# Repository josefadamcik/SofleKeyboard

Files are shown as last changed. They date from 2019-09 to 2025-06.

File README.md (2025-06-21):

# Sofle Keyboard

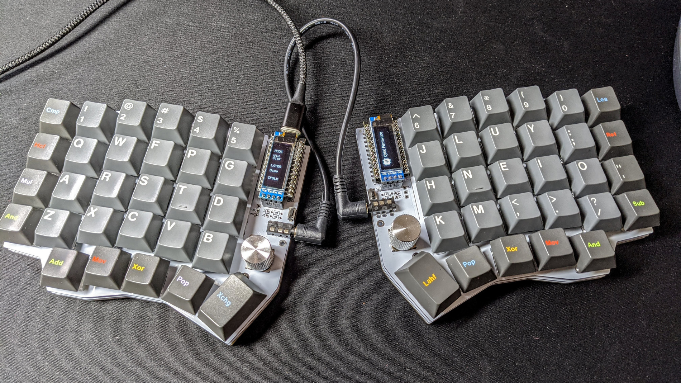
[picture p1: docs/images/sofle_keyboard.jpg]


Sofle is 6×4+5 keys column-staggered split keyboard with encoder support. Based on [Lily58](https://github.com/kata0510/Lily58), [Corne](https://github.com/foostan/crkbd) and [Helix](https://github.com/MakotoKurauchi/helix) keyboards.

**[For more information and documentation visit https://josefadamcik.github.io/SofleKeyboard/](https://josefadamcik.github.io/SofleKeyboard/)**

SofleKeyboard was created by [Josef Adamcik](https://josef-adamcik.cz/). The motivation and process is covered in following blog-post: [Let me introduce you SofleKeyboard - a split keyboard based on Lily58 and Crkbd](https://josef-adamcik.cz/electronics/let-me-introduce-you-sofle-keyboard-split-keyboard-based-on-lily58.html)



Sofle RGB was contributed by [Dane Evans](https://github.com/DaneEvans).

Sofle soldered was contributed by [kb-elmo](https://github.com/kb-elmo)

Sofle Pico was contributed by [Ryan Neff](https://github.com/JellyTitan)

## Firmware 

Sofle uses [QMK firmware](https://qmk.fm/)

## Default layout 

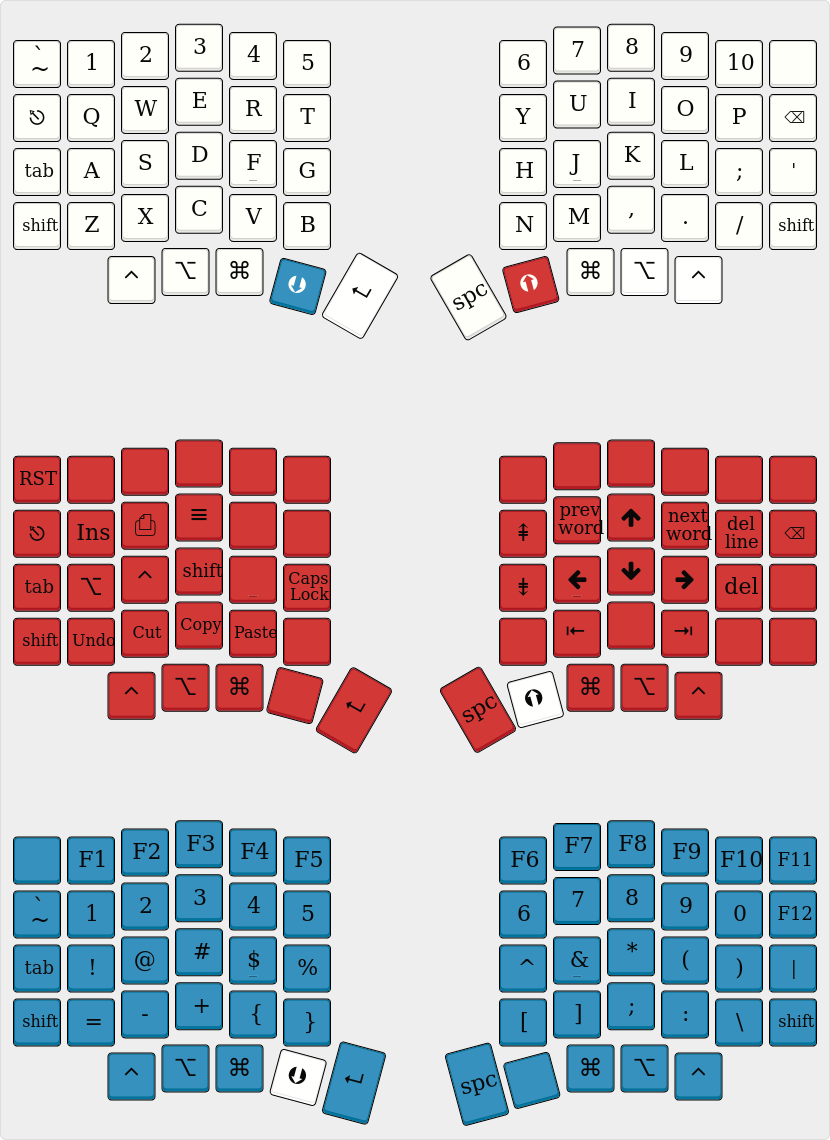
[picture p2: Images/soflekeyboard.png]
Default layout for SofleKeyboard


## Images of keyboard

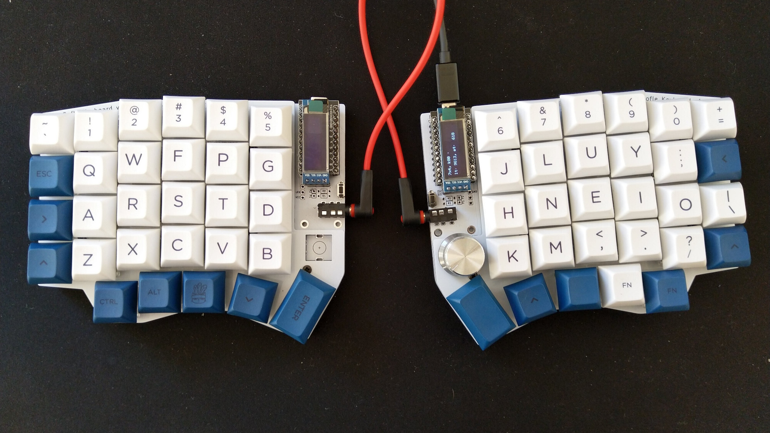
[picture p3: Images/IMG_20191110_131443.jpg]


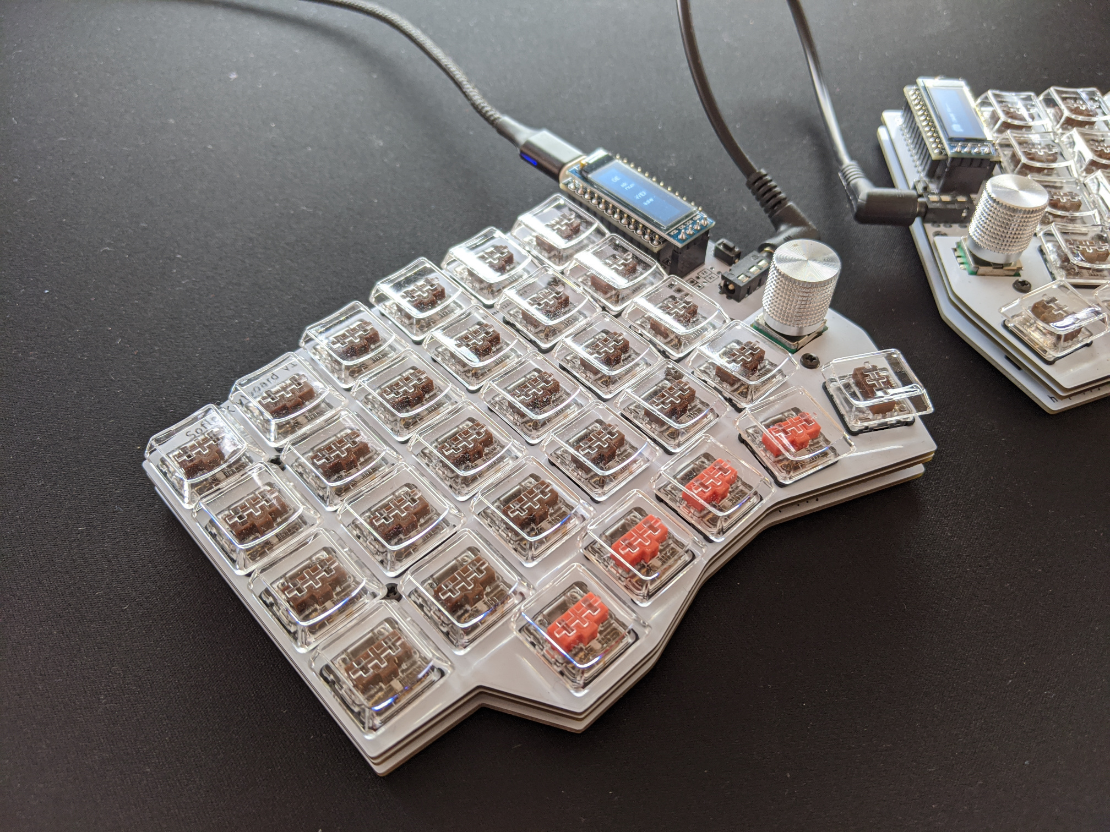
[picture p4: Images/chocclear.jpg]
SofleKeyboard Choc


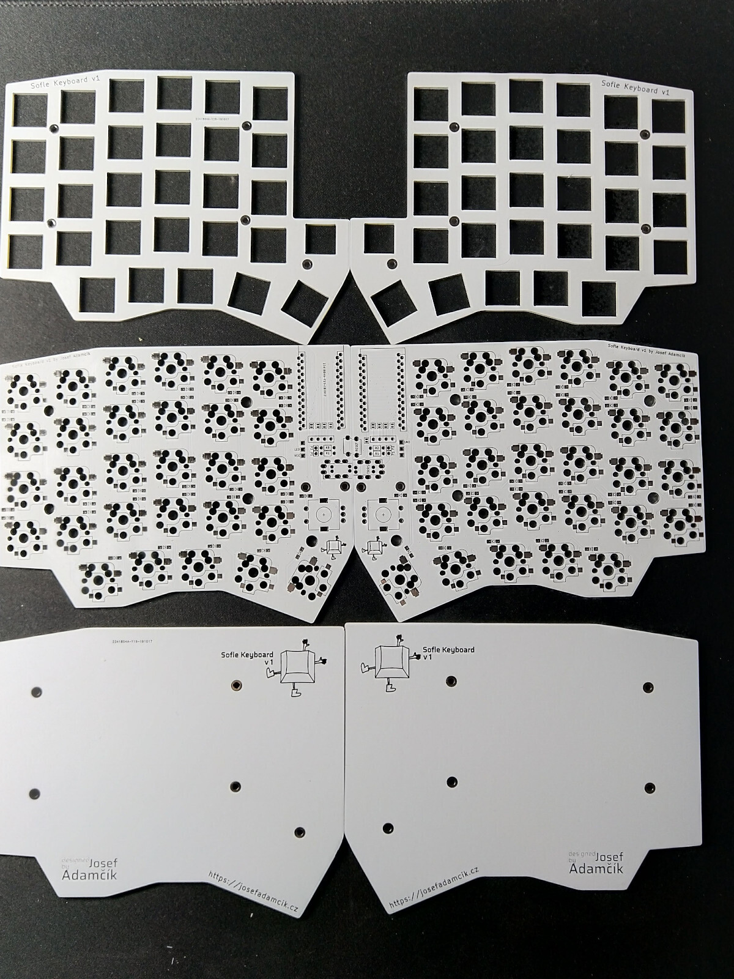
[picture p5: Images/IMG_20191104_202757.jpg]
SofleKeyboard PCB


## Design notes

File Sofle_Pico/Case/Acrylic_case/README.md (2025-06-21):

The documentation for this case can be found at https://www.soflepico.com/cases/fdm-case.html

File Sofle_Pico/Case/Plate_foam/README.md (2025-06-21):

The documentation for this case can be found at https://www.soflepico.com/cases/plate-foam.html

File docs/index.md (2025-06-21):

---
layout: default
---

SofleKeyboard

Sofle is 6×4+5 keys column-staggered split keyboard with encoder support. Based on [Lily58](https://github.com/kata0510/Lily58), [Corne](https://github.com/foostan/crkbd) and [Helix](https://github.com/MakotoKurauchi/helix) keyboards. SofleKeyboard version 1 and 2 were created by [Josef Adamcik](https://josef-adamcik.cz/). Sofle RGB was contributed by [Dane Evans](https://github.com/DaneEvans).

[Build guide is available here]({{ baseurl }}/SofleKeyboard/build_guide.html).

If you are interested in building the board and don't want to bother with KiCad, the gerber files are available in [releases](https://github.com/josefadamcik/SofleKeyboard/releases) or as [zip files in github repository](https://github.com/josefadamcik/SofleKeyboard/tree/master/Gerbers)

## Versions 

### Version 1

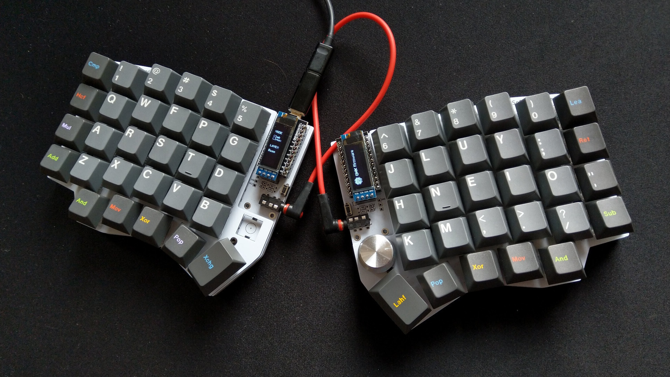
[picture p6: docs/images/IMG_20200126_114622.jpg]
SofleKeyboard v1


The first version is mostly a modification of Lilly58 Pro. Motivation and detailed information is covered in the following blog-post: [Let me introduce you SofleKeyboard - a split keyboard based on Lily58 and Crkbd](https://josef-adamcik.cz/electronics/let-me-introduce-you-sofle-keyboard-split-keyboard-based-on-lily58.html). 

There were several group buys and PCBs or kits were available through several sellers. 

[Build guide is available here]({{ baseurl }}/SofleKeyboard/build_guide.html).

### Version 2

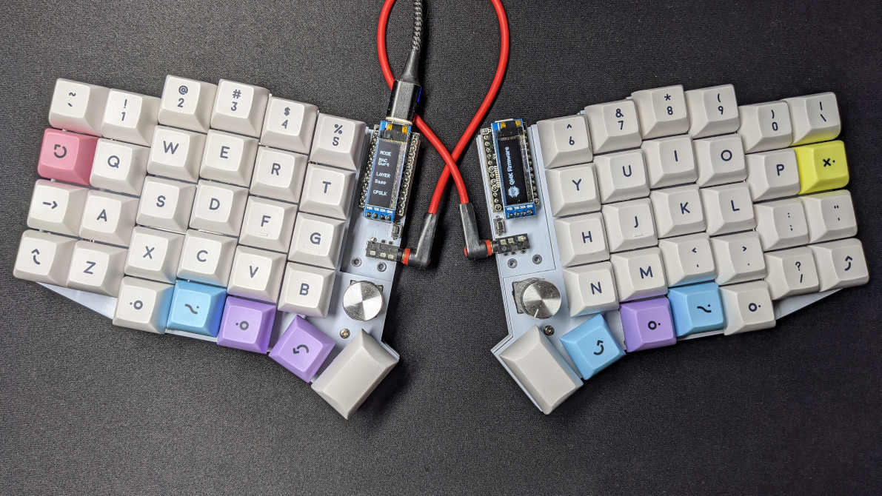
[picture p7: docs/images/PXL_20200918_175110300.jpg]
SofleKeyboard v1 and v2


Changes a stagger of columns and position of the bottom row a bit. The whole board was rerouted, shape changed slightly. Below version 1 in yellow, version 2 in blue.

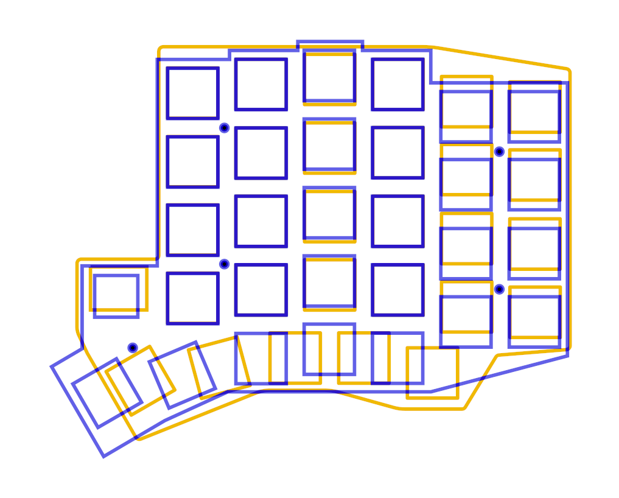
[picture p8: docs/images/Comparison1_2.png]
SofleKeyboard v1/v2 layout comparison


A few experiments were made:

- A differently mounted micro-controllers with staggered holes.
- Placement of components around pro micros were also changed.
- Support for low profile Kailh Choc switches was dropped.

Those changes were experiments and I have been planning to reverse them and/or tweak them more. Details in the following blog-post: [Sofle Keyboard evolution: slow and not really steady](https://josef-adamcik.cz/electronics/soflekeyboard-evolving.html). 

Since the development was not moving forward for several months and there were many people interested in the new layouts (including group buys and vendors willing to sell kits), it was decided to release it in the current state as the version 2. Only one obvious problem was fixed (a too small size of a cut-out for encoder in the top plate).

[Build guide is available here]({{ baseurl }}/SofleKeyboard/build_guide.html).

### RGB

**&#9888; If you bought Sofle RGB from Keyhive, see the disclamer below, please.**

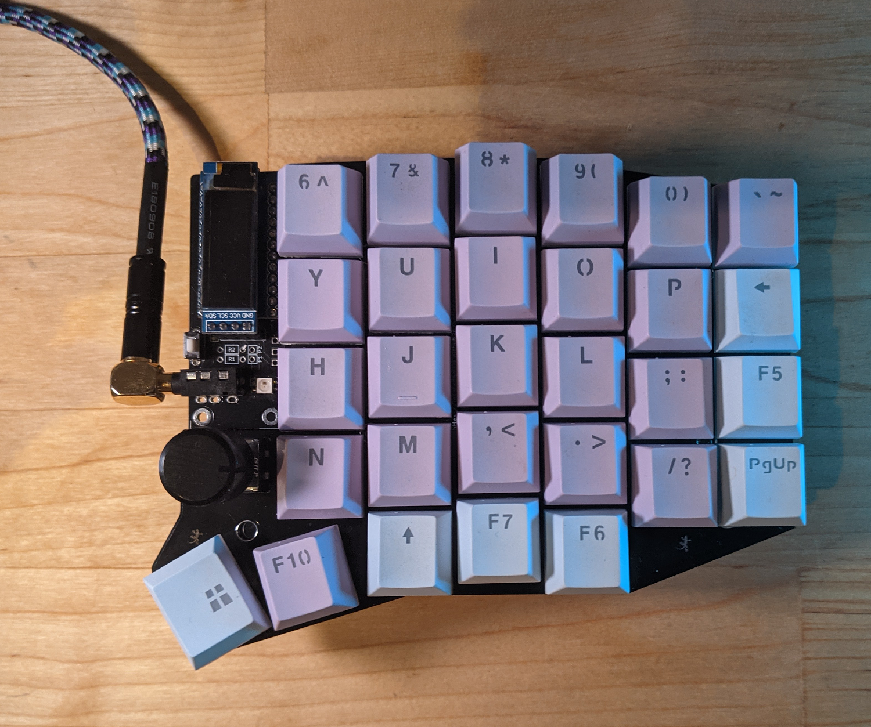
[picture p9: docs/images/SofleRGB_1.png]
SofleKeyboard RGB


Sofle RGB was contributed by [Dane Evans](https://github.com/DaneEvans).

The Sofle RGB is a copy of the Sofle v2 with the addition of up to 36 RGB LEDs per side. If you are just looking to try out that layout, and are using the cherry sockets only, then this will work for you. 

The original pro-micro pinout was rolled back and routing was redone.

The OLED placement and OLED cover plate holes have not changed, and a plate has been designed. 

[Build guide is available here]({{ baseurl }}/SofleKeyboard/build_guide_rgb.html).

###	&#9888; Keyhive RGB

One keyboard vendor - Keyhive - is selling their own fork of Sofle RGB. This version is **modified** in way that makes it **incompatible** with the firmware for the official designs. You have to use the firmware provided by the vendor and build guide provided by them as well. Please, don't report problems with the desing and or firmware to this repository. Their modification is not part of the repository and therefore we cannot fix the problems or help you. Contact the vendor instead. In the end, you are their client.

[Build guide is available here]({{ baseurl }}/SofleKeyboard/build_guide_rgb.html).

### Choc

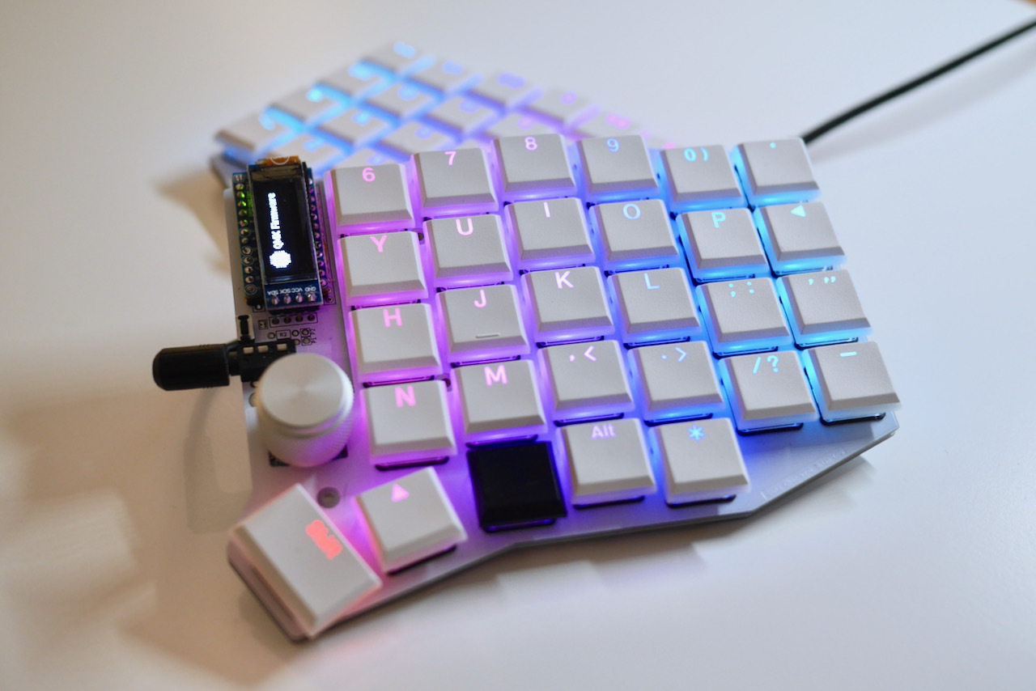
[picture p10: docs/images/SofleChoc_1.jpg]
Sofle Choc


The Sofle Choc is a variation of the Sofle with:

   - low-profile, Kailh Choc switches
   - hotswap sockets
   - per-key RGB
   - thin, 15mm from desktop to top of keycaps
   - Sofle RGB switch layout with pinky stagger in between v1 and v2

The Sofle Choc was contributed by [Brian Low](https://github.com/brianlow) and based on the excellent Sofle RGB by [Dane Evans](https://github.com/DaneEvans).

[Build guide is available here]({{ baseurl }}/SofleKeyboard/build_guide_choc.html).

### Pico

Sofle Pico

The Sofle Pico is based largely on the Sofle V2 switch layout, and rebuilt specifically for the RP2040 Pico MCU. 

   - MX switch hotswap sockets (does _not_ support choc switches).
   - per-key RGB
   - 64x128 OLED's
   - through-hole or SMD diodes for easier soldering
   - RP2040 'drag and drop' flashing
   - VIA support
   - tenting puck mounting holes
   - patch bay for easy tinkering

Sofle Pico was contributed by [Ryan Neff](https://github.com/JellyTitan).

[Build guide is available here](https://www.soflepico.com).

## Modifications

- [Sofle V2 with RJ12 instead of TRRS](https://gitlab.com/LayeredRx/Sofle_V2_Rj12/) by Layered RX

## License

- Hardware source files are licensed under MIT license.
- The documentation (both on [josefadamcik.github.io/SofleKeyboard/](https://josefadamcik.github.io/SofleKeyboard/) and [https://josef-adamcik.cz/](https://josef-adamcik.cz/)) is licensed under [Creative Commons Attribution 4.0 International (CC BY 4.0)](https://creativecommons.org/licenses/by/4.0/) license. This includes all photos and images in this repository and on the website.
- Firmware is part of QMK firmware and has the same licence (GPL v2)

## Firmware 

Sofle uses [QMK firmware](https://qmk.fm/)

See the [build environment setup](https://docs.qmk.fm/#/getting_started_build_tools) and the [make instructions](https://docs.qmk.fm/#/getting_started_make_guide) for more information. Brand new to QMK? Start with our [Complete Newbs Guide](https://docs.qmk.fm/#/newbs).

Make example for this keyboard (after setting up your build environment):

    make sofle:default

Flash the default keymap: 

    make sofle:default:avrdude

Press reset button on he keyboard when asked.

Disconnect the first half, connect the second one and repeat the process.

You can also use [QMK configurator](https://config.qmk.fm/#/sofle/rev1/LAYOUT) but beware, it does not support rotary encoders yet.

## Default layout 

Default layout for SofleKeyboard

## Gallery

Version 1 at the top, version 2 at the bottom:

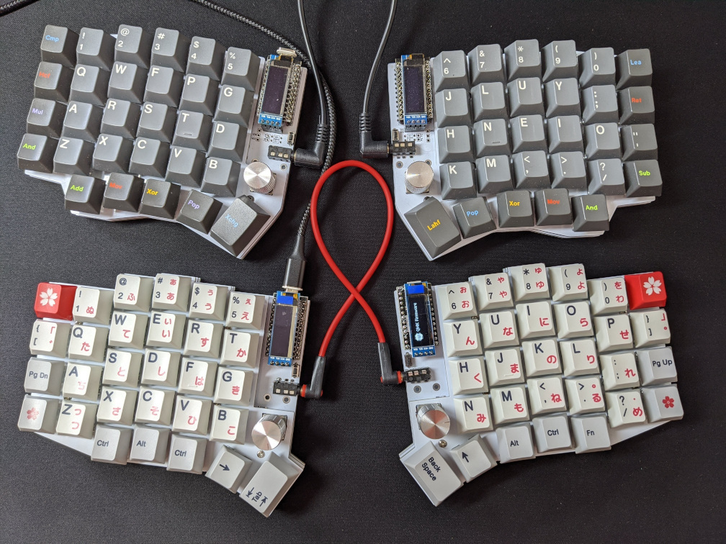
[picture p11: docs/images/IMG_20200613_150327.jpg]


### Version 1

SofleKeyboard

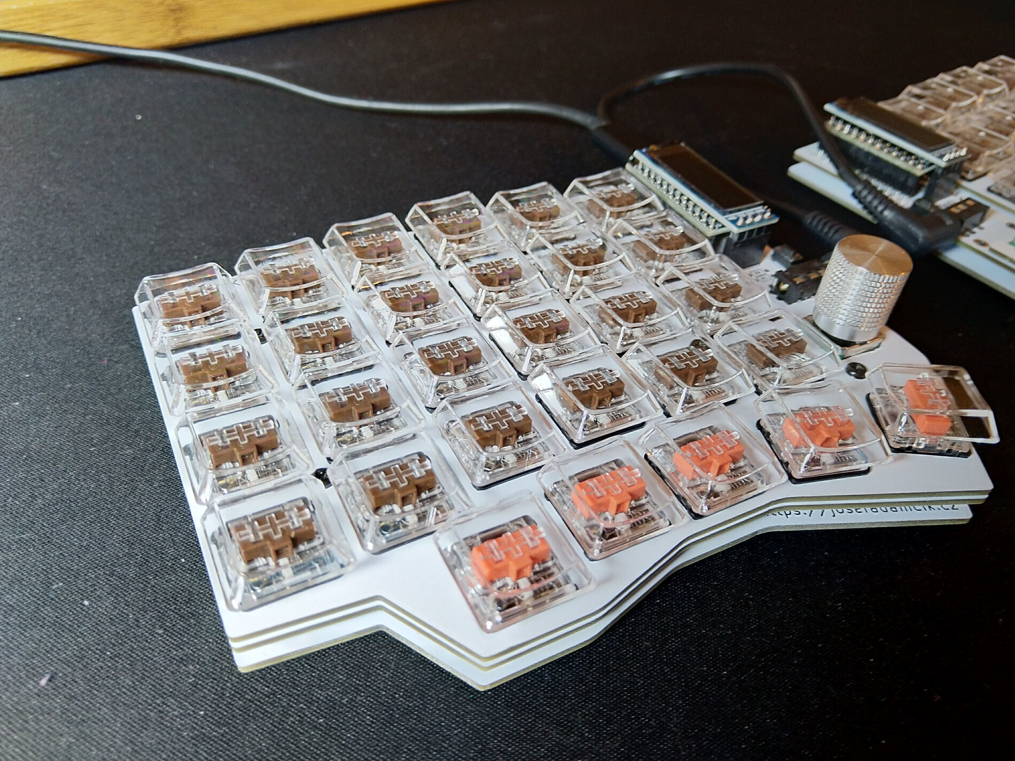
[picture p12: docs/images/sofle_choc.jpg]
SofleKeyboard Choc


SofleKeyboard PCB

### RGB

SofleRGBKeyboard

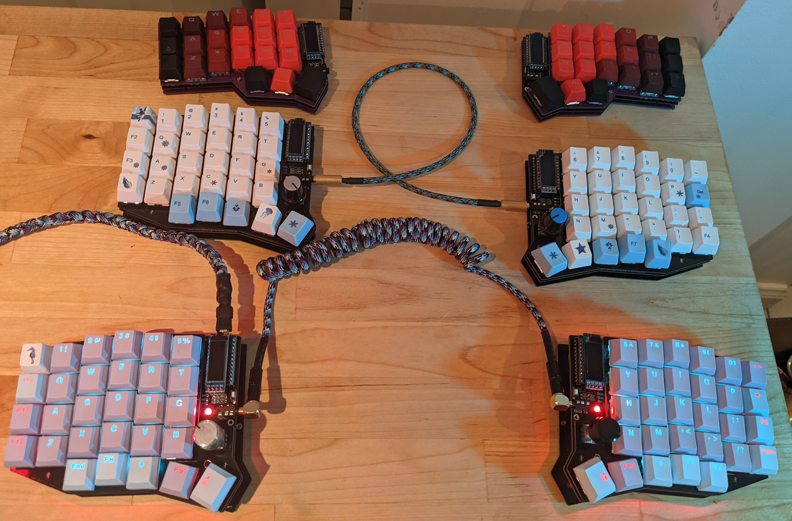
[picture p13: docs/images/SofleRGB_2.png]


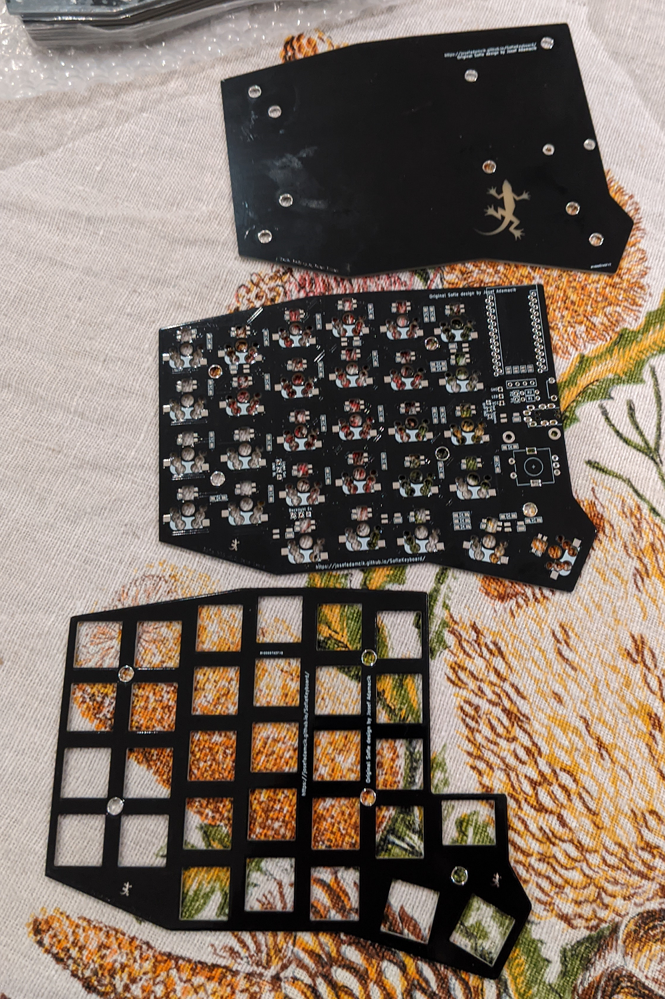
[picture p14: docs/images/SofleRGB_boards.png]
SofleRGBKeyboard PCB


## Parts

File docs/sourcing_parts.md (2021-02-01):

---
layout: default
title: Sofle Keyboard - sourcing parts
---

Sofle Keyboard is supposed to be simple DIY keyboard so it's possible to source all the parts yourself starting with PCBs, case plates and ending with every component on the board. In the case of PCBs and plates it might be more cost effective to buy them through a vendor but it's possible to go through manufacturing process as well. For the remaining components, most of them can be bought on Ebay on Aliexpress but buying a kit might be handy.

## Vendors

There are some vendors who are or were selling Sofle PCBs and/or kits. Things change over time so just google around and you may have luck finding someone.

## PCB manufacturing

If you decide that you wish to go through the PCB manufacturing process, you can. I should be easy enough even for people who don't know much about PCB manufacturing process. But keep in mind, nobody can guarantee that there are not going to be some problems and if you have no idea what are you doing it might be more difficult to deal with any issues along the way. 

### Getting Gerber files

The shortest way is to grab the [Gerber files for SofleKeyboard from releases Github][soflegerber].

You can also get source [KiCad projects on Github][soflegithub]. Open them in KiCad, plot Gerber files and drill files, compress them into a zip file. The instructions how the extract Gerber files from KiCad are everywhere and you can find them e.g. at the website of your chosen manufacturer. 

### Manufacturing

You should have 3 zip files which you need to upload/send to your manufacturer and have them made. There should be nothing special about the parameters you pick for manufacturing: 2-sided PCB, thickness 1.6 mm. Surface finish (keep in mind that the cheapest HASL contains lead. Lead is toxic. Consider using lead-free version and lead-free solder) and solder-mask color according to your taste. Other parameters could stay in their default values. You are going to need at least 2 pieces of PCB made from each zip file. Most likely the minimal quantity is going to be either 5 or 10 boards.

## Microcontroller boards

- [Original Pro Micro by SparkFun][promicroorig]. 
- [Clone from AliExpress][promicro]

Another alternative would be to use Elite-C which is a board using the same microcontroller as Pro Micro but with USB-C designed and made for DIY keyboards by [keeb.io][keebioelite]

### Sockets and pin headers for Pro Micro 

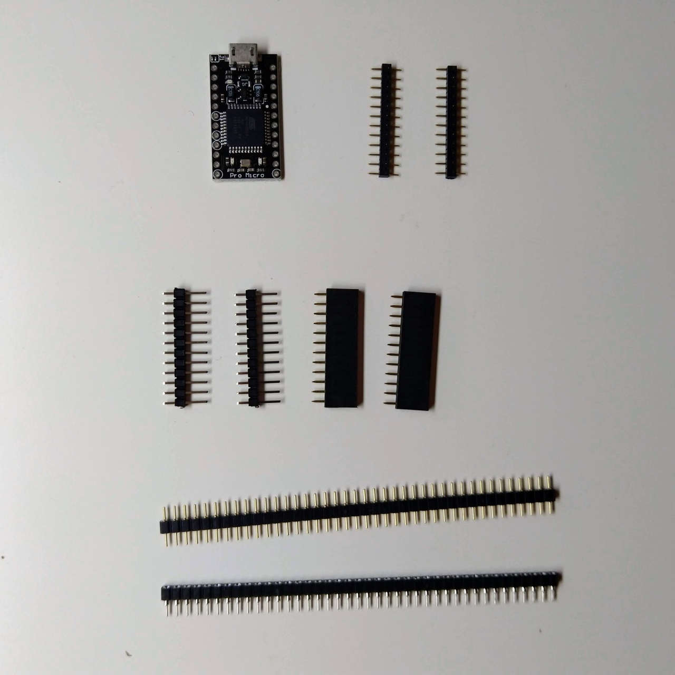
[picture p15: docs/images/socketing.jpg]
sockets


There are several ways how to mount Pro Micros to the board. Either the male PIN headers you most likely got with the board from the supplier could be used to solder it directly to the board or with high profile female pin headers (on the image in the middle.)

Build guides for Helix, Corne and Lily58 suggest [those spring pin headers][springpinheader](on the image at the top) which are very compact and give you non-permanent connection (you can remove or replace Pro Micros). But the link goes to a Japanese e-shop which is not shipping to Europe. ~~I haven't found any other place where those are available. All I can find is Japanese datasheet and this e-shop.~~ They were [briefly available at keycapsss.com][keycapsssockets] but at the time of writing they were already sold-out.

I ended up using low-profile round pin headers (on the image at the bottom) which take a bit more height but also allow me to remove Pro Micros and use them elsewhere. But for Corne, I just soldered them permanently. Here are [female ones][roundpinfemale] (soldered to board) and [male ones][roundpinmale] (soldered to Pro-Micro)

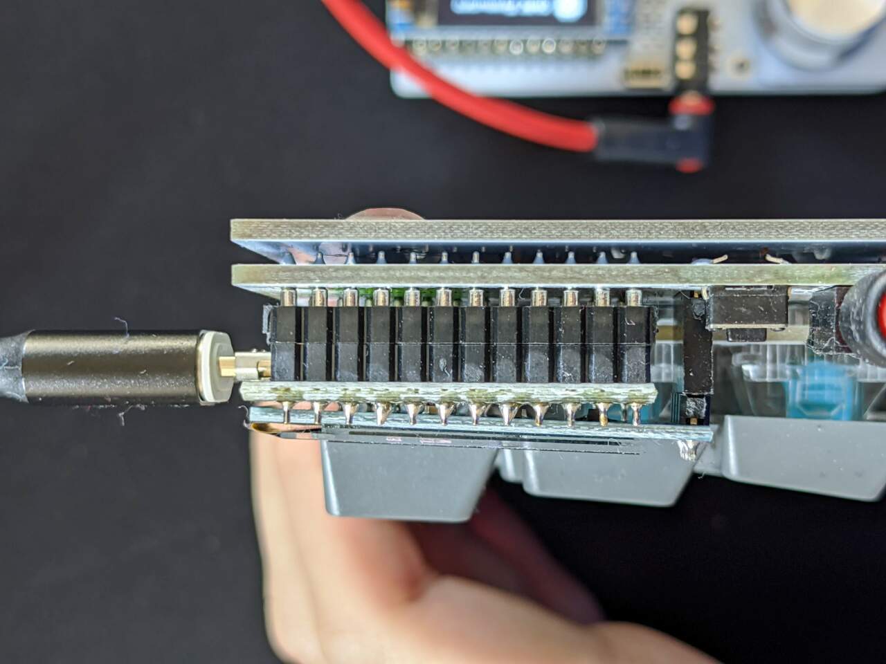
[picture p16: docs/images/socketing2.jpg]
sockets 2


Another possible approach [is described at splitkb.com][promicrosocketing].

## Other parts

Bill of materials is part of the [build guide][buildguide].

Apart from encoders and encoder knobs the parts are exactly the same as for Lilly58. So you can try to find someone who is selling a bit for Lilly58 without PCBs. You can also look for parts at eshops which sell stuff for similar DIY keyboards (Corne, Lilly58a and similar). For example an EU based vendor [keycapsss][keycapsss] has a pretty nice stock

Most of the links below are to AliExpress and usually are the same I have ordered and used. They are meant for illustration. They are not affiliate links. It seems AliExpress is going to require you to be registered and logged in to see the detail of the product. I discovered that when putting this together and I am sorry for that but it's out of my control. 

- [Kailh MX Socket (AliExpress)][kailhsocketmx] 
- [Kailh Choc Socket (AliExpress)][kailhsocketchoc]
- [1N4148W Diodes in SOD123 package (AliExpress)][diodes]
- [TRRS connectors (AliExpress)][trrs]
- [Tactile button THT 2 pins][thtbuttons]
- [M2 brass spacers kit (AliExpress)][spacers] 
- [Adhesive rubber feet (AliExpress)][rubberfeet]
- [OLED display breakout (AliExpress)][oled]
- [EC11 rotary encoder (AliExpress)][encoder]
- [Encoder knob (AliExpress)][encoderknob]

[soflegerber]: https://github.com/josefadamcik/SofleKeyboard/releases "SofleKeyboard - gerber files"
[zilentsv2]: https://zealpc.net/products/zilents "Zilent V2 silent taktile switches by ZealPC"
{:target="_blank"}
[promicroorig]: https://www.sparkfun.com/products/12640 "Pro Micro by SparkFun"
{:target="_blank"}
[choc]: http://www.kailh.com/en/Products/Ks/CS/ "low profile switches from Kailh"
{:target="_blank"}
[trrs]: <https://www.aliexpress.com/item/32869968774.html> "TRRS conectors on Aliexpress"
{:target="_blank"}
[buttons]: <https://www.aliexpress.com/item/32981768203.html> "Buttons on Aliexpress"
{:target="_blank"}
[spacers]: <https://www.aliexpress.com/item/32974970926.html> "Brass spacers on AliExpress"
{:target="_blank"}
[rubberfeet]: <https://www.aliexpress.com/item/32839661456.html> "Rubber feet on Aliexpress"
{:target="_blank"}
[oled]: <https://www.aliexpress.com/item/32712441521.html> "OLED on AliExpress"
{:target="_blank"}
[promicro]: <https://www.aliexpress.com/item/32849563958.html> "ProMicro clone on AliExpress"
{:target="_blank"}
[springpinheader]: <https://yushakobo.jp/shop/a01mc-00/> "Spring pin headers - Japaneese"
{:target="_blank"}
[qmkprotonc]: https://qmk.fm/proton-c/ "QMK Proton-C"
{:target="_blank"}
[promicrosocketing]: <https://docs.splitkb.com/hc/en-us/articles/360011263059> "How do I socket a microcontroller? by splitkb.com"
{:target="_blank"}
[kailhsocketmx]: <https://www.aliexpress.com/item/32951252318.html> "Kailh MX sockets"
{:target="_blank"}
[kailhsocketchoc]: <https://www.aliexpress.com/item/33023283633.html> "Kailh Choc Sockets"
{:target="_blank"}
[diodes]: <https://www.aliexpress.com/item/32334222067.html> "1N4148W SOD123"
{:target="_blank"}
[encoder]: <https://www.aliexpress.com/item/4000891003225.html> "Encoder"
{:target="_blank"}
[encoderknob]: <https://www.aliexpress.com/item/2028814958.html> "Encoder Knob"
{:target="_blank"}
[thtbuttons]: <https://www.aliexpress.com/item/32981768203.html> "Tactile button"
{:target="_blank"}
[qmkintro]: <https://beta.docs.qmk.fm/newbs/newbs_getting_started> "QMK getting started"
{:target="_blank"}
[qmkhandedness]: <https://beta.docs.qmk.fm/features/feature_split_keyboard#setting-handedness> "QMK firmware - setting handedness"
{:target="_blank"}
[nooledlag]: https://github.com/qmk/qmk_firmware/issues/7522 "No OLED lag bug"
[soflegithub]: https://github.com/josefadamcik/SofleKeyboard "SofleKeyboard - KiCad project on Github.com"
[buildguide]: <{{ site.baseurl }}/build_guide.html> "Build guide"
[keycapsss]: <https://keycapsss.com/keyboard-parts/parts/?p=1> "Keycapsss - parts" 
{:target="_blank"}
[keycapsssockets]: <https://keycapsss.com/keyboard-parts/parts/91/spring-loaded-pin-headers-12-pin-2pcs-conthrough?c=11> "Keycapss - spring loaded pin headers."
{:target="_blank"}
[roundpinmale]: <https://www.aliexpress.com/item/32803164240.html> "Round pin header male"
{:target="_blank"}
[roundpinfemale]: <https://www.aliexpress.com/item/32817226478.html> "Round pin header female"
{:target="_blank"}
[keebioelite]: <https://keeb.io/products/elite-c-usb-c-pro-micro-replacement-arduino-compatible-atmega32u4> "Elite-C"

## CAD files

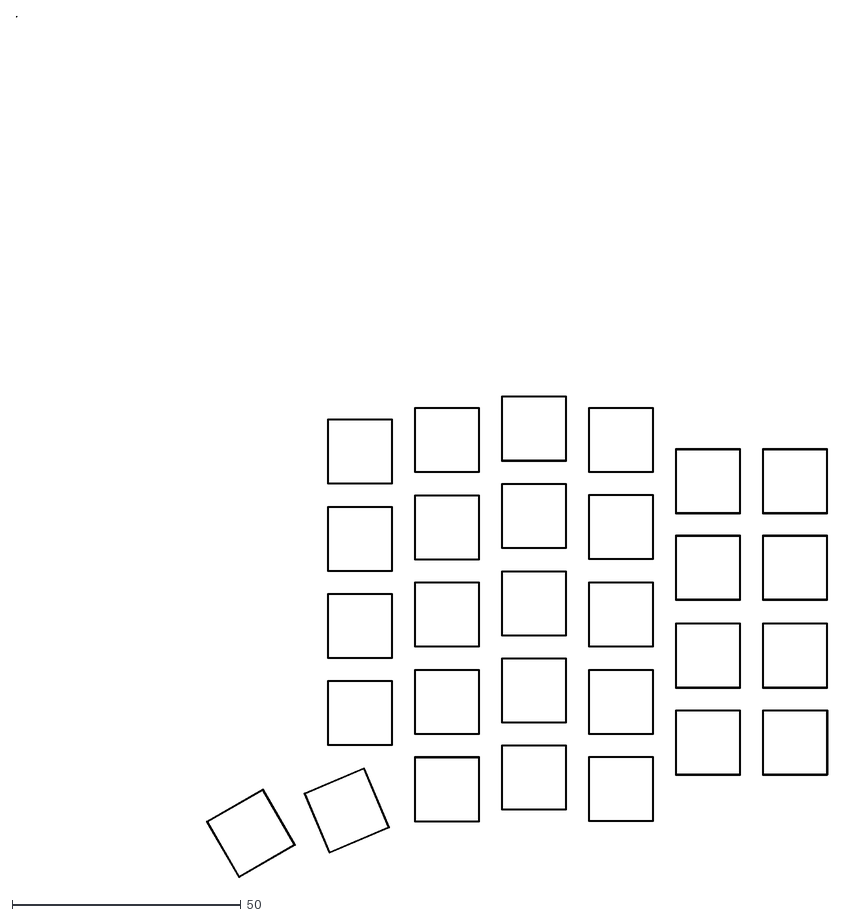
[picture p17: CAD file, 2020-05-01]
Design/v2/SofleKeyboard-Eco2_User.dxf
177.2 x 188.0

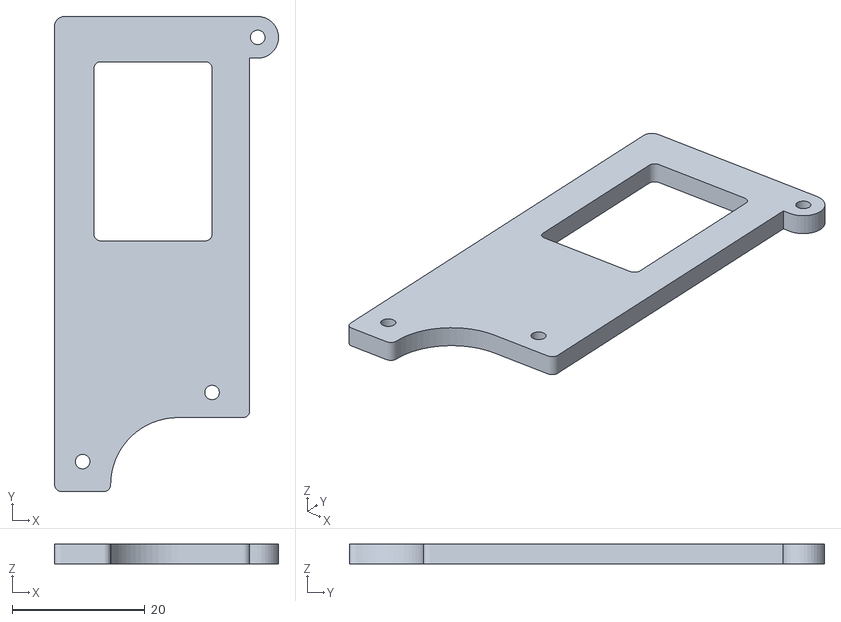
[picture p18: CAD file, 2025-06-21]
Sofle_Pico/Case/3d_printable_case/production_ready/Sofle_pico_OLED_circle_window_v3.4.stl
33.7 x 71.5 x 3.00

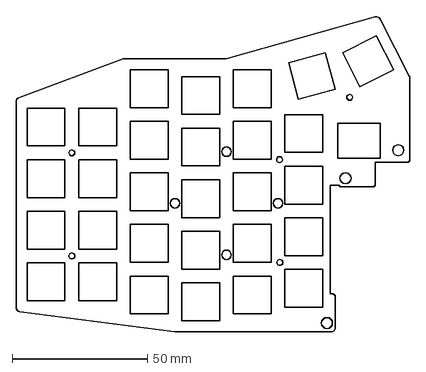
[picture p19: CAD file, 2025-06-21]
Sofle_Pico/Case/Acrylic_case/source/sofle_pico_key_plate_v3.5.5.dxf
145.4 x 116.4 mm

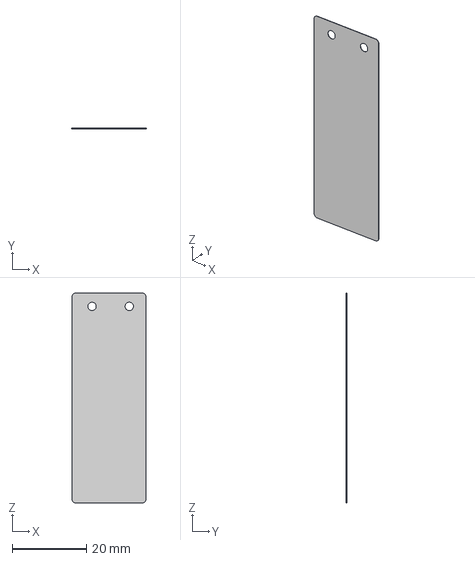
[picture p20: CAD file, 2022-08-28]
Sofle_v2_soldered/Case/sofle_v2_oled_cover_0.1.step
19.9 x 0.1 x 56.5 mm

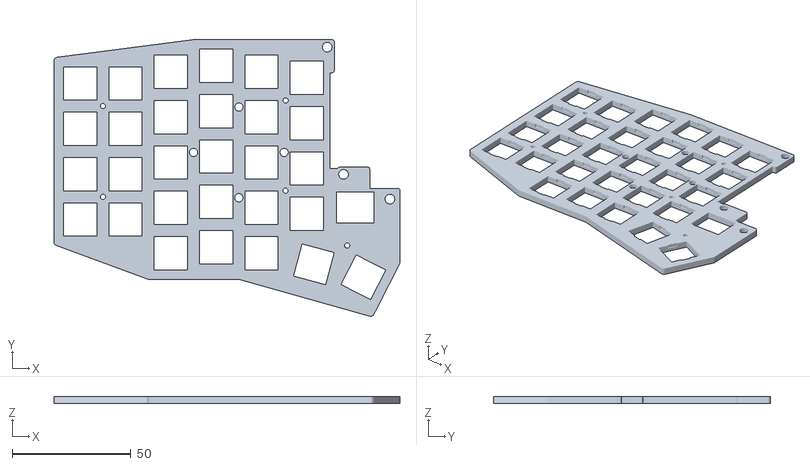
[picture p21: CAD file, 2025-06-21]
Sofle_Pico/Case/3d_printable_case/production_ready/sofle_pico_keyplate_notched_RH.stl
145.4 x 116.3 x 3.00

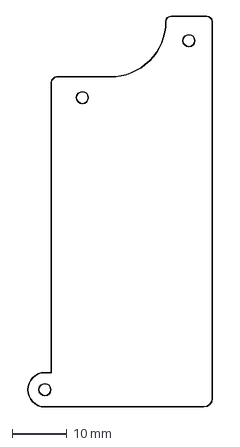
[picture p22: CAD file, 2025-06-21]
Sofle_Pico/Case/Acrylic_case/source/sofle_pico_OLED_v3.4.dxf
33.7 x 71.5 mm

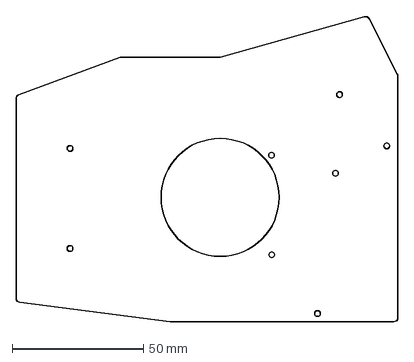
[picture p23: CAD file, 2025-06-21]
Sofle_Pico/Case/Acrylic_case/source/sofle_pico_backplate_v3.4.dxf
145.4 x 116.4 mm

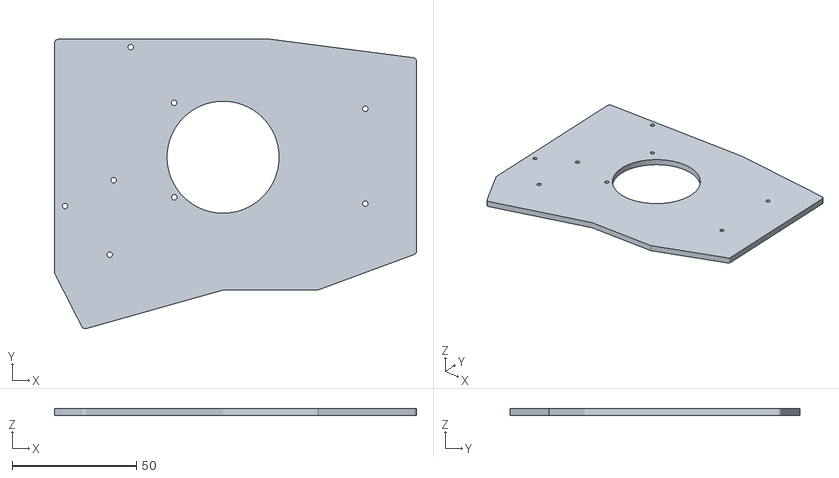
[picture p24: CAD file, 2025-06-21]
Sofle_Pico/Case/3d_printable_case/production_ready/sofle_pico_backplate_v3.4.stl
145.4 x 116.3 x 3.00

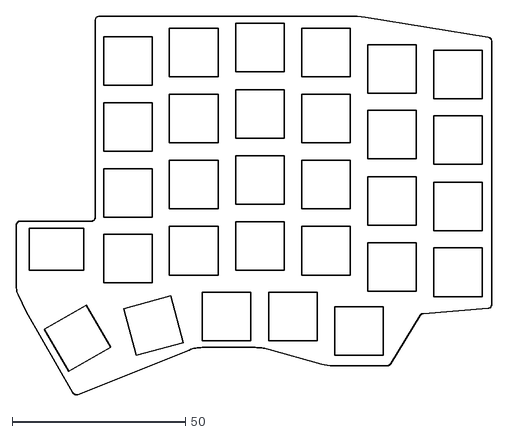
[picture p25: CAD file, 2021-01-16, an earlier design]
Design/v1/SofleKeyboardTopPlate_ShapeOnly.dxf
137.2 x 109.2

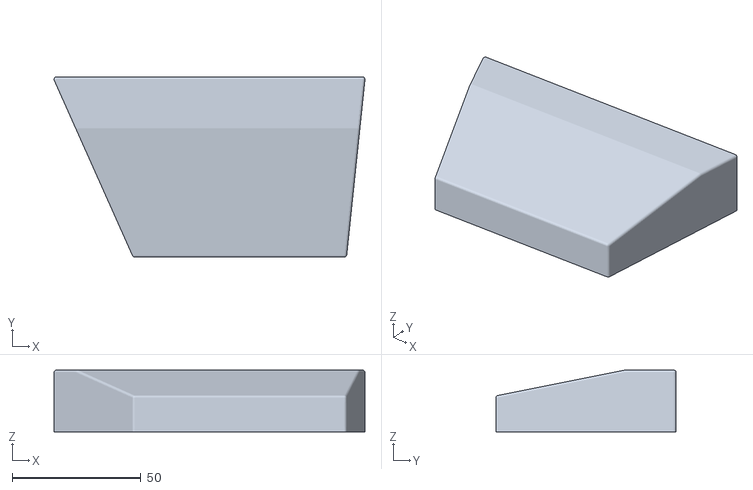
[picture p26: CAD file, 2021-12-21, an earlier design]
Sofle_v1/Case/3D_Print/soflekeyboard-palm-L.stl
120.7 x 70.0 x 24.0

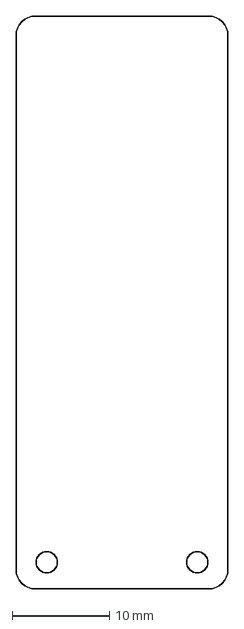
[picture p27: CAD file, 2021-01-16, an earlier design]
Sofle_v1/Case/OLED_Cover.dxf
21.8 x 59.0 mm

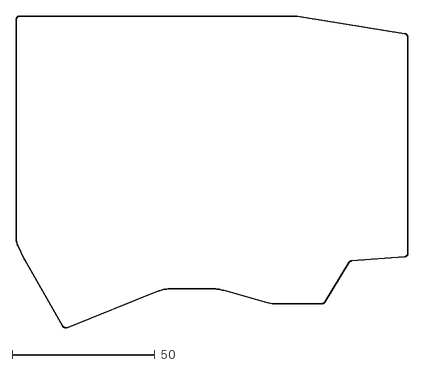
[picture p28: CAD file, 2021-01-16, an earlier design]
Design/v1/SofleKeyboardBottomPlate_ShapeOnly.dxf
137.2 x 109.2

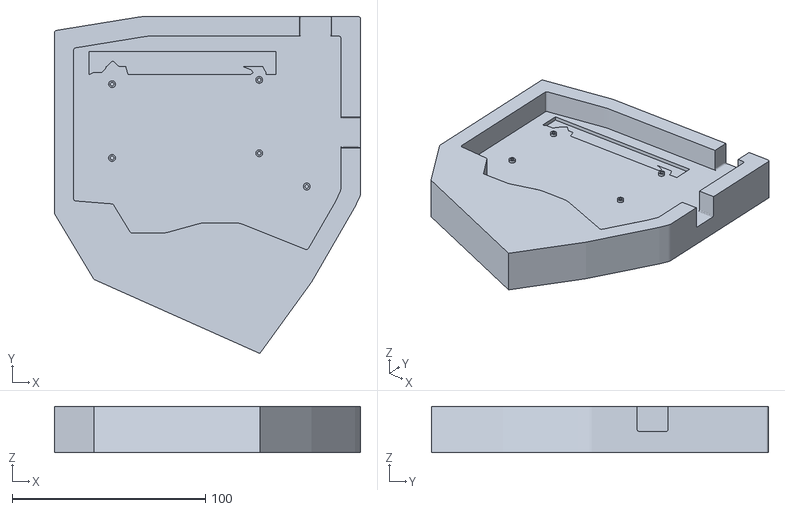
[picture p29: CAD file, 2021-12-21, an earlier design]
Sofle_v1/Case/3D_Print/soflekeyboard-case-L.stl
158.6 x 174.5 x 24.0

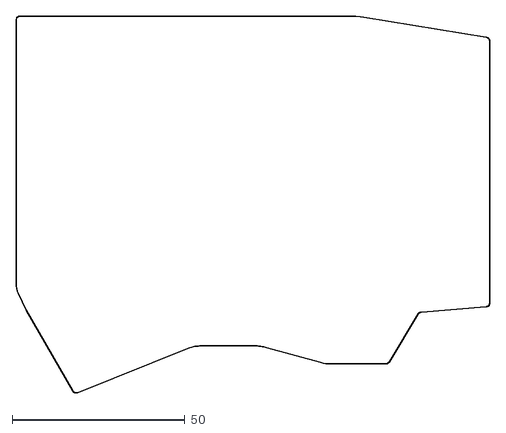
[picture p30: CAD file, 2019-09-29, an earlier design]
Design/v1/shape.dxf
137.2 x 109.2

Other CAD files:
Sofle_Pico/Case/3d_printable_case/production_ready/Sofle_pico_OLED_oval_window_v3.4.stl
Sofle_Pico/Case/3d_printable_case/production_ready/sofle_pico_keyplate_notched_LH_v3.5.5.stl
Sofle_v1/Case/3D_Print/soflekeyboard-case-R.stl
Sofle_v1/Case/3D_Print/soflekeyboard-palm-r.stl
Sofle_Pico/Case/3d_printable_case/source/Sofle_Pico_v3.5.5_fdm_notched_plates.f3d
Sofle_Pico/Case/3d_printable_case/source/Sofle_pico_v3.4_Acrylic_case v20.f3d
Sofle_v2_soldered/Case/sofle_v2_oled_cover_0.1.dxf
Sofle_v2_soldered/Case/sofle_v2_oled_cover_0.1.f3d

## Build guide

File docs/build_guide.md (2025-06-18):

---
layout: default
title: Sofle Keyboard - build guide (v1/v2)
---

This guide suits both version **V1** and **V2** of the standard (**non-RGB**) Sofle Keyboard. Most of the photos are for v1 and the differences are explained in the text as needed.

The **RGB** version has [dedicated build guide][rgbbuildguide].

The **Choc** version has [dedicated build guide][chocbuildguide].

If you don't have all the necessary parts, please read about [how to source the parts][sourcing].

## Bill of materials

The following is needed to build the keyboard. You can find [links for the most of the components in the sourcing parts section][sourcing].

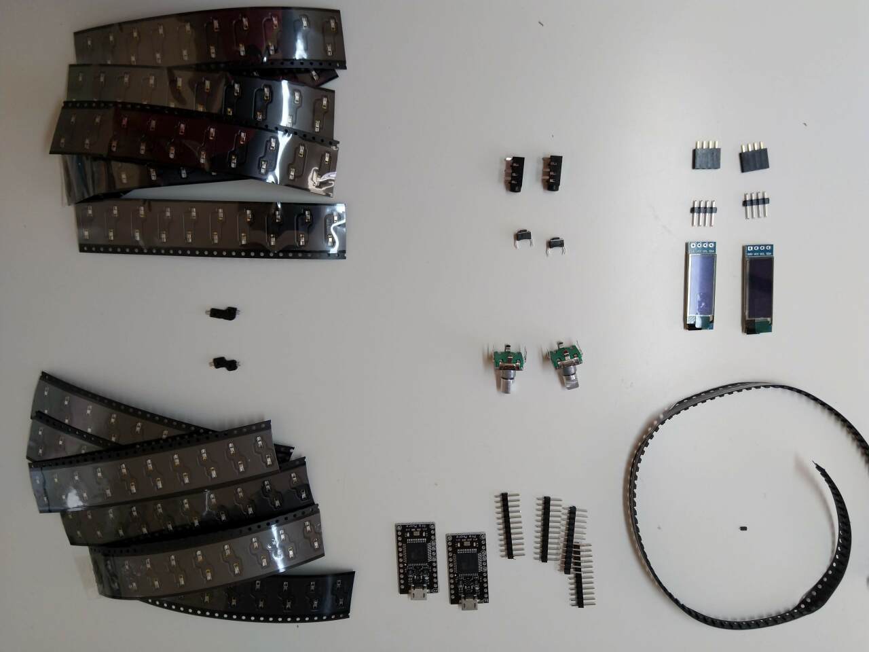
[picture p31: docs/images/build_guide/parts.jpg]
SofleKeyboard parts


- **2 PCBs** (see [sourcing][sourcing])
- **2 top plates**, **2 bottom plates** for a sandvich-case build. (see [sourcing][sourcing])
- **58 keyboard switch sockets by Kailh**. The PCB supports either sockets for traditional MX switches or sockets for Kailh Choc switches. **Note that version 2 supports only MX.** They are available on Aliexpress, KBDFans and others. 
- **58 keyboard switches** of your preference, either MX or [Kailh Choc][choc]. Just make sure you have matching sockets for them. **Note that version 2 supports only MX**.
- **58 keycaps**. You can use either all in `1u` size but it looks nicer with two `1.5u` for the thumb keys.
- **58 diodes  1N4148W**. They are surface mount diodes in SOD123 package.
- **2 TRRS connectors PJ-320A**. The same type which is used for Corne, Lily58 etc. Technically even TRS should work[^1] if you stick to (default) serial communication. 
- **2 tactile buttons** through-hole, 2 pins. Technically optional: you can use metal tweezers whenever you need to reset the microcontroller. There's also a reset key on default layout so as long as you have firmware flashed and working you shouldn't need reset button on the board. 
- **1 TRRS cable**. TRS should work[^1] if you stick with Serial. 
- **10 (+4) M2 spacers**. 10 are going to hold the bottom and the top together. Their height depends on which switches you use. A build guide Lily58 Pro suggests `4mm` for Choc and `7mm` for MX. I was not able to get `7mm`, but `6mm` worked well for me with MX switches. I used brass ones but you can also buy nicer from anodised aluminium. Another 4 would be needed to hold transparent OLED cover but even though there are mounting holes in the PCB.
- **20 (+8) M2 screws**. 20 are going to hold the boards together (via spacers). I used some I had in my stock so I am not going to tell you exact length. But they need to be long enough to fix a `1.6mm` thick PCB to the spacer and short enough so two of them can fit in one spacer (might be trickier with 4mm spacers for Choc switches)
- **8 - 10 adhesive rubber feet**. They are really important, trust me.
- **2 ssd1306 128x32 OLED display module**. Very common everywhere. 
- **2 OLED covers** Optional. OLED cover should be cut from transparent acrylic. Source file for [version 1 is avalalble in the repostiory](https://github.com/josefadamcik/SofleKeyboard/tree/master/Sofle_v1/Case). There is no OLED cover for version 2 available yet.
- **2 Rotary encoders EC11**, optional. So far I have used only one but 2 are supported. If you are not sure take EC11E. Some other variants (EC11K) may have some additional plastic pins for and require mounting holes for them (which are not included on the PCB).
- **A matching knob** for each encoder. 
- **2 Pro Micro**board or clone. With 2x12 pins and ATmega32U4 microcontroller. Just make sure you **don't** buy something like Arduino Micro (a different pinout) or Arduino Mini (different microcontroller). You could also use Elite-C which basically Pro Micro with USB-C.
- **4x12 pin header (and optionally socket)** for Pro Micros. There are several ways how to mount Pro Micros to the board. Either the male PIN headers you most likely got with the board from the supplier could be used to solder it directly to the board. Build guides for Helix, Corne and Lily58 suggest [those spring pin headers][springpinheader] which are very compact and give you non-permanent connection (you can remove or replace Pro Micros). Another possible approach [is described at splitkb.com][promicrosocketing].
- **2x4 pin header (and optionally socket)** for OLEDs. I have used the most common 1x4 female pin sockets which are quite tall but they also fit the height of ProMicro with the sockets I have used. Unfortunately, the pin headers on my OLED modules (again those very common square male headers you would get with the modules) are loose in the sockets. It works but it's fiddly. I'll have to find a better solution.
- **Micro USB Cable** to connect the keyboard to a computer.

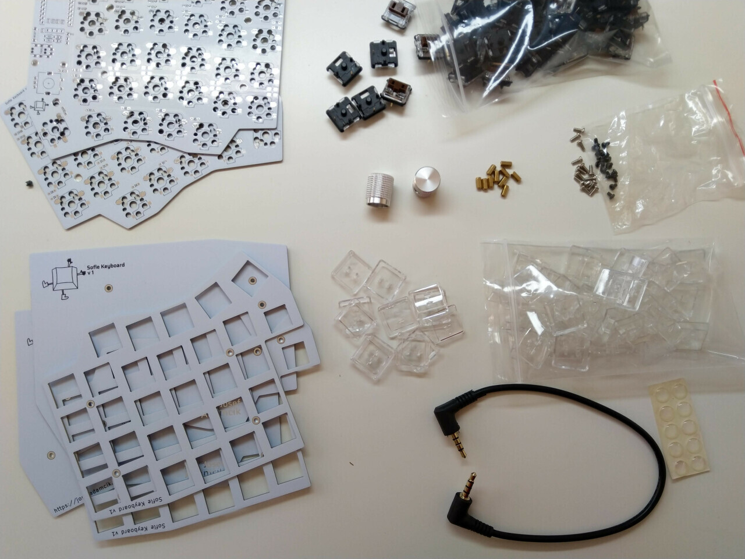
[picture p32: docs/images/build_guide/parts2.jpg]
SofleKeyboard parts 2


That's it. There are no RGB LEDs on the board. But if you really need underglow it is be possible to connect an RGB LED strip since there are 3 pads (VCC, GND and data) on the board. You would need to add support to the firmware on your own.

## Tools and materials

- soldering iron
- solder 
- good tweezers
- masking tape
- isopropyl-alcohol for cleaning 
- screwdriver

## Warnings and disclaimers

- Think twice, solder once. Desoldering is frustrating and it's easy to mess up things.
- Don't connect or disconnect the TRRS cable when the keyboard is powered. It may short out. Always disconnect the USB cable first.
- Be gentle with the USB on your microcontroller. They are easy to break.
- Keep in mind that this is a prototype of a DIY keyboard. It's not a polished product.

## Steps

### Prepare

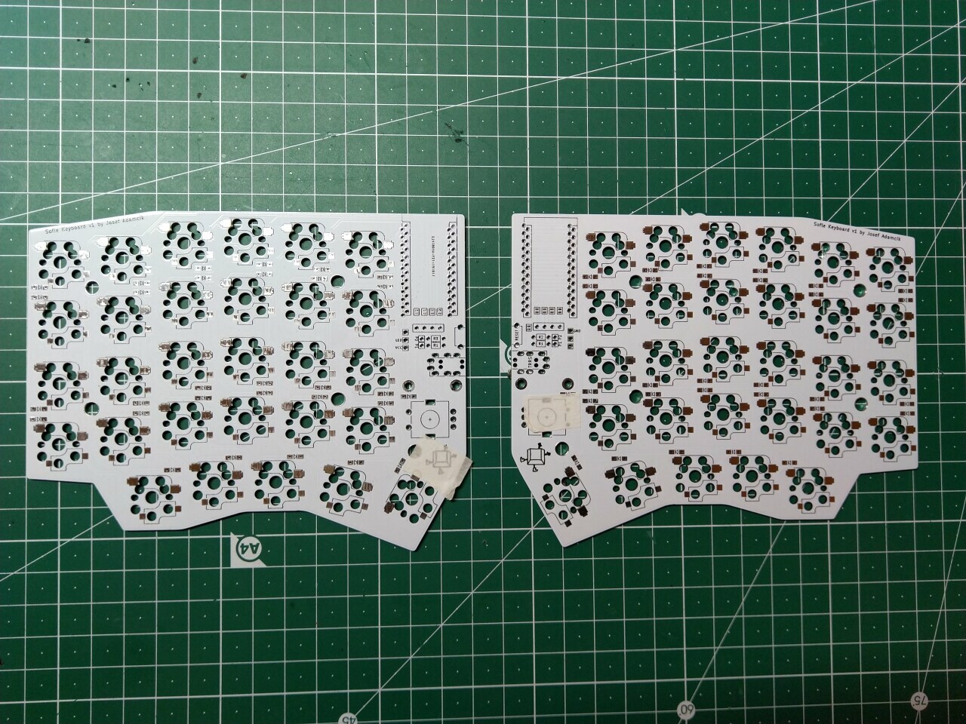
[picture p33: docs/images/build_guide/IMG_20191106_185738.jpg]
Step 1


Both sides of the keyboard ready. The front sides marked by pieces of tape in order to remember which side is which.

### Components on the backside 

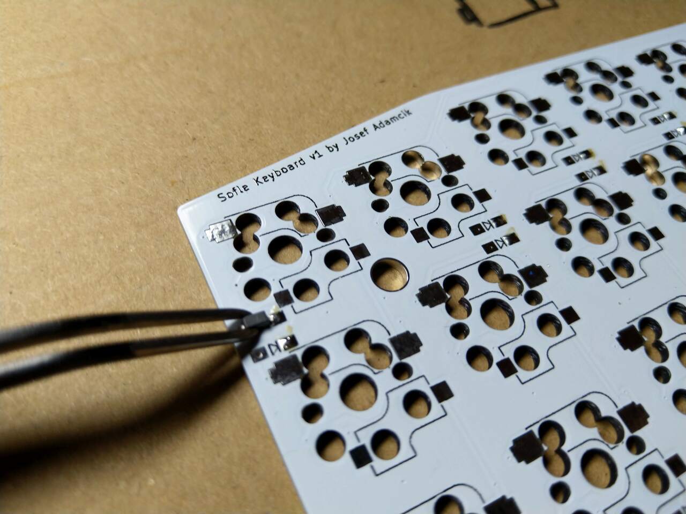
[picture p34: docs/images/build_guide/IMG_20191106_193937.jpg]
Step 2


Starting with the diodes. They belong to the backside of the PCB. Make sure you have orientation right - they are all oriented to the same side. The end with the thin line is Cathode (-) and it should go in the direction of the "arrow" symbol on the PCB.

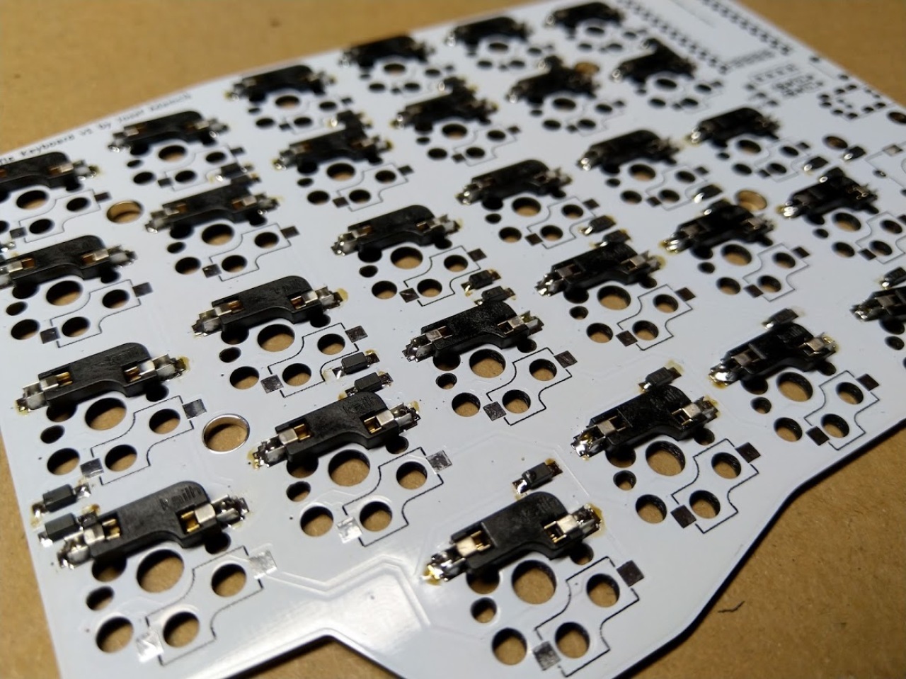
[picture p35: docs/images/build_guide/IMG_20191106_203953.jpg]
Step 3


Sockets for switches belong again on the back side, the same side as diodes. Make sure they are flush with PCB. Watch the markings on the silkscreen which show the correct orientation.

### Components on the front side

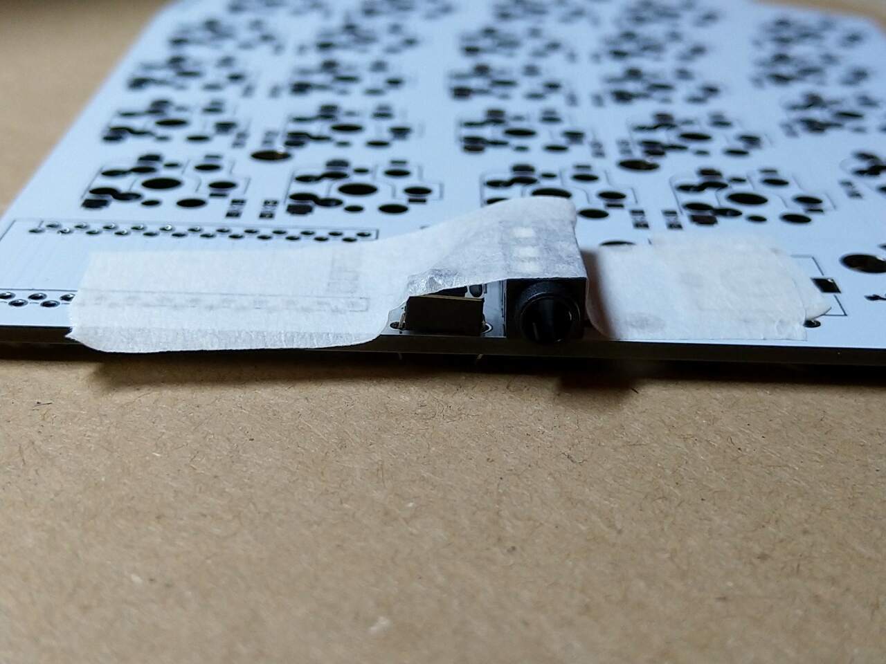
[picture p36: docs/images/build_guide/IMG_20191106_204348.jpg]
Step 4


Button and TRRS sockets belong to the top. Use a piece of tape to fix them and apply solder from the bottom side.

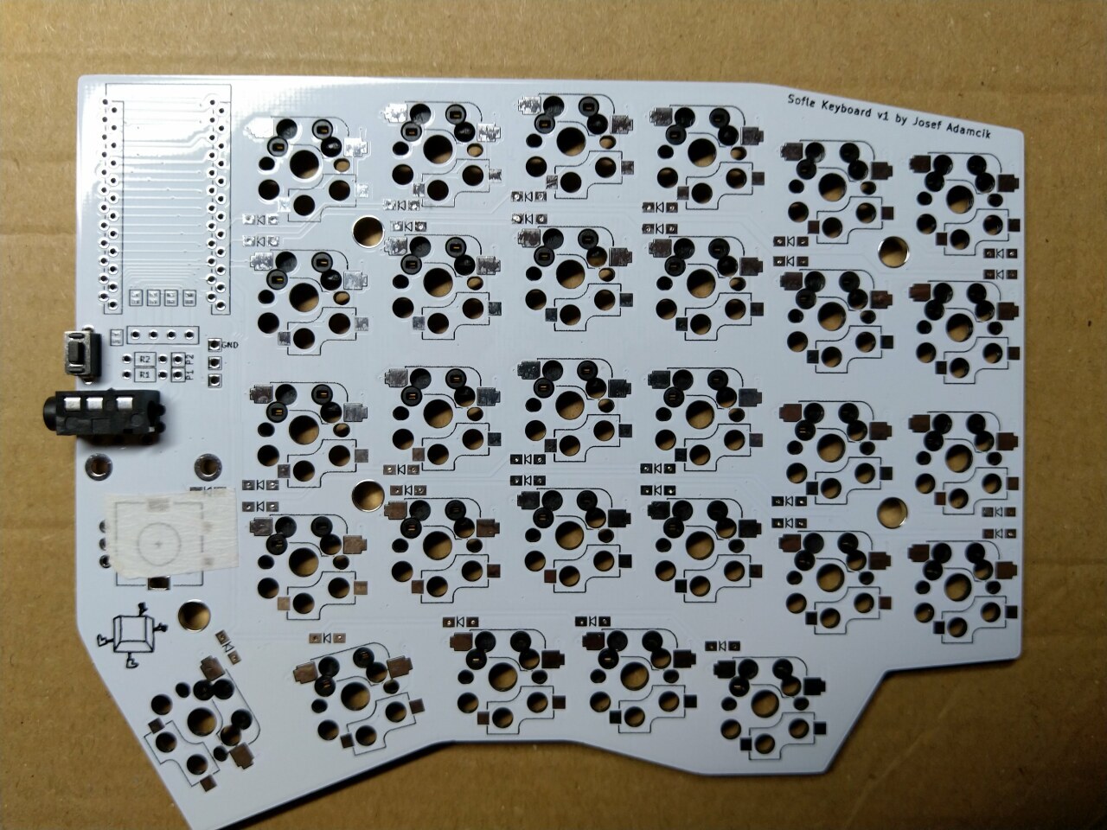
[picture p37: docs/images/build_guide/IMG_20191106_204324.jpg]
Step 5


This is how the right half should look from the top.

### Pro Micro and displays

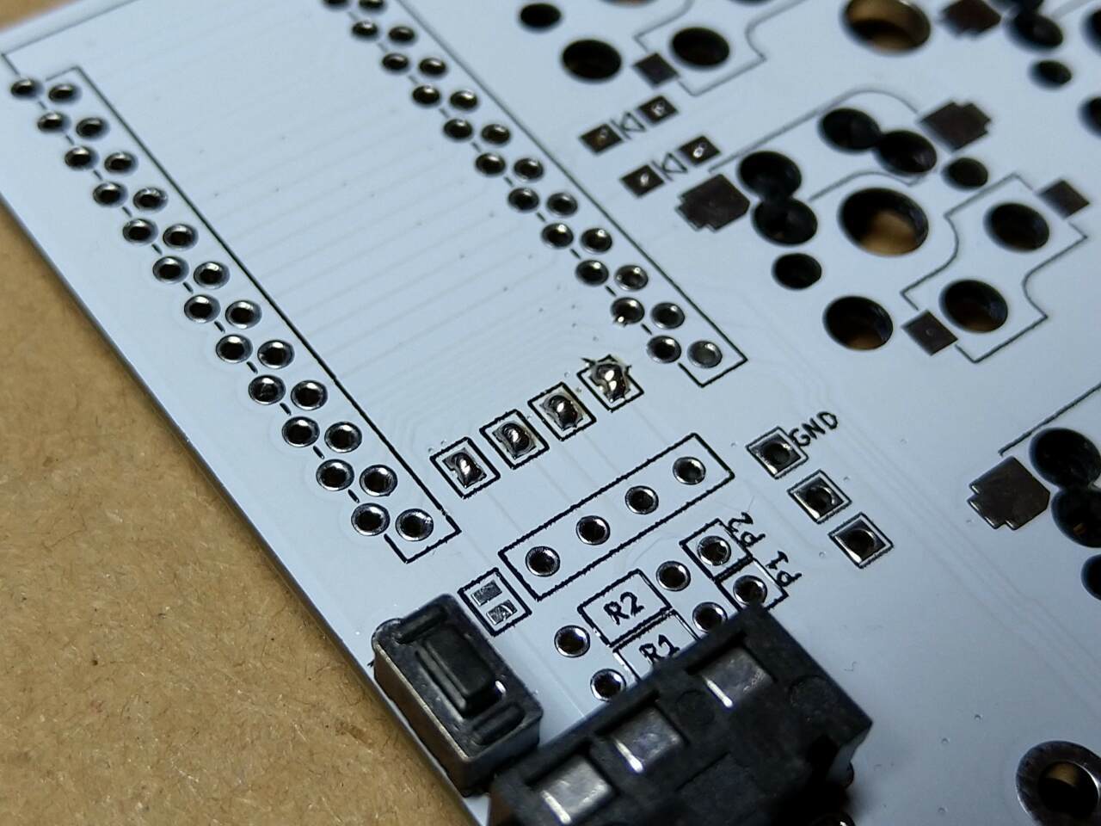
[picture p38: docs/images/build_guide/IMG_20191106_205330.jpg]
Step 6


Bridge 4 jumper pads on the top side. They are necessary for OLED support and if you don't socket you Pro Micro you will not be able to do it later.

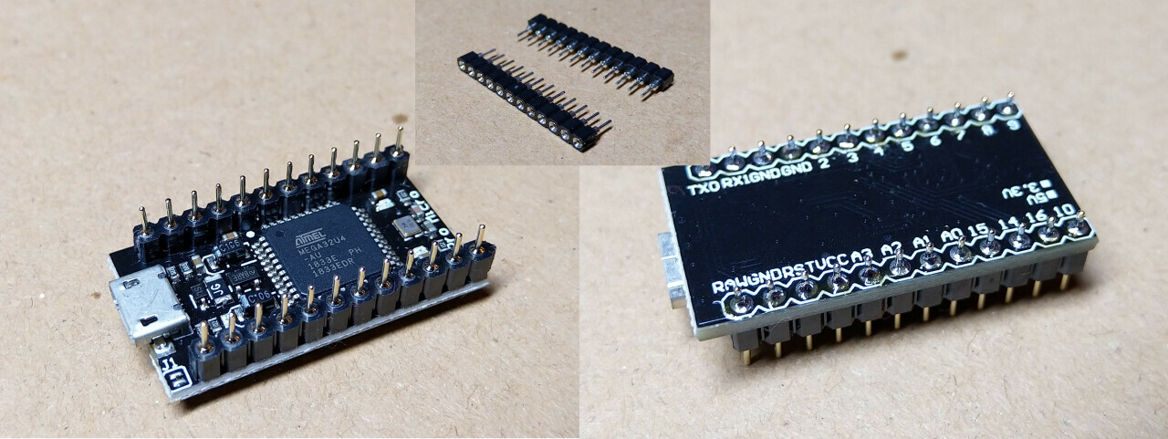
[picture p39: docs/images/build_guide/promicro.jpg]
Step 7


Prepare the Pro Micro. There are several ways how to do it. I have used rounded pin headers. A bit more information about [socketing of Pro Micro is on the sourcing parts page][sourcing]. 

**Keep in mind the orientation**: 

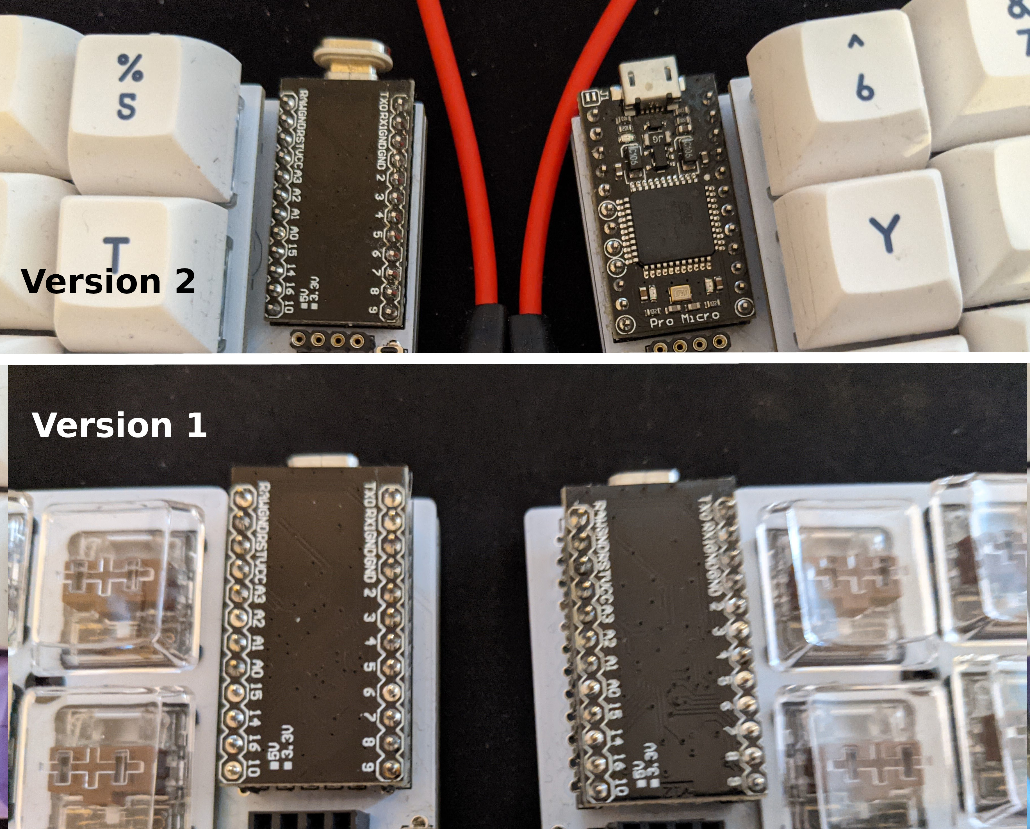
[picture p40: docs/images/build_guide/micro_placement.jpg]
Pro micro orienation


Version 1: the Pro Micro board should be mounted "bottom-up". Its clean side should be at the top, visible. The side with chips and other electronics should be at the bottom facing the main PCB. 

Version 2: The left side as for version 1. The right half has the pro micro mounted up-side up so it's mounted differently on each half. 

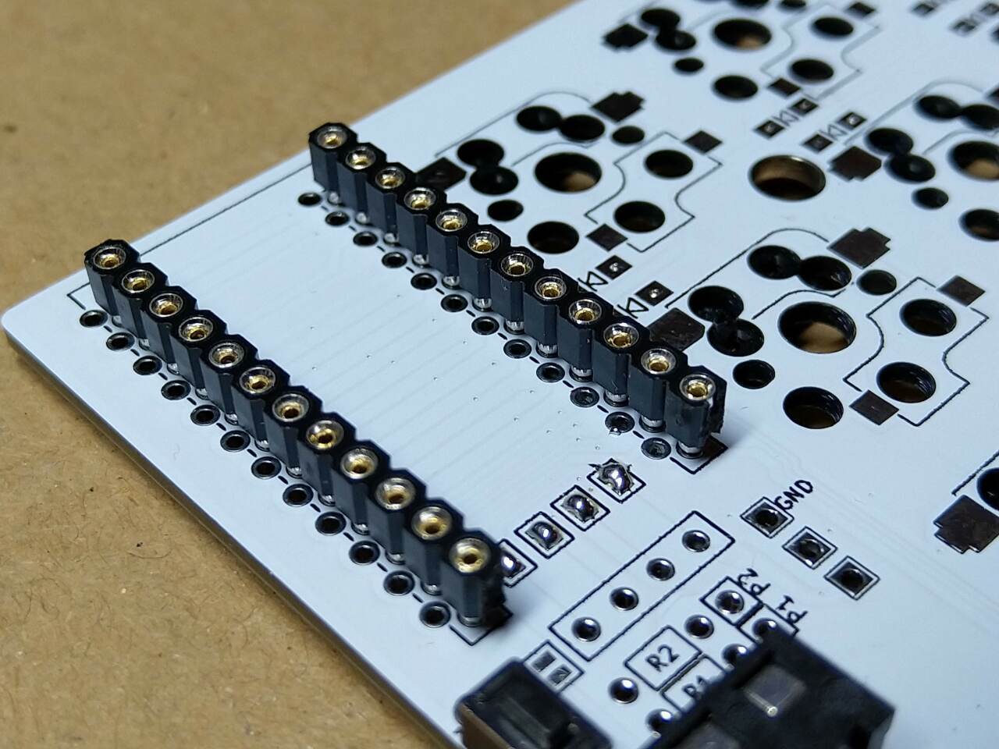
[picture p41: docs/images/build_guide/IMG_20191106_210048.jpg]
Step 8


And corresponding sockets (if used) on the front side of the board. Version 1: Make sure you insert them into the holes which are marked by the rectangles. Version 2: there's only one option so it is straightforward.

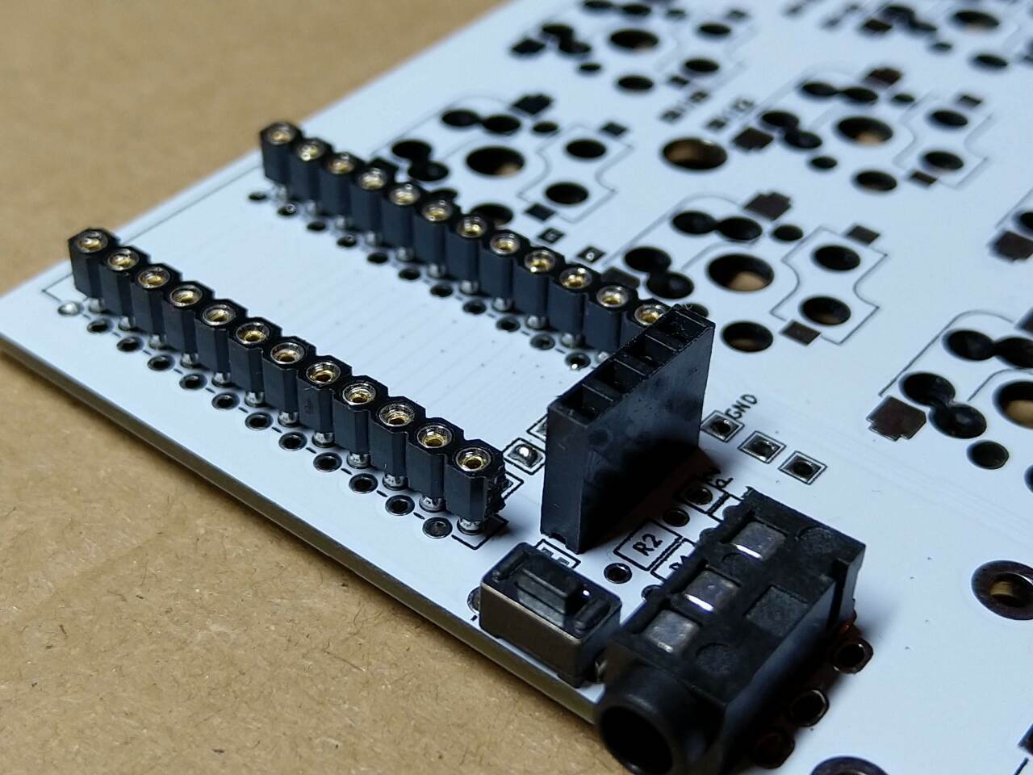
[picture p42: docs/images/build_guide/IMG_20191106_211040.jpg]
Step 9


Add socket for OLED display. Keep in mind height of your Pro Micro which may be different based on if/which socket's you have used for Pro Micro. Check everything before soldering.

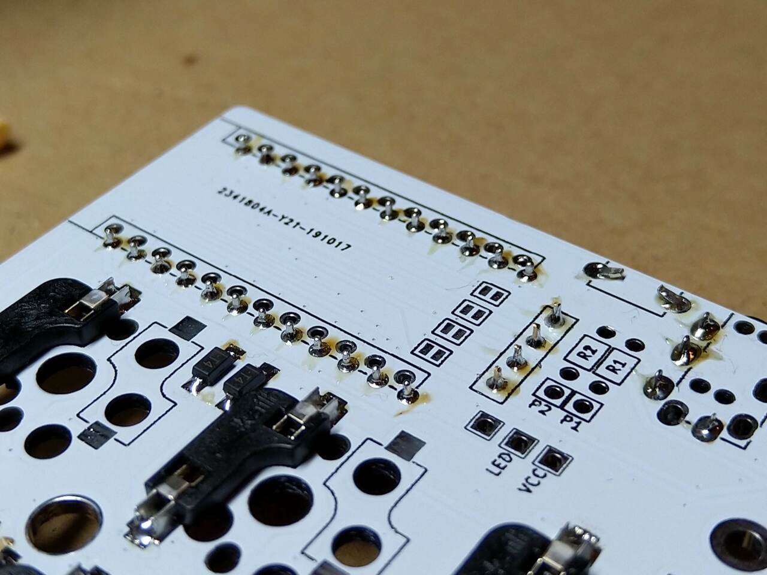
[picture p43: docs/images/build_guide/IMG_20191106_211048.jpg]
Step 10


This is how the backside (bottom) should look at this stage.

### First test

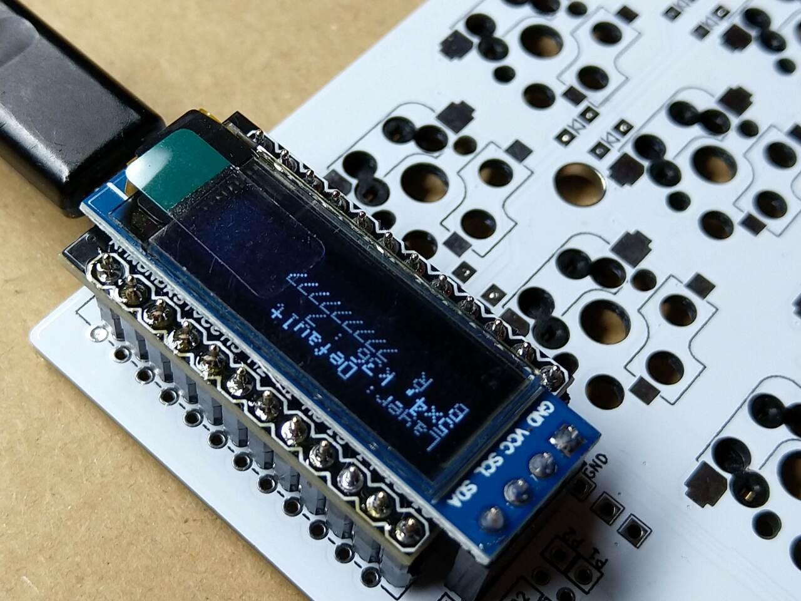
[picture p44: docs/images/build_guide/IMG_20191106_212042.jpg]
Step 11


Now it is already possible to connect the ProMicro and OLED display to the board, flash the firmware and check if all keys work using a piece of wire or tweezers.

### Rotary encoders

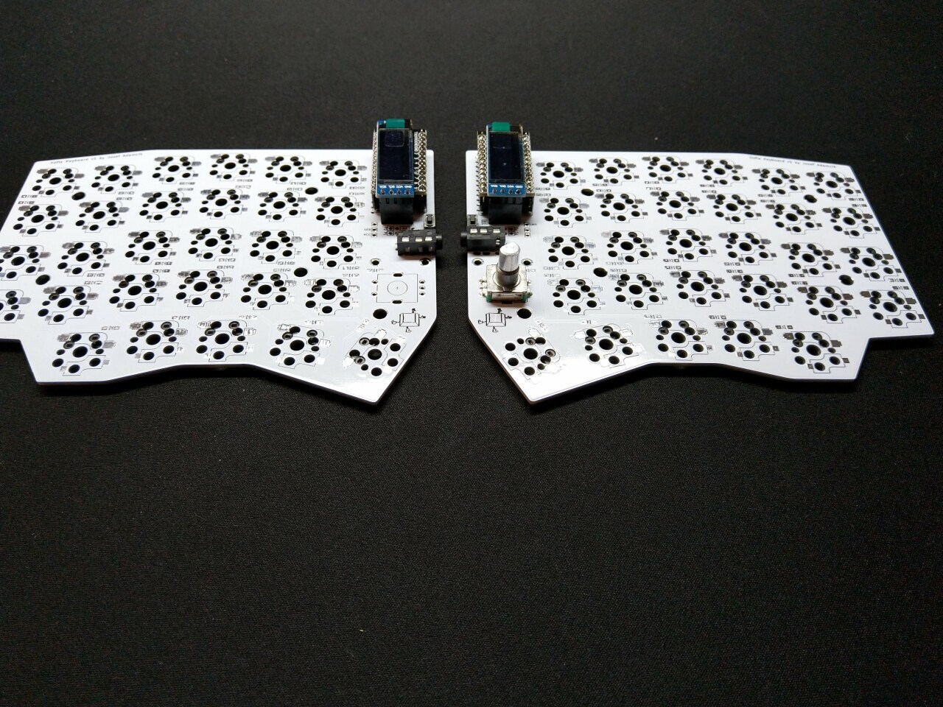
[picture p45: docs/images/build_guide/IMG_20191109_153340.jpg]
Step 12


Both halves assembled, a rotary encoder can be added on both, one or none. I have also cleaned flux residue from the back side using some isopropyl alcohol, cotton buds and paper towels.

### Keyboard switches and plates

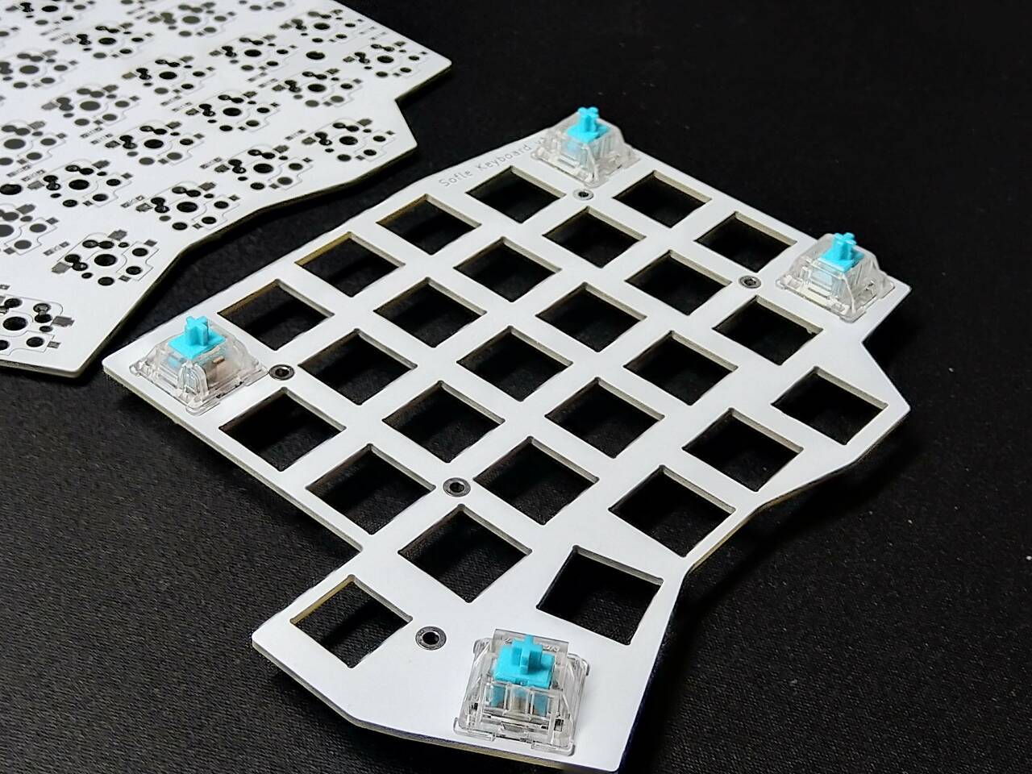
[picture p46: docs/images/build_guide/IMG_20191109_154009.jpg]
Step 14


Snap first switches into corners.

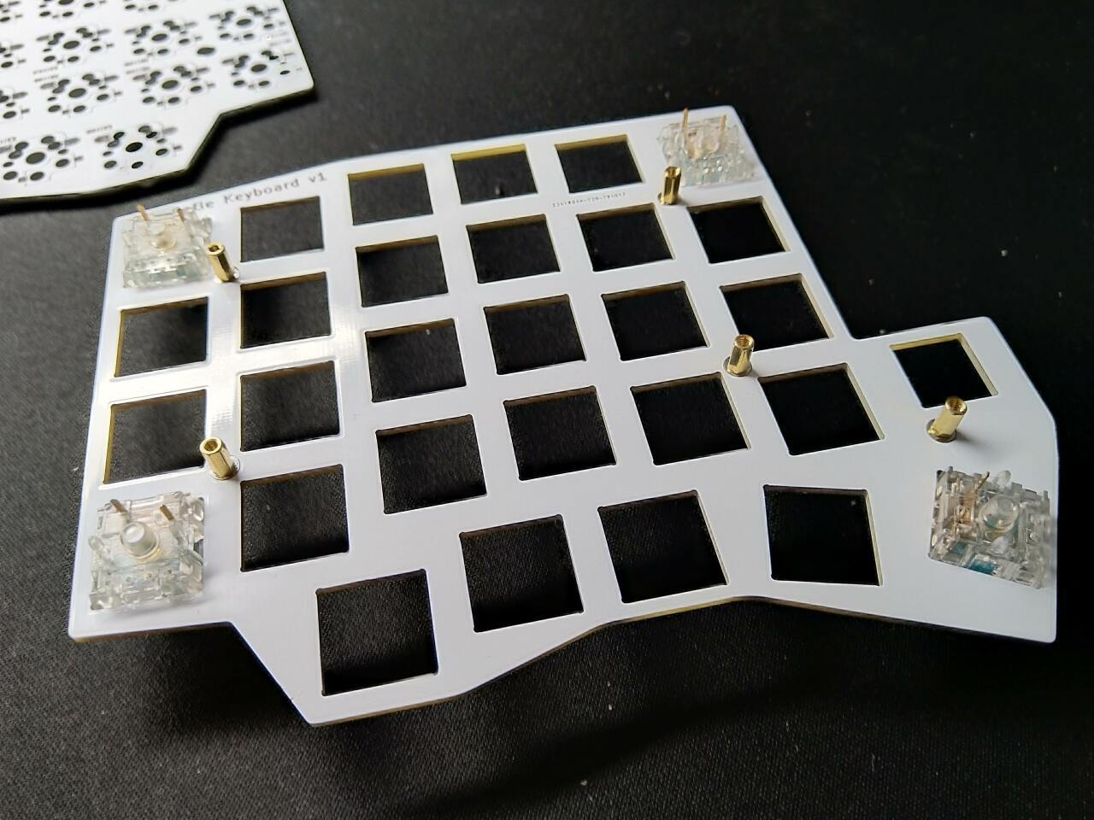
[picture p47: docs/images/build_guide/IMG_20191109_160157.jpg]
Step 15


Mount the stand-offs to the top plate.

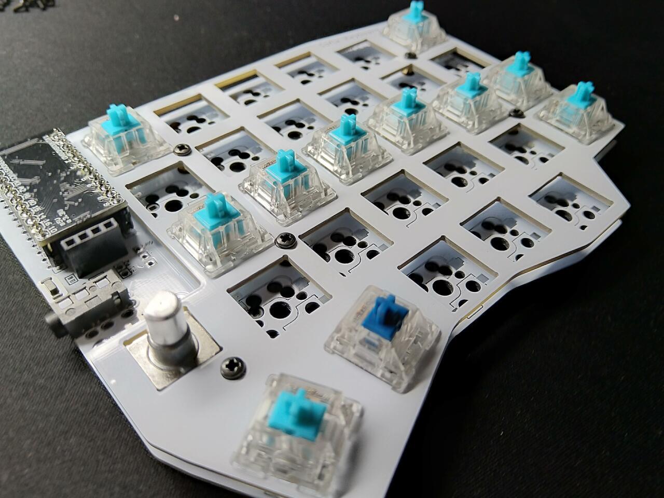
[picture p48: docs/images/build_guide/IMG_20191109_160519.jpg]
Step 16


Carefully snap the first switches to the sockets. Be careful so you don't bend their contacts. Add more.

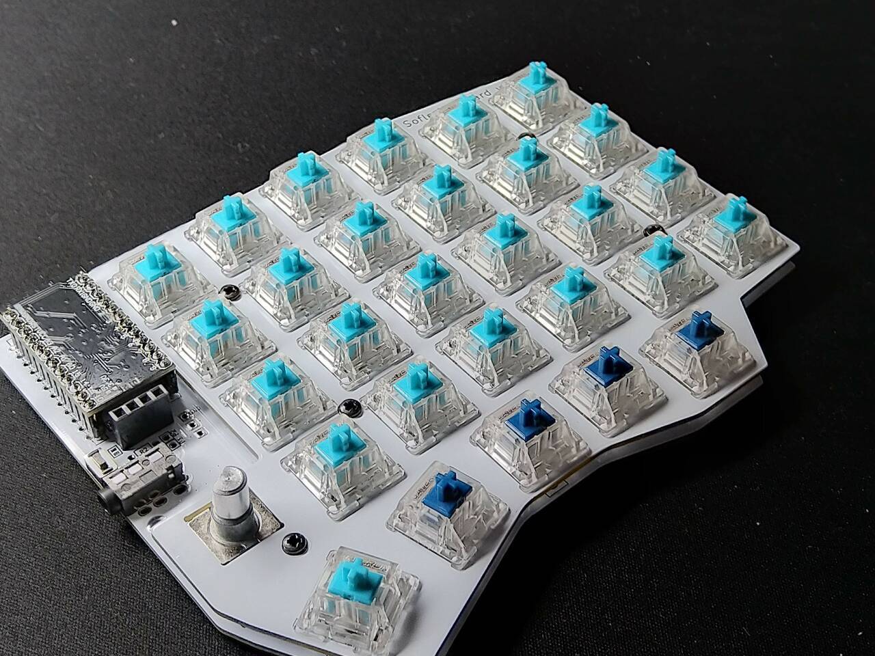
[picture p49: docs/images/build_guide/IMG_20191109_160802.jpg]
Step 17


Until they are all in place.

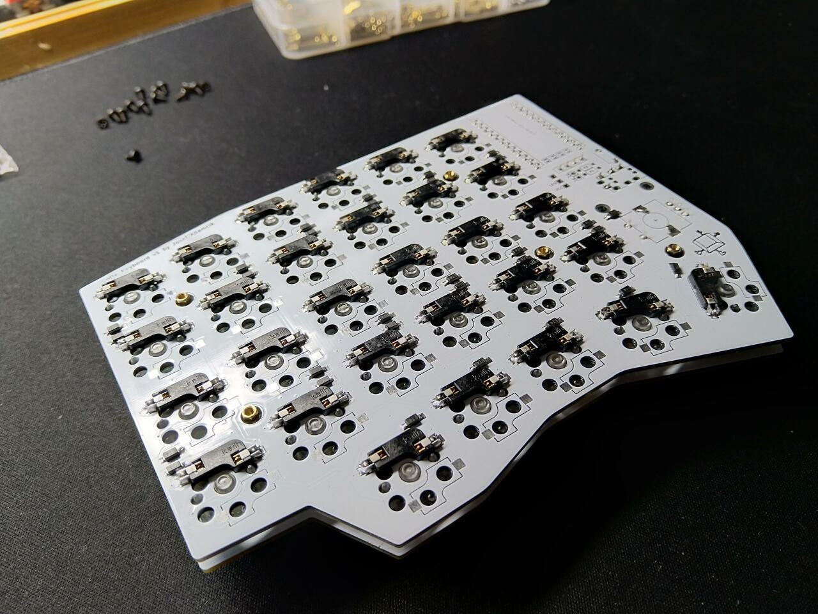
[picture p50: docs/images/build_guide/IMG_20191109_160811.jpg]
Step 18


Double-check the bottom. You should see all the contacts in sockets.

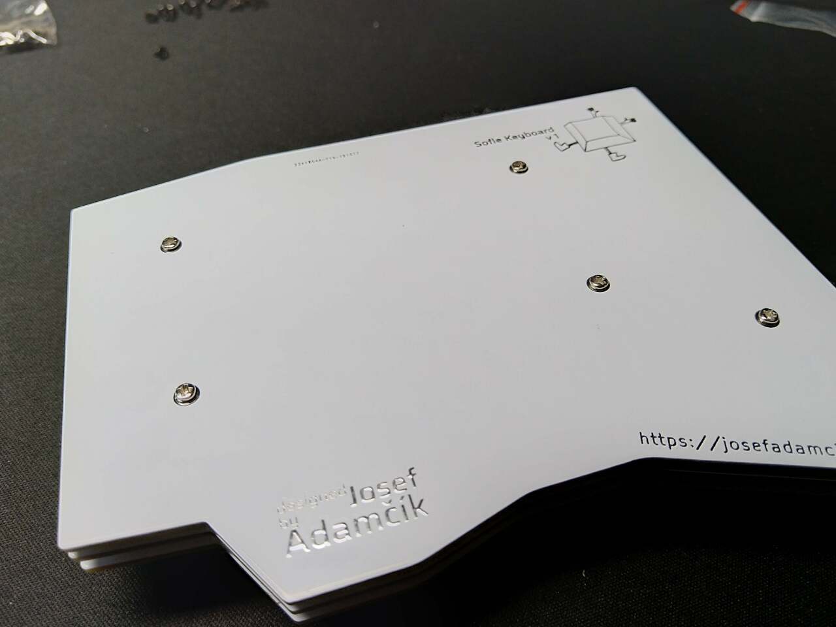
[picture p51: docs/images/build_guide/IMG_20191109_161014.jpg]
Step 19


And mount the bottom plate.

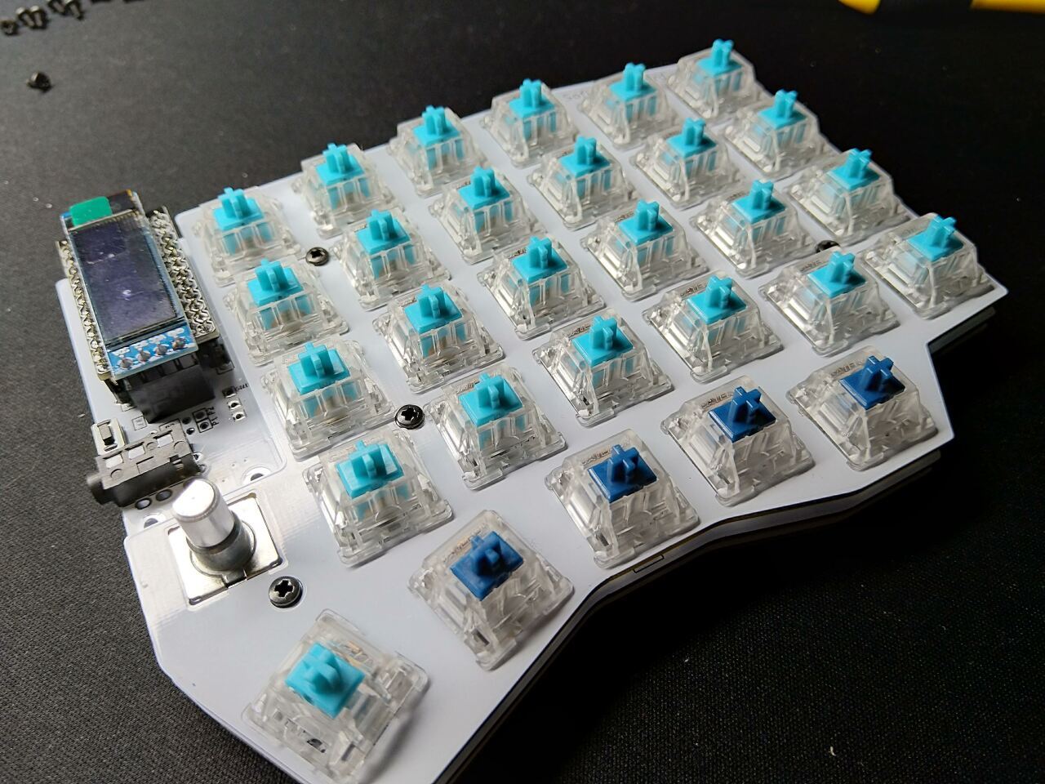
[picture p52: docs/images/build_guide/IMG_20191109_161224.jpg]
Step 20


Completed half of the keyboard waiting for keycaps.

### Finishing touches

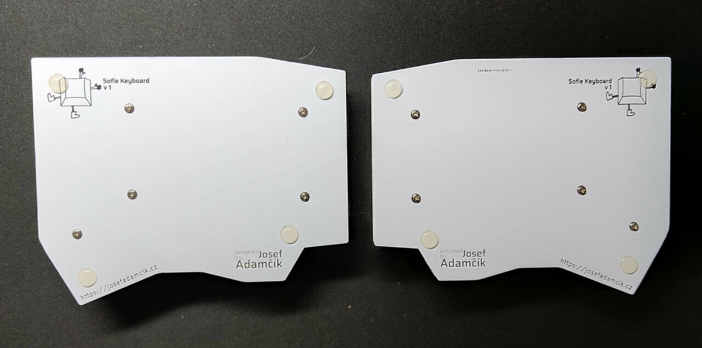
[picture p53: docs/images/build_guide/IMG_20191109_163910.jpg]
Step 21


Put at least 4 adhesive rubber feet in the corners so the keyboard is not moving when you type.

## Warnings and disclaimers

- Don't connect or disconnect the TRRS cable when the keyboard is powered. It may short out. Always disconnect the USB cable first.
- Be gentle with micro USB ports on your microcontrollers. They are easy to break.
- Keep in mind that this is a prototype of a DIY keyboard. It's not a polished product.

## Firmware and programming

Sofle keyboard uses [QMK Firmware][qmk_firmware] and support for the board is part of the main QMK repository. There's also a basic support in [QMK Configurator][qmk_configurator] but there's no default layout yet and encoders are not supported.

Suggested approach is to build the firmware yourself. You should be familiar with QMK and be able to make it work on your local environment. If not, please [follow the instructions in the documentation][qmkintro].

- Make sure your QMK environment [is setup][qmkintro].
- Make sure halves are not connected together with TRRS cable.
- Connect one half to USB, flash the firmware (always follow the actuall instructions in the QMK documentation! The command might look something like this: `qmk flash -kb sofle/rev1 -km default`). Use the reset button to reset the keyboard when you are asked to in console. 
- Connect the second half and flash it in the same way as the previous one.
- Disconnect the USB cable. Connect both halves together with TRRS cable.
- Connect USB cable to the **left** side[^2]. 
- Enjoy SofleKeyboard!

## Troubleshooting

### Elite-C v3.0

Elite-C v3.0 had problems when used with split boards (on both halves). Those are fixed in version 3.1. For v3.0 add `#define SPLIT_USB_DETECT` to `config.h` file. I don't have Elite-C so this is untested, but should work.

### Typing lag when used without OLED 

If you chose to not use OLED for both halves you should disable support for oled (set `OLED_DRIVER_ENABLE` to `no` in `keymaps/defualt/rules.mk`).

If you don't use OLED only on one half you are need to do **one** of the following to fix the lag:

- Solder pull-up resistors (4k7) to the PCB (R1, R2) without OLED.
- Use a workaround explained [in this issue][nooledlag].
- Stop using OLED completely and turn it off as described above.

## Modifications

### Inverted silkscreen

If you fancy an [inverted silkscreen there's a great guide available](https://github.com/josefadamcik/SofleKeyboard/issues/3#issuecomment-683192038).

## Links

- [Github with KiCad projects][soflegithub]
- [Layout in KeyboardLayout editor][soflelayout]
- [QMK Firmware][qmk_firmware]
- [QMK Configurator][qmk_configurator]

## Footnotes

[^1]: Serial is the default behaviour. If serial is used, you don't need TRRS cable (4 contacts, used for headphones with a microphone) but just TRS (stereo audio jack). 
[^2]: This can be changed, look for [setting handednesss][qmkhandedness] in QMK documentation.
[^3]: There was a design issue where the cutout for the encoder is big enough only for the base of the encoder but not for its legs. That is perfectly ok when you build the board with MX switches since the plate sits above the legs. But for low profile Kailh Choc switches there's no longer any gap between plates. If you have unfixed plate (the problem was fixed in v1.1.) and wish to use an encoder, you'll need to file off a bit of PCB material to get the legs of encoder through (see the guide above).

[layoutarticle]: <https://josef-adamcik.cz/electronics/in-search-of-the-best-custom-keyboard-layout.html> "In search of the best custom keyboard layout"
[introductionarticle]: <https://josef-adamcik.cz/electronics/let-me-introduce-you-sofle-keyboard-split-keyboard-based-on-lily58.html> "Let me introduce you SofleKeyboard - a split keyboard based on Lily58 and Crkbd"
[soflelayout]: http://www.keyboard-layout-editor.com/#/gists/76efb423a46cbbea75465cb468eef7ff "Sofle Keyboard layout at keyboard-layout-editor.com"
[soflegerber]: https://github.com/josefadamcik/SofleKeyboard/releases "SofleKeyboard - gerber files"
[qmk_firmware]: https://github.com/qmk/qmk_firmware/ "QMK firmware"
{:target="_blank"}
[qmk_configurator]: https://config.qmk.fm/#/sofle/rev1/LAYOUT "QMK configurator"
{:target="_blank"}
[springpinheader]: <https://yushakobo.jp/shop/a01mc-00/> "Spring pin headers - Japaneese"
{:target="_blank"}
[qmkprotonc]: https://qmk.fm/proton-c/ "QMK Proton-C"
{:target="_blank"}
[promicrosocketing]: <https://docs.splitkb.com/hc/en-us/articles/360011263059> "How do I socket a microcontroller? by splitkb.com"
{:target="_blank"}
[qmkintro]: <https://beta.docs.qmk.fm/tutorial/newbs_getting_started> "QMK getting started"
{:target="_blank"}
[qmkhandedness]: <https://docs.qmk.fm/#/feature_split_keyboard?id=setting-handedness> "QMK firmware - setting handedness"
{:target="_blank"}
[manufacturingproblems]: https://josef-adamcik.cz/electronics/corne-keyboard-build-log.html#manufacturing-at-jlcpcb---update-27112019 "Possible problems when manufacturing top plate for Corne"
[nooledlag]: https://github.com/qmk/qmk_firmware/issues/7522 "No OLED lag bug"
[soflegithub]: https://github.com/josefadamcik/SofleKeyboard "SofleKeyboard - KiCad project on Github.com"
[sourcing]: <{{ site.baseurl }}/sourcing_parts.html> "Sourcing parts"
[rgbbuildguide]: <{{ site.baseurl }}/build_guide_rgb.html> "Sofle RGB build guide"
[chocbuildguide]: <{{ site.baseurl }}/build_guide_choc.html> "Sofle Choc build guide"

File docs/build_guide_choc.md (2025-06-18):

---
layout: default
title: Sofle Keyboard - build guide (Choc)
---

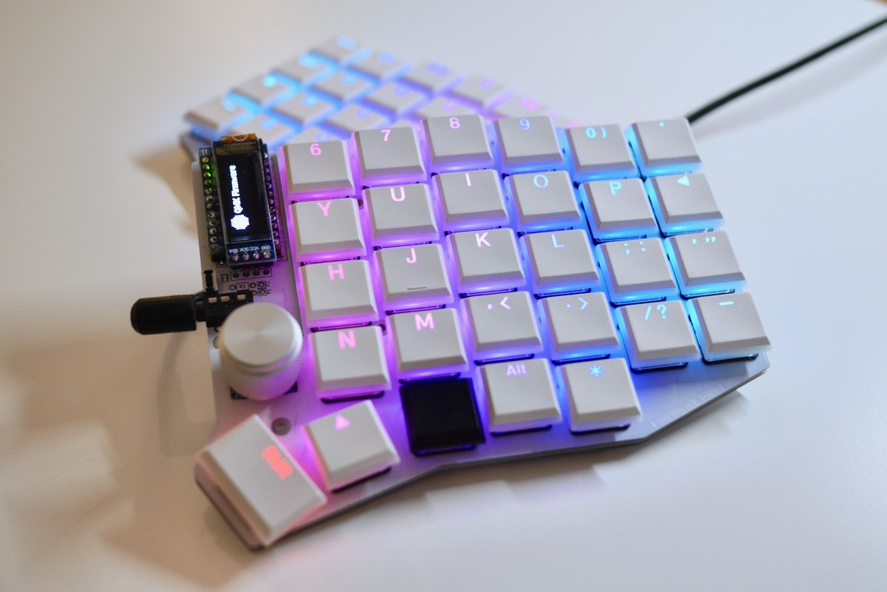
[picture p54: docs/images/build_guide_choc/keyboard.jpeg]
Keyboard

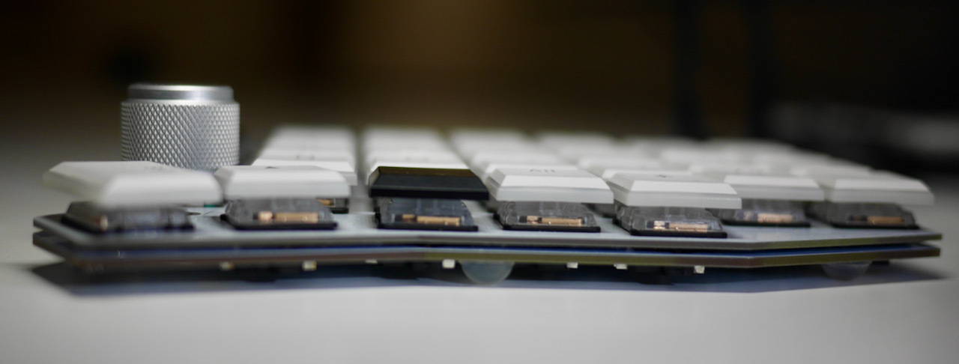
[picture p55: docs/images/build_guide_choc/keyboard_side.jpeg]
Keyboard Side View


The Sofle Choc is a variation of the Sofle with:

   - low-profile, Kailh Choc switches
   - hotswap sockets
   - per-key RGB
   - thin, 15mm from desktop to top of keycaps
   - Sofle RGB switch layout with pinky stagger in between v1 and v2

This version supports [Kailh Choc v1 switches](https://deskthority.net/wiki/Kailh_PG1350_series). Kailh hotswap sockets are required. Per-key RGB is optional and uses the relativey easy to solder SK6812 MINI-E LEDs.

The top plates are not compatible with Sofle v1, v2 or RGB versions. There is no bottom plate to minimize thickness.

The Sofle Choc was designed by [Brian Low](https://github.com/brianlow) and based on the excellent Sofle RGB by [Dane Evans](https://github.com/DaneEvans) which was based on the original Sofle v2 by [Josef Adamčík](https://github.com/josefadamcik).

## Updated Build Guide and Kits

I am maintaining a newer version of the build guide and usually have kits available at:

[http://choc.brianlow.com](http://choc.brianlow.com)

## Bill of materials

The following is needed to build the keyboard:

- **2 PCBs**. Send the zip from `/Gerbers/Choc_v2/choc-v2-gerber-pcb.zip` to a PCB fabrication service. The PCB should be 1.6mm thick [though 1.2mm may be better](https://github.com/josefadamcik/SofleKeyboard/issues/136#issuecomment-1045965676). Otherwise I used JLCPCB's default settings only customizing the PCB color. See [sourcing][sourcing].

- **2 top plates**. Send the zip `/Gerbers/Choc_v2/choc-v2-gerber-top.zip` to a PCB fabrication service. The top plate holds the switches in place. The top plate should be 1.2mm thick. Otherwise I used JLCPCB's default settings only customizing the PCB color. See [sourcing][sourcing].

- **2 Pro Micro** boards or clones. 5v, 2x12 pins, ATmega32U4 microcontroller. **Don't** buy the Arduino Micro (a different pinout) or Arduino Mini (different microcontroller). You could also use Elite-C which basically Pro Micro with USB-C.

- **4x 12 pin headers (and optional sockets)** for Pro Micros. There are several ways to mount Pro Micros to the board. The male pin headers you most likely got with the board can be used to solder it directly to the board. This makes it hard to replace the board if it fails. The micro-USB connector is known to tear off. I socketed the Pro Micro using the diode legs approach [described at splitkb.com][promicrosocketing] with two 12-pin female headers. This is the option descibed in the build guide here. Lastly, [these spring pin headers][springpinheader] are used on similar keyboards and should give a compact, non-permanent connection but have been out of stock for a long time.

- **58 Kailh Choc keyboard switches**. Must be [Kailh Choc v1 switches (PG1350)](https://deskthority.net/wiki/Kailh_PG1350_series) of any color. The `PG` prefix is often omitted. **Don't** buy [Kailh Choc v2](https://deskthority.net/wiki/Kailh_PG1353_series), [Kailh Mini Choc](https://deskthority.net/wiki/Kailh_PG1232_series) or [Cherry MX](https://deskthority.net/wiki/Cherry_MX).

- **58 Kailh Choc keyboard switch sockets**. Sockets are specific to the PG1350 switch. The PCB requires sockets. Switches cannot be soldered directly to the board.

- **58 keycaps**. You can use either all in `1u` size but it looks nicer with two `1.5u` for the thumb keys.

- **58 diodes 1N4148W**. Surface mount diodes in SOD123 package. Pick any common variation. I used `1N4148WTR` (Digi-Key 1655-1360-1-ND).

- **2 TRRS connectors PJ-320A**. The same type which is used for Corne, Lily58 etc. Technically even TRS should work if you stick to the default serial communication.

- **2 buttons** momentary, tactile, through-hole, 2 pins, I used one for DIP switches, 3x6x4.3mm. Technically optional: you can use metal tweezers whenever you need to reset the microcontroller.

- **1 TRRS cable**. TRS should work if you stick with the default serial communications.

- **8 - 10 silicone bumpers**. Used for feet to keep the keyboard from moving

- **Micro USB Cable** to connect the keyboard to a computer.

Optional components:

- **OLED/s**
  - **2 SSD1306 128x32 OLED display module**. 4-pin, I2C, 0.91". Very common.
  - **2x 4 pin header (and optionally socket)** for OLEDs. These came pre-soldered to the OLED unit. You can solder the OLED directly to the board. Ideally use a socket so you can replace and/or get at the ProMicro underneath. I found 4 pin female headers with half height (~4mm) insulation worked well
  - **2 OLED covers** This should be compatible with the Sofle RGB cover but have not verified

- **Rotary encoders**
  - **2 Rotary encoders EC11**. If you are not sure take EC11E. Some other variants (EC11K) may have some additional plastic pins for and require mounting holes for them which are not included on the PCB. Perfer short shaft. I used encoders with 10mm, D-shaped shaft and 30 positions from AliExpress. I also tried a high quality Bourns encoder (PEC11 series) but found it required a bit too much effort to twist.
  - **2 matching knobs** for each encoder. Make sure the knob matches the encoder's shaft diameter, depth and shape.
  - **2 diodes 1N4148W** the encoder shafts are pushable and can be used as configurable keys.

- **LEDs**
  - **58 SK6812 MINI-E RGB LEDs**. The LED body 3.2x2.8x1.7mm and with legs is 5.8x2.8. Avoid the non-MINI-E version without the legs. Purchase extra as they are delicate. I ended up replacing 6 during my build.

- **Resistors**
  - **2x 4.7kOhm through hole resistors** These only needed if you want to use the less common I2C communication protocol between halves. They are installed in the R1/R2 spots. I have not tested an I2C setup. The firmware on this page uses serial communication and does not require the resistors.

Components that are common on other Sofle variants but are **not** used on this Softle Choc: bottom plate, M2 spacers and screws.

## Tools and materials

- soldering iron and solder
- no-clean flux makes soldering easier
- solder wick or desoldering pump to correct mistakes
- good tweezers
- flush cutters to trim diode legs when socketing the ProMicro
- masking, kapton or electrical tape
- isopropyl-alcohol for cleaning
- screwdriver
- 1.5mm hex key for the set screw on the encoder knob
- mulitmeter for troubleshooting

## Steps

### Prepare

Make sure you know which side you are working on, and don't make two left hand sides by mistake. Stick a piece of tape on the front side of both PCBs to help remember.

This guide is written in the order I like to install components.

We will start with the components on the back, shortest to tallest:
  - diodes
  - LEDs
  - switch sockets

Then install the components on the front:
  - OLED jumpers
  - ProMicro & socket
  - OLED & socket
  - reset switch
  - TRRS connector
  - encoder

The order of assemby does not matter **except** for these 3 components because they stack on top of one another:
  1. the four OLED jumpers
  2. the Pro Micro
  3. the OLED screen

The build guides for the Sofle and Sofle RGB have some good tips and photos. However there are differences so use this page as your primary reference. In particular, use the ProMicro orientation described on this page.

### Switch Sockets and Diodes

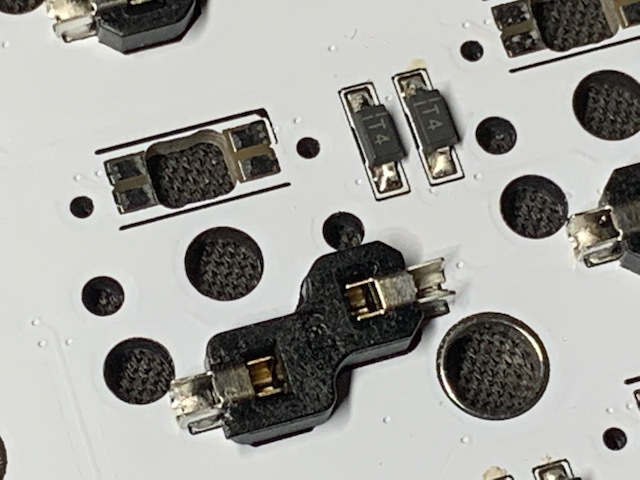
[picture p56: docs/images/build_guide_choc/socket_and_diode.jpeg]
Switch sockets and diodes


These components are placed on the back of the PCB.

Diodes must be oriented with the white band in the direction of the "arrow" symbol on the PCB. I typically tin one pad, place the diode on, apply the soldering iron to the diode leg until it melts the solder underneath and sinks flush with the PCB. Then come back and solder the other leg.

The sockets are the largest and easiest to solder. They are installed on the back of the PCB facing up towards the front of the PCB. Make sure they are flush with the PCB. Heat the metal connector, apply solder and look for the solder to wick down to the PCB. You want a solid joint since this may take some mechanical strain from switch installation and removal.

### The LEDs

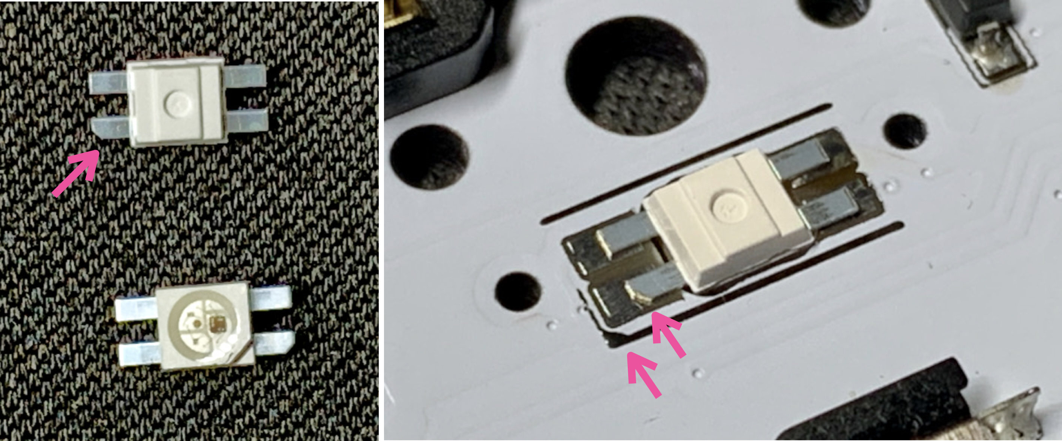
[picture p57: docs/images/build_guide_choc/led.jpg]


LEDs are placed on the back of the PCB. The lens should point up through the PCB so they shine into the bottom of the switch. One leg will have a diagonal cut. This cut leg should be aligned with the triangular marking on the PCB.

To solder: tin one pad, place the LED and hold using tweezers, apply heat to the leg until the solder melts and the LED is flush with the board. Now the remaining legs can be soldered without the component moving. The LEDs are sensitive to heat. Let the LED cool between soldering each leg. Use the lowest heat needed for your solder.

The LEDs are wired in one long chain. If a LED is not working, replace the LED and the LED preceeding it. Sometimes just the output of a LED is damaged. The full chain does not need to be installed if you want to test a partially built board.

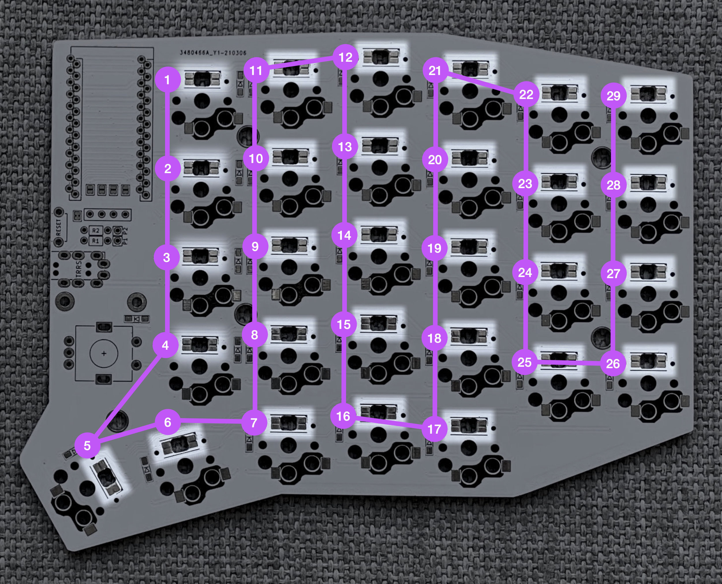
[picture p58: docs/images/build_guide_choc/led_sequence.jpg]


### OLED Jumpers

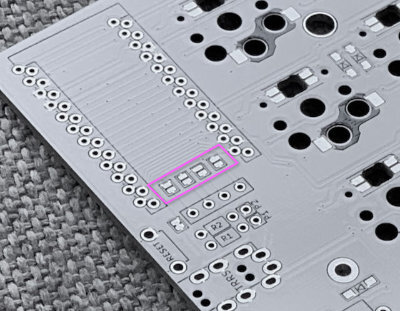
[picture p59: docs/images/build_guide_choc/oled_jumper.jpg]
OLED Jumpers


Now we move to the front of the PCB.

The jumpers in the photo should be bridged if using an OLED dispay. The jumpers may not be accessible later in the build depending on how the Pro Micro is attached. Bridge the jumpers on the top side of the board, the same side the ProMicro will be mounted on.

### Pro Micro

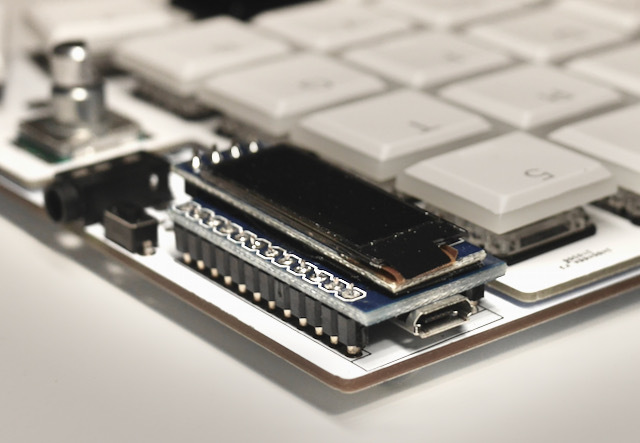
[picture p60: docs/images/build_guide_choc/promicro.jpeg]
Pro Micro


The Pro Micro is installed on the top of the board, upside down and in the marked holes.

* Top of the board: this is the side of the PCB opposite the diodes, LEDs and switch sockets
* Upside down: both Pro Micro components should face the PCB with the mostly plain back facing out
* Marked holes: there are two sets of holes in the PCB, use the holes with the rectangular outline on the top of the board

Double-check your work here. This step is hard to reverse if a mistake is made.

To install a socketed Pro Micro using the diode leg approach [from splitkb.com][promicrosocketing]:

  1. Install the 12-pin female headers on the top of the board in the outlined through holes. Use some tape to temporarily tack them in place. Flip the board over onto a flat, hard surface. While soldering the first pins, push down on the PCB to ensure the headers are perpendicular and fully seated.

  2. Flip the board upright again. Optionally place some tape over the sockets to protect against fusing parts together. Place the Pro Micro upside down on top. Push diodes though the Pro Micro holes, through the tape and seated into the socket below.

  3. Solder the legs to the Pro Micro. Snip off the legs above the Pro Micro.

If you ever need to remove the Pro Micro: do it by gently prying the board up in small increments, working your way around the board. Avoid pressure on the USB connector. The diode leags are quite weak and will usually bend if you pull the Pro Micro off in one action.

### OLED

Install the OLED so it overhangs the Pro Micro. I added electrican's tape to the bottom of the OLED module where it might contact the Pro Micro.

If you are socketing the OLED, install the 4 pin, half height female header on the top of the PCB. Then push the OLED pins into the socket. You may need to trim the OLED pins so the insulation on the female and male headers mate and the OLED sits just above the Pro Micro. The downside to socketing is the OLED isn't as secure in the half height socket. When turning the keyboard upside down I find the OLED will lever away from the Pro Micro somewhat.

### Solder misc components

Use tape to tack each component in place while flipping the board over to solder.

Solder the reset switch.

Solder the TRRS connector. You may need to bend the TRRS connector pins 90 degrees so they point down into the PCB. The R1 and R2 locations should remain empty.

Solder the encoder.

### Assemble

- Snap a few switches into the top plate, the corner switches work best

- Place the PCB on a flat surface. This will save some strain on the solder joints in the next step (though they should be able handle it).

- Carefully lower the top plate with switches on the main PCB and push into sockets. Ensure pins are aligned.

- Snap the remaining switches into the top plate pressing into the sockets.

- There are no standoff between the PCB and top plate

- Place the encoder knob on the shaft. Tighten the set screw with a hex key. A small screwdriver for glasses may do in a pinch.

- Optionally add oled covers

- Put at least 4 adhesive rubber feet in the corners so the keyboard is not moving when you type.

## Warnings and disclaimers

- Don't connect or disconnect the TRRS cable when the keyboard is powered. It may short out. Always disconnect the USB cable first.
- Be gentle with micro USB ports on your microcontrollers. They are easy to break.
- Keep in mind that this is a prototype of a DIY keyboard. It's not a polished product.

## Firmware and programming

The Sofle Choc uses [QMK Firmware][qmk_firmware]. Support is not in the main QMK repository [yet](https://github.com/qmk/qmk_firmware/pull/16736). Instead use the [brianlow/qmk_firmware](https://github.com/brianlow/qmk_firmware) fork.
Suggested approach is to build the firmware yourself. You should be familiar with QMK and be able to make it work on your local environment. If not, please [follow the instructions in the documentation][qmkintro]. Note QMK setup is fairly invasive (upgrade every homebrew package on your system) so you might want to consider the [QMK Docker image](https://beta.docs.qmk.fm/using-qmk/guides/development-environments/getting_started_docker) for compiling.

To flash:

- Clone [https://github.com/brianlow/qmk_firmware](https://github.com/brianlow/qmk_firmware)
- Switch to the `choc2` branch with `git checkout choc2`
- Make sure your QMK environment [is setup][qmkintro].
- Make sure halves are not connected together with TRRS cable.
- Connect one half to USB, flash the firmware (always follow the current instructions in the QMK documentation! The command might look something like this: `qmk flash -kb sofle_choc -km default`). Use the reset button to reset the keyboard when you are asked to in console. Some Pro Micros require double-clicking the reset button to enter bootloader mode.
- Connect the second half and flash it in the same way as the previous one.
- Disconnect the USB cable. Connect both halves together with TRRS cable.
- Connect USB cable to the **left** side.
- Enjoy SofleKeyboard!

There is also a firmware version that uses [VIA](https://caniusevia.com/). VIA allows you to quickly change your keymap without flashing or a QMK build environment. I highly recommend it for experimenting. There are few downsides:
- it doesn't support custom logic like a key for switching betwen Mac/Win
- the exporting/importing keymaps has some problems with some multi-chord keys though typically I don't find I need to export/import
- lighting configuration keys only seem to affect lighting on the master side. If you don't change lighting much, a workaround is to plug just the right side in to the computer, change the lighting then plug everrything back normally

To use the VIA firmware

- Clone https://github.com/brianlow/qmk_firmware
- Switch to the `choc-brian` branch with `git checkout choc-brian`
- When flashing use the `choc_brian` keymap: `qmk flash -kb sofle/rev1 -km choc-brian`
- Download the VIA app from https://caniusevia.com/, it should recognize the keyboard when it opens

## Troubleshooting

See the Sofle build guide.

## Links

- [Github with KiCad projects][soflegithub]
- [Layout in KeyboardLayout editor][soflechoclayout]
- [QMK Firmware][qmk_firmware]
- [QMK Configurator][qmk_configurator]

## Default layout

The default layout for the Sofle Choc is in the QMK fork and demonstrates some LED functions.

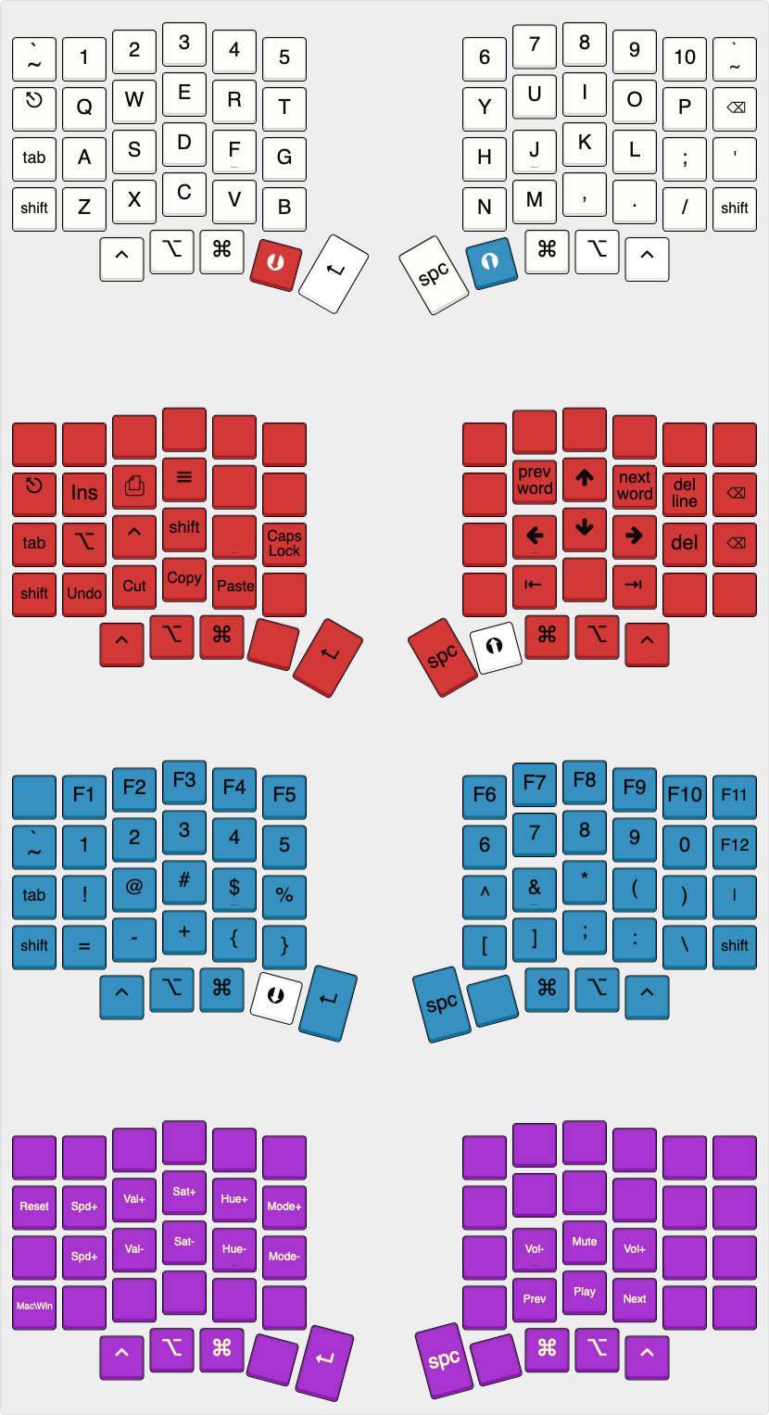
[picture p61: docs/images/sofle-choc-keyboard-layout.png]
Default layout for Sofle Choc Keyboard


## Images of keyboard

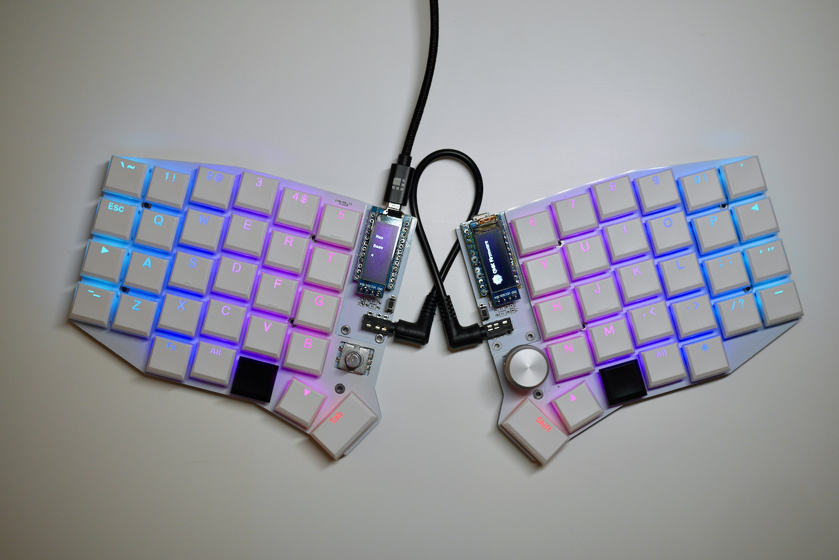
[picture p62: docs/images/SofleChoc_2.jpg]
Keyboard Photo 1


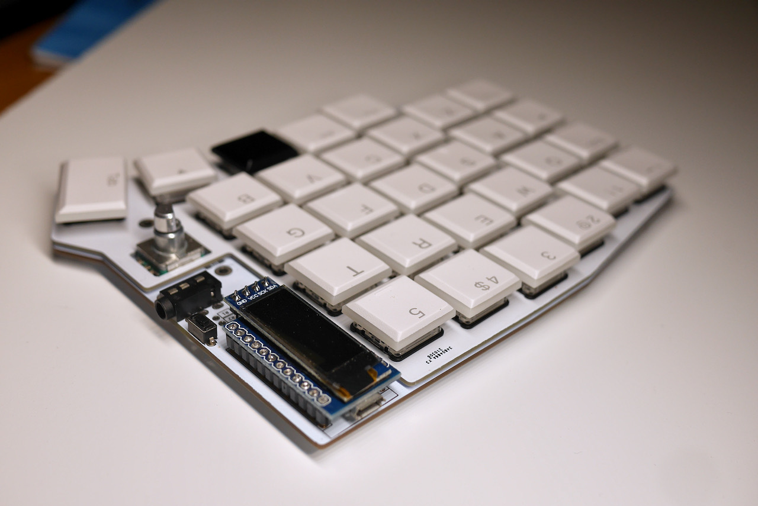
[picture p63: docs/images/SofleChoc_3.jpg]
Keyboard Photo 2


## Version History

* v2.1.1 - Top plate: moved the version label to less visible location, widened the area above the encoder. PCB version remains at v2.1
* v2.1 - First published version

## Footnotes
[layoutarticle]: <https://josef-adamcik.cz/electronics/in-search-of-the-best-custom-keyboard-layout.html> "In search of the best custom keyboard layout"
[introductionarticle]: <https://josef-adamcik.cz/electronics/let-me-introduce-you-sofle-keyboard-split-keyboard-based-on-lily58.html> "Let me introduce you SofleKeyboard - a split keyboard based on Lily58 and Crkbd"
[soflelayout]: http://www.keyboard-layout-editor.com/#/gists/76efb423a46cbbea75465cb468eef7ff "Sofle Keyboard layout at keyboard-layout-editor.com"
[soflechoclayout]: http://www.keyboard-layout-editor.com/#/gists/5604075ad16c10a8c634828c5911d2b6 "Sofle Choc Keyboard layout at keyboard-layout-editor.com"
[soflegerber]: https://github.com/josefadamcik/SofleKeyboard/releases "SofleKeyboard - gerber files"
[qmk_firmware]: https://github.com/qmk/qmk_firmware/ "QMK firmware"

[qmk_configurator]: https://config.qmk.fm/#/sofle/rev1/LAYOUT "QMK configurator"
[springpinheader]: <https://yushakobo.jp/shop/a01mc-00/> "Spring pin headers - Japanese"
[qmkprotonc]: https://qmk.fm/proton-c/ "QMK Proton-C"
[promicrosocketing]: <https://docs.splitkb.com/hc/en-us/articles/360011263059> "How do I socket a microcontroller? by splitkb.com"
[qmkintro]: <https://docs.qmk.fm/#/newbs_getting_started> "QMK getting started"
[qmkhandedness]: <https://docs.qmk.fm/#/feature_split_keyboard?id=setting-handedness> "QMK firmware - setting handedness"
[manufacturingproblems]: https://josef-adamcik.cz/electronics/corne-keyboard-build-log.html#manufacturing-at-jlcpcb---update-27112019 "Possible problems when manufacturing top plate for Corne"
[nooledlag]: https://github.com/qmk/qmk_firmware/issues/7522 "No OLED lag bug"
[soflegithub]: https://github.com/josefadamcik/SofleKeyboard "SofleKeyboard - KiCad project on Github.com"
[sourcing]: <{{ site.baseurl }}/sourcing_parts.html> "Sourcing parts"

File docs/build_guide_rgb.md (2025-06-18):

---
layout: default
title: Sofle Keyboard - build guide (RGB)
---

The Sofle RGB is a copy of the Sofle V2 with the addition of up to 36 RGB leds per side. If you are just looking to try out that layout, and are using the cherry sockets only, then this will work for you. Please mind that the layout has slight modifications, mainly the pinkie stagger is less aggresive than for non-RGB Sofle V2.

This version rolls back the original pro-micro pinout (to the state it was for V1) and improves routing.

## This Build Guide

This build guide is based on a copy of the main [build guide][buildguide]. We suggest to revisit the main [build guide][buildguide] for general process and tips about technique. But this build guide is the main source of important details for your build - like Pro-Micro orientation, component placement etc.

**&#9888; Keyhive version: Pay attention, if you purchased Sofle RGB from Keyhive**

One keyboard vendor - Keyhive - is selling their own fork of Sofle RGB. This version is **modified** in way that makes it **incompatible** with the **firmware** for the official designs. Also this build guide no longer applies to their version. 

**&#9888; If you purchased their modified version, you have to use the firmware provided by the vendor and [the build guide provided by them as well][keyhivebuildguide].**

Please, don't report problems with the design by Keyhive and or firmware to the official Sofle Keyboard repository. Their modification is not part of the repository and therefore we can't fix any problems and we can't help with any problems you might have with the design. Contact the vendor instead. In the end, you are their client.

## Bill of materials

The following is needed to build the keyboard.

- **2 PCBs**, ** NOTE: ** There is an issue with the v2.0 boards. See the Troubleshooting section at the bottom of the page for further details if you were unlucky enough to get a board made with these files. 
- **2 top plates**, **2 bottom plates** for a sandwich-case build.

- **2 Pro Micro** board or clone. With 2x12 pins and ATmega32U4 microcontroller. Just make sure you **don't** buy something like Arduino Micro (a different pinout) or Arduino Mini (different microcontroller). You could also use Elite-C which basically Pro Micro with USB-C.
- **4x12 pin header (and optionally socket)** for Pro Micros. There are several ways how to mount Pro Micros to the board. Either the male PIN headers you most likely got with the board from the supplier could be used to solder it directly to the board. Build guides for Helix, Corne and Lily58 suggest [those spring pin headers][springpinheader] which are very compact and give you non-permanent connection (you can remove or replace Pro Micros). Another possible approach [is described at splitkb.com][promicrosocketing].

- **58 keyboard switch sockets by Kailh**. The PCB supports sockets for traditional MX switches. They are available on Aliexpress, KBDFans and others.
- **58 keyboard switches** of your preference, MX. Just make sure you have matching sockets for them.
- **58 keycaps**. You can use either all in `1u` size but it looks nicer with two `1.5u` for the thumb keys.
- **58 diodes  1N4148W**. They are surface mount diodes in SOD123 package.
- **2 TRRS connectors PJ-320A**. The same type which is used for Corne, Lily58 etc. Technically even TRS should work[^1] if you stick to (default) serial communication. 
- **2 tactile buttons** through-hole, 2 pins. Technically optional: you can use metal tweezers whenever you need to reset the microcontroller. There's also a reset key on default layout so as long as you have firmware flashed and working you shouldn't need reset button on the board. 
- **1 TRRS cable**. TRS should work if you stick with Serial. 
- **10 (+4) M2 spacers**. 10 are going to hold the bottom and the top together. Their height depends on which switches you use. A build guide Lily58 Pro suggests  `7mm` for MX. I was not able to get `7mm`, but `6mm` worked well for me with MX switches. I used brass ones but you can also buy nicer from anodised aluminium. 
- **20 (+8) M2 screws**. 20 are going to hold the boards together (via spacers). I used some I had in my stock so I am not going to tell you exact length. But they need to be long enough to fix a `1.6mm` thick PCB to the spacer and short enough so two of them can fit in one spacer (might be trickier with 4mm spacers for Choc switches)
- **8 - 10 adhesive rubber feet**. They are really important, trust me.
- **Micro USB Cable** to connect the keyboard to a computer.

**Optional**
- **OLED/s**
	- **2 ssd1306 128x32 OLED display module**. Very common everywhere. 
	- **2x 4 pin header (and optionally socket)** for OLEDs. I have used the most common 1x4 female pin sockets which are quite tall but they also fit the height of ProMicro with the sockets I have used. Unfortunately, the pin headers on my OLED modules (again those very common square male headers you would get with the modules) are loose in the sockets. It works but it's fiddly. I'll have to find a better solution.
	- **2 OLED cover** This is available in [the repository (oled_cover.svg)](https://github.com/josefadamcik/SofleKeyboard/tree/master/Sofle_RGB/Case/)
	
- **Rotary encoders**
	- **2 Rotary encoders EC11**, If you are not sure take EC11E. Some other variants (EC11K) may have some additional plastic pins for and require mounting holes for them (which are not included on the PCB).
	- **A matching knob** for each encoder. 
	
- **LEDs**
	- **SK6812 mini rgb leds (3.5mmx3.5mm size)** make sure that you get the style with irregular shaped pads that are flush to the led, and make very sure that you know what the pinout for your variant is. There are at least  2 common pinouts, thankfully just rotated 180 degrees, but for you the pin 1 marking may be on pin 3.
		- **2x forward facing layer indicator**
		- **12x rear facing drop lights**
		- **58x per key lights** 

## Tools and materials

- soldering iron
- solder 
- good tweezers
- masking tape
- isopropyl-alcohol for cleaning
- screwdriver

## Steps

### Prepare

Make sure you know which side you are working on, and don't make two left hand sides by mistake 

### The LEDs
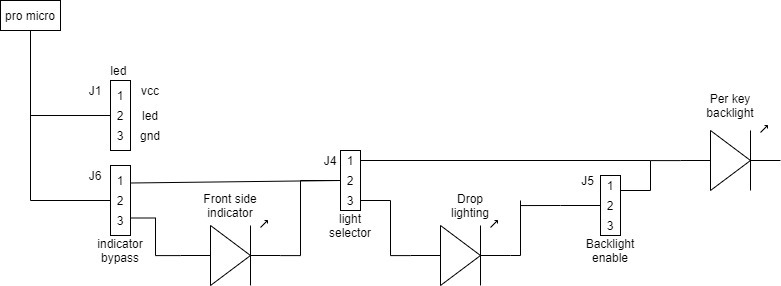
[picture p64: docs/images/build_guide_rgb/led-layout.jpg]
SofleKeyboard


Work out what leds you wish to have, I have endeavoured  to provide plenty of flexibility, and all led configurations are available using the headers available. If you wish to experiment, use 2.54mm headers and jumpers. If you know what you want, use a solder bridge to enable the leds required.  
The traditional LED header is available, and can be used alone, or theoretically fed back in to one of the other headers if so desired. 

Make sure you know which way around your leds are, different brands have different pin 1 positions. Thankfully it appears that the pad pattern underneath is consistent, so use it. I recommend doing one LED and testing it before continuing. This unfortunately suggests soldering the micro on first, despite it making the back side harder to solder. A good alternative would be to use an existing keyboard with leds to inject the signal and power through the LED header.

#### LED pinouts

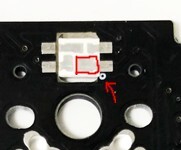
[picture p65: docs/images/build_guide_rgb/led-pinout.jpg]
LED pinout from the crkbd build guide. I've found this to be the only consistent method


The above picture is from the crkbd guide shows pin 4 on the table (the table is viewed from the top of the LED). 

**The sofle RGB uses the following table, with the silkscreen marking at pin 1 (Dout)**

| pin | net | net | pin |
| --- | --- | --- | --- |
| 1 | Dout | Vcc | 4 | 
| 2 | Gnd  | Din | 3 | 

Using the base pattern is the only consistent pattern between at least two different models with different pin 1 definitions and markings.

The following two datasheet excerpts show two versions of the led with different numbering pattern. But shows the same layout and net labels on the bottom.

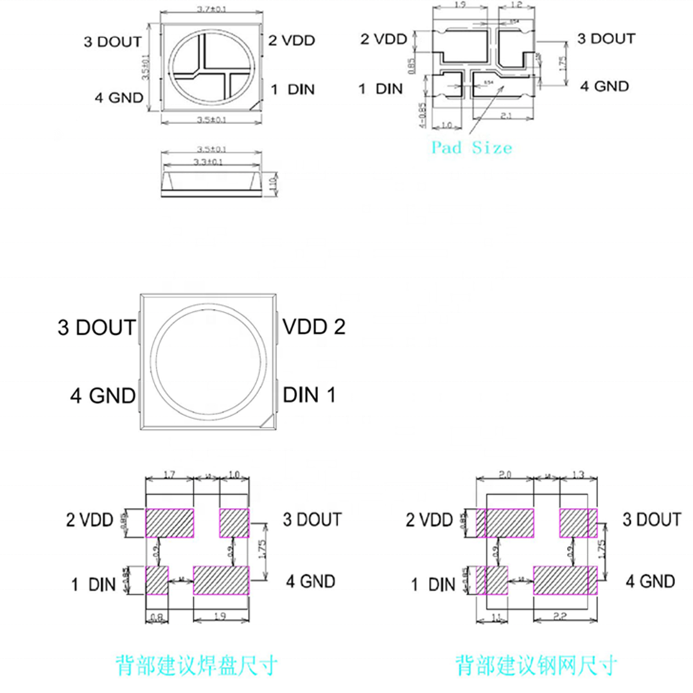
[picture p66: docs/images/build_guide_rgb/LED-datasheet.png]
datasheet


**Soldering** 

The surface mount LEDs are easier to solder, and there are only 1+6 of them on each side, so are a good place to start if you aren't used to soldering them. Use a fairly low temperature (240c) and lots of flux. Place the led in position, heat one of the pads on the board for several seconds before moving the iron to touch the pin on the led , then add solder. Moving the iron back and forth from the pin can help to flow the solder under the LED, 

I have added a single LED to the top surface to act as a layer indicator, this is enabled by bridging 2-3 on J6(indicator bypass).

To enable drop lighting, short pins 2-3 of J4(Light select), to enable only per key lighting short pins 1-2 of J4. 
If you wish to use per key lighting, you also need to short pins 1-2 of 5. 

| Indicator | Drop lighting | Per key 	| j6(Ind Bypass) 	| j4(Light select) 	|j5(Backlight) 	| 
| :---: | :---: | :---: | :---: | :---: | :---: |
|  N  |  N  |  N  | |	| |
|  N  |  N  |**Y**| 1-2 | 1-2 	| |
|  N  |**Y**|  N  | 1-2 | 2-3 	| |
|  N  |**Y**|**Y**| 1-2 | 2-3	| 1-2 |
|**Y**|  N  |  N  | 2-3 |	| |
|**Y**|  N  |**Y**| 2-3 | 1-2 	| |
|**Y**|**Y**|  N  | 2-3 | 2-3 	| |
|**Y**|**Y**|**Y**| 2-3 | 2-3	| 1-2 |

The per key lighting is painful and slow. For these it is definitely best to do them in order, and test regularly. Use as low a temperature as you can manage, place the board flat on a table, and drop an led in. Create a solder bridge from the led to the board, not spending too much time with the iron on the led (few seconds) otherwise it will burn out. 

If the part of the string stops working, resolder the last working one, and the first to fail, then if needed replace them. 

#### LED Layouts 
** Indicator + drop lighting  **
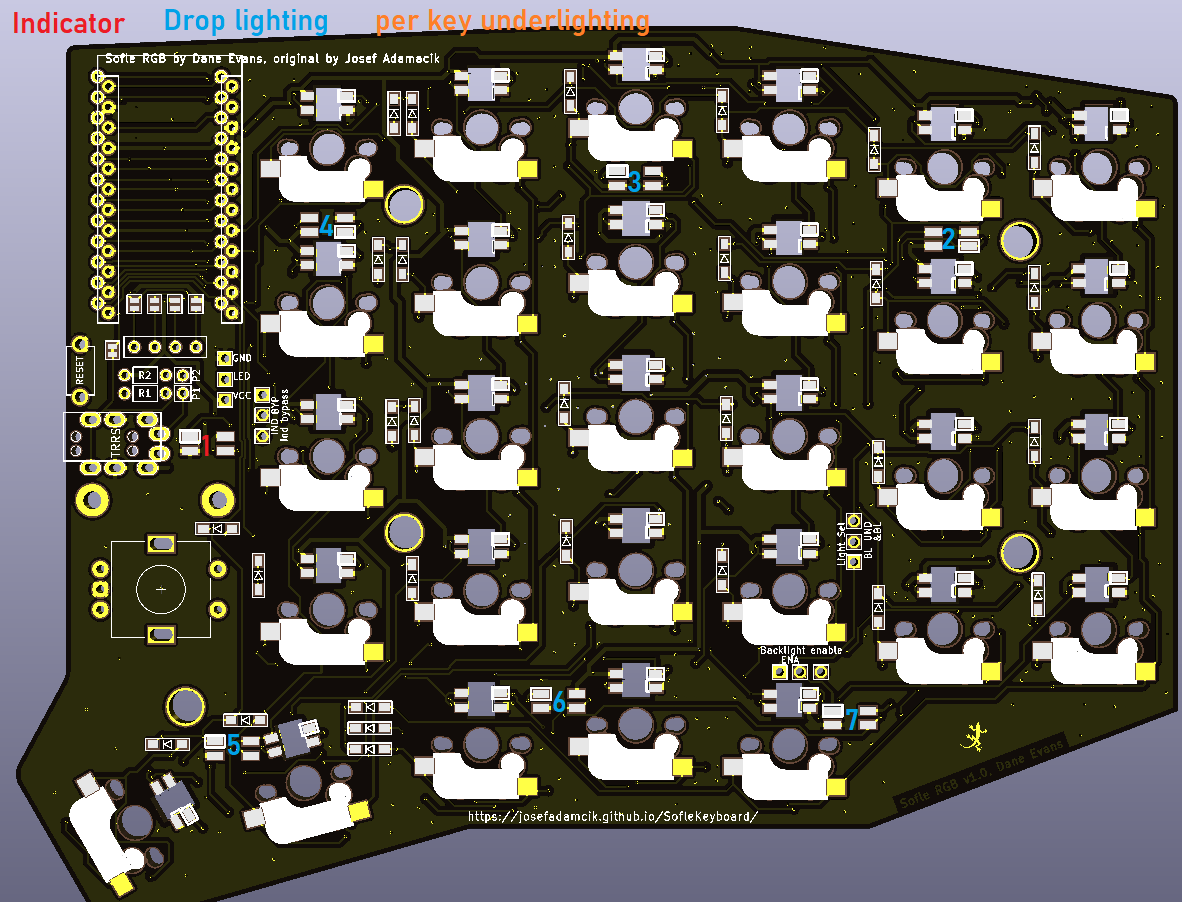
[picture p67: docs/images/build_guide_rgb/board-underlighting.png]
LED layout underlighting

** Indicator + per key lighting  **
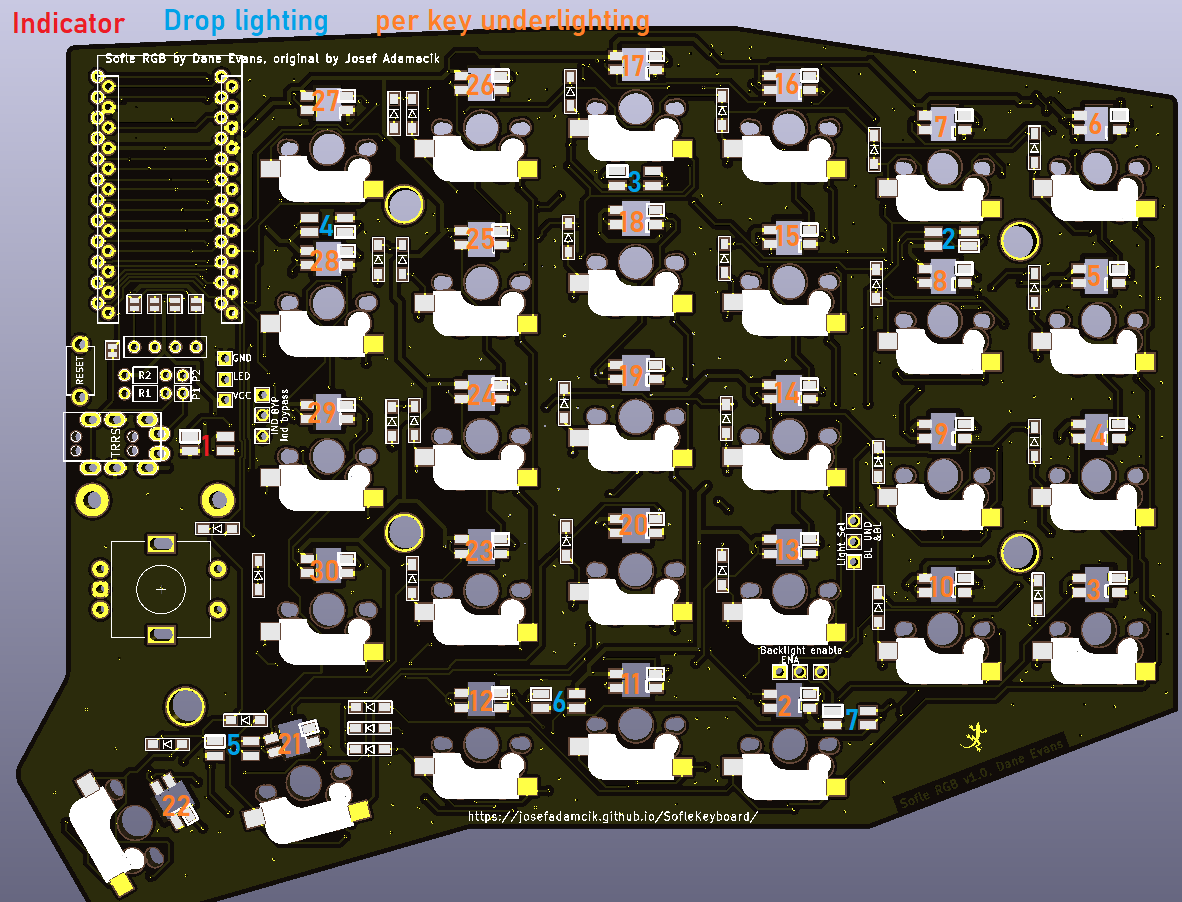
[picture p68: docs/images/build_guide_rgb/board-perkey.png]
LED layout per key

** Indicator + drop lighting + per key lighting **
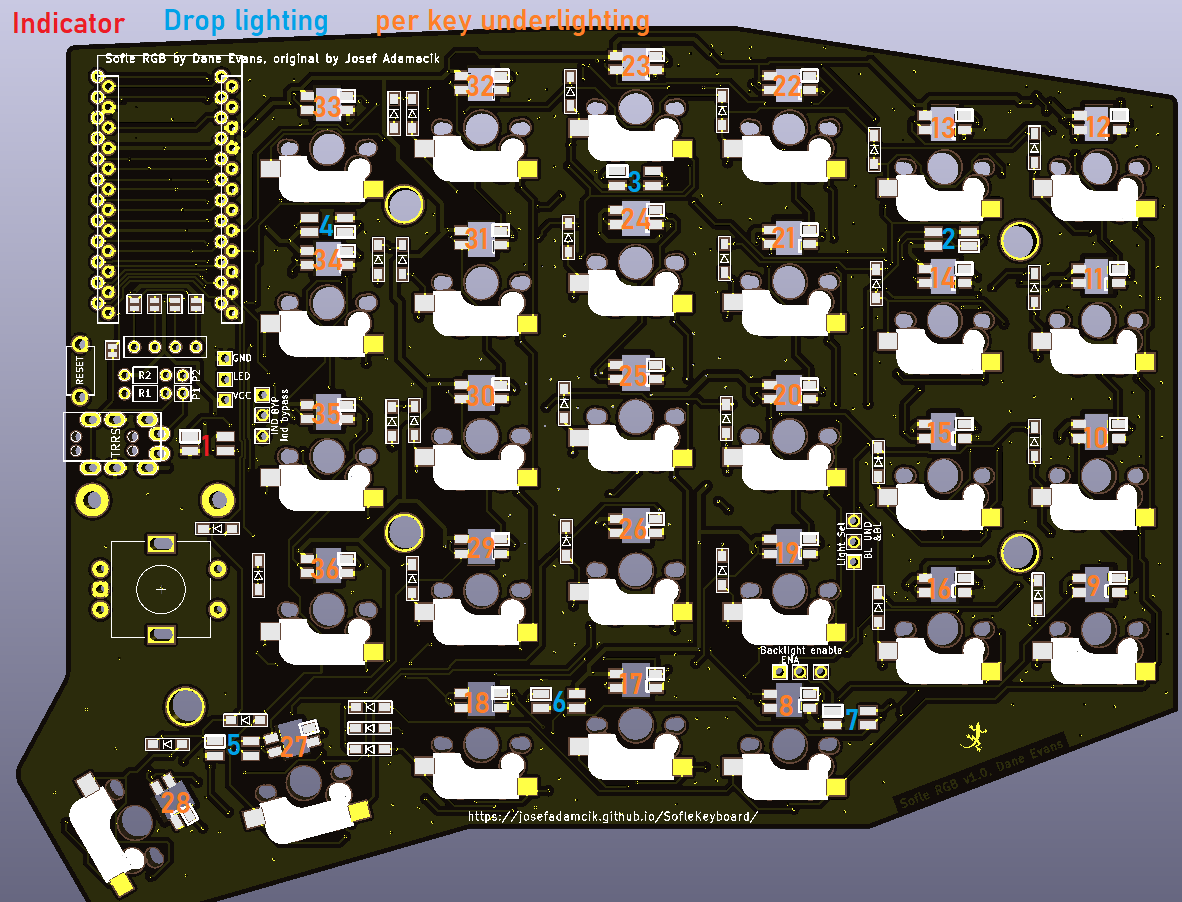
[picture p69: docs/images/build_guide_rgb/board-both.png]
LED layout both


### Components on the backside

- Start with the diodes. Make sure you have orientation right - they are all oriented to the same side. The end with the thin line is Cathode (-) and it should go in the direction of the "arrow" symbol on the PCB.

- Sockets for switches belong again on the back side, the same side as diodes. Make sure they are flush with PCB and match the orientation shown on the silkscreen. 

### Bridge the oled pads
This is done on the top side, all 4 solder bridges must be completed. This is easier before the pro micro headers are soldered 

### Components on the front side

- Button and TRRS sockets belong to the top. Use a piece of tape to fix them and apply solder from the bottom side.

### Pro Micro and displays

- The pro micro must be installed with the components facing the pcb, and the plain back side facing out. Theoretically I think these could be installed on the under side for a lower profile. 

Make sure that you use the outlined headers from whichever side of the board that you mount the micro on. 

- Install the oled so it sits over the pro micro 

### Rotary encoders

- Add rotary encoders last, they are big, and make soldering harder 

### Keyboard switches and plates

- Mount the stand-offs to the top plate.

- Snap first switches into corners of the plate.

- Carefully snap the first switches to the sockets. Be careful so you don't bend their contacts.

- Add the rest of the switches

- Mount the bottom plate.

### Finishing touches

- Install the rotary encoder knob.

- Optionally add oled covers

- Put at least 4 adhesive rubber feet in the corners so the keyboard is not moving when you type.

## Warnings and disclaimers

- Don't connect or disconnect the TRRS cable when the keyboard is powered. It may short out. Always disconnect the USB cable first.
- Be gentle with micro USB ports on your microcontrollers. They are easy to break.
- Keep in mind that this is a prototype of a DIY keyboard. It's not a polished product.

## Firmware and programming

Sofle keyboard uses [QMK Firmware][qmk_firmware] and support for the board is part of the main QMK repository. There's also a basic support in [QMK Configurator][qmk_configurator] but there's no encoder  or led support.

Suggested approach is to build the firmware yourself. You should be familiar with QMK and be able to make it work on your local environment. If not, please [follow the instructions in the documentation][qmkintro].

- Make sure your QMK environment [is setup][qmkintro].
- Make sure halves are not connected together with TRRS cable.
- Connect one half to USB, flash the firmware (always follow the actuall instructions in the QMK documentation! The command might look something like this: `qmk flash -kb sofle/rev1 -km rgb_default`). Use the reset button to reset the keyboard when you are asked to in console. 
- Connect the second half and flash it in the same way as the previous one.
- Disconnect the USB cable. Connect both halves together with TRRS cable.
- Connect USB cable to the **left** side. 
- Enjoy SofleKeyboard!

## Troubleshooting

See the Sofle build guide.

**V2.0 Boards** - There is a known issue on V2.0 boards with the LED circuit - a trace is missing to a via on the underside of the board (on top on the left half)

Symptoms: only the first 4 underglow LEDs will work, this will occur on both halves of the board, 

Remedy: This can be easily corrected by adding a wire between the via and the trace immediately above it in the picture. You may need to scrape off the solder mask on the via depending on which manufacturer you used. 
The other end can either be attached to the trace (after removing some mask), or the footprint/led itself. 

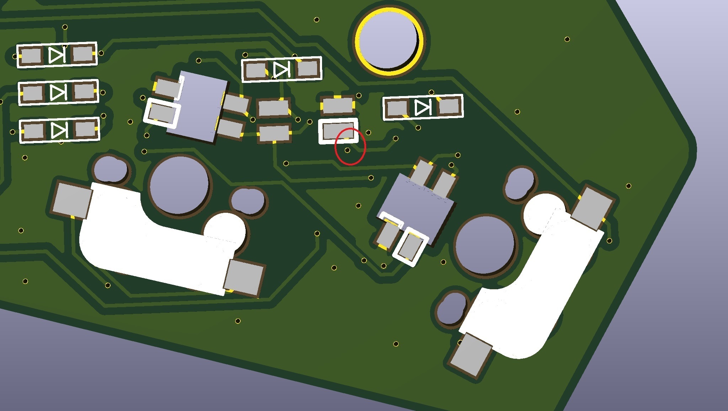
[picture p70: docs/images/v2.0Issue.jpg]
Problem Via, In the thumb cluster on the left half of the board.


This has been corrected in the v2.1 boards, and hopefully hasn't caught too many people out. Thanks to jmo808 for finding it, and apologies once again. 

## Links

- [Github with KiCad projects][soflegithub]
- [Layout in KeyboardLayout editor][soflelayout]
- [QMK Firmware][qmk_firmware]
- [QMK Configurator][qmk_configurator]

## Firmware 

SofleRGB uses [QMK firmware](https://qmk.fm/), it can use any Sofle keymap. 

## Default layout 

The default layout for the SofleRGB is in the qmk repo, and demonstrates some LED functions. 

Default layout for SofleRGB Keyboard

## Images of keyboard

SofleRGBKeyboard

SofleRGBKeyboard

SofleRGBKeyboard PCB

## Footnotes
[layoutarticle]: <https://josef-adamcik.cz/electronics/in-search-of-the-best-custom-keyboard-layout.html> "In search of the best custom keyboard layout"
[introductionarticle]: <https://josef-adamcik.cz/electronics/let-me-introduce-you-sofle-keyboard-split-keyboard-based-on-lily58.html> "Let me introduce you SofleKeyboard - a split keyboard based on Lily58 and Crkbd"
[soflelayout]: http://www.keyboard-layout-editor.com/#/gists/76efb423a46cbbea75465cb468eef7ff "Sofle Keyboard layout at keyboard-layout-editor.com"
[soflegerber]: https://github.com/josefadamcik/SofleKeyboard/releases "SofleKeyboard - gerber files"
[qmk_firmware]: https://github.com/qmk/qmk_firmware/ "QMK firmware"

[qmk_configurator]: https://config.qmk.fm/#/sofle/rev1/LAYOUT "QMK configurator"
[springpinheader]: <https://yushakobo.jp/shop/a01mc-00/> "Spring pin headers - Japaneese"
[qmkprotonc]: https://qmk.fm/proton-c/ "QMK Proton-C"
[promicrosocketing]: <https://docs.splitkb.com/hc/en-us/articles/360011263059> "How do I socket a microcontroller? by splitkb.com"
[qmkintro]: <https://beta.docs.qmk.fm/newbs/newbs_getting_started> "QMK getting started"
[qmkhandedness]: <https://docs.qmk.fm/#/feature_split_keyboard?id=setting-handedness> "QMK firmware - setting handedness"
[manufacturingproblems]: https://josef-adamcik.cz/electronics/corne-keyboard-build-log.html#manufacturing-at-jlcpcb---update-27112019 "Possible problems when manufacturing top plate for Corne"
[nooledlag]: https://github.com/qmk/qmk_firmware/issues/7522 "No OLED lag bug"
[soflegithub]: https://github.com/josefadamcik/SofleKeyboard "SofleKeyboard - KiCad project on Github.com"
[sourcing]: <{{ site.baseurl }}/sourcing_parts.html> "Sourcing parts"
[keyhivebuildguide]: <https://github.com/keyhive/build_guides/blob/master/docs/keyboards/sofle-rgb.md> "Sofle RGB Keyhive build guide"
[buildguide]: <{{ site.baseurl }}/build_guide.html> "Sofle V1/V2 build guide"

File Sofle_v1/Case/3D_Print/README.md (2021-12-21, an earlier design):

# Sofle Keyboard 3D Printed case

I added 3D printable STL files for Sofle Keyboard. Unfortunately, while I was trying to make sure that the board fits, Sofle v2 was launched and it doesn't work with the case I designed. If you still would like to use my case, you can find them under Sofle\_v1/case/3D\_print/ along with palm rests.

sample image

Case was CNC cut from STL file, palm rest was printed with ANYCUBIC i3 MEGA, PLA, 0.3mm layered.

plugging hole

I adjusted plug holes according to original sofle board. Instead of making it tight, I made the space large enough for better compatatibility.

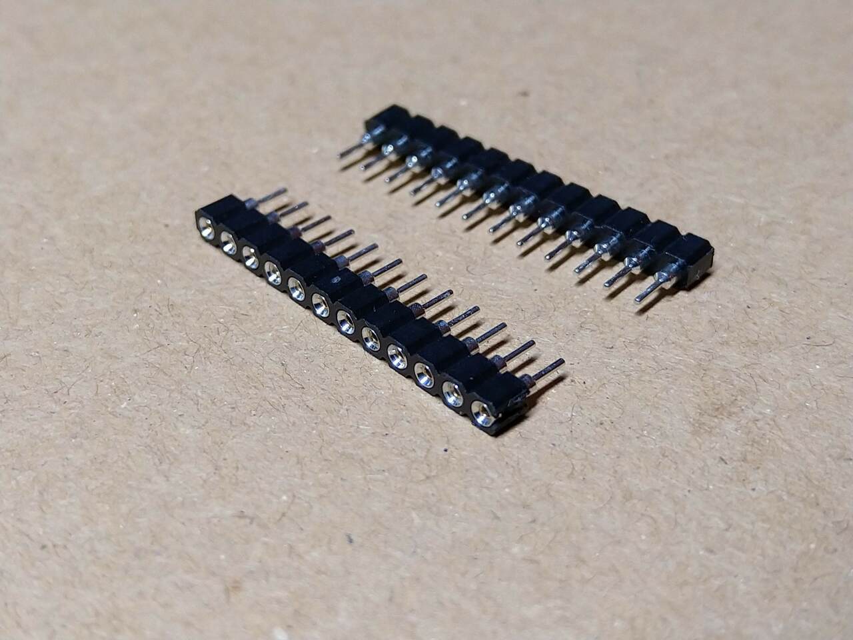
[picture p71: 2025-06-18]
docs/images/build_guide/IMG_20191106_210011.jpg

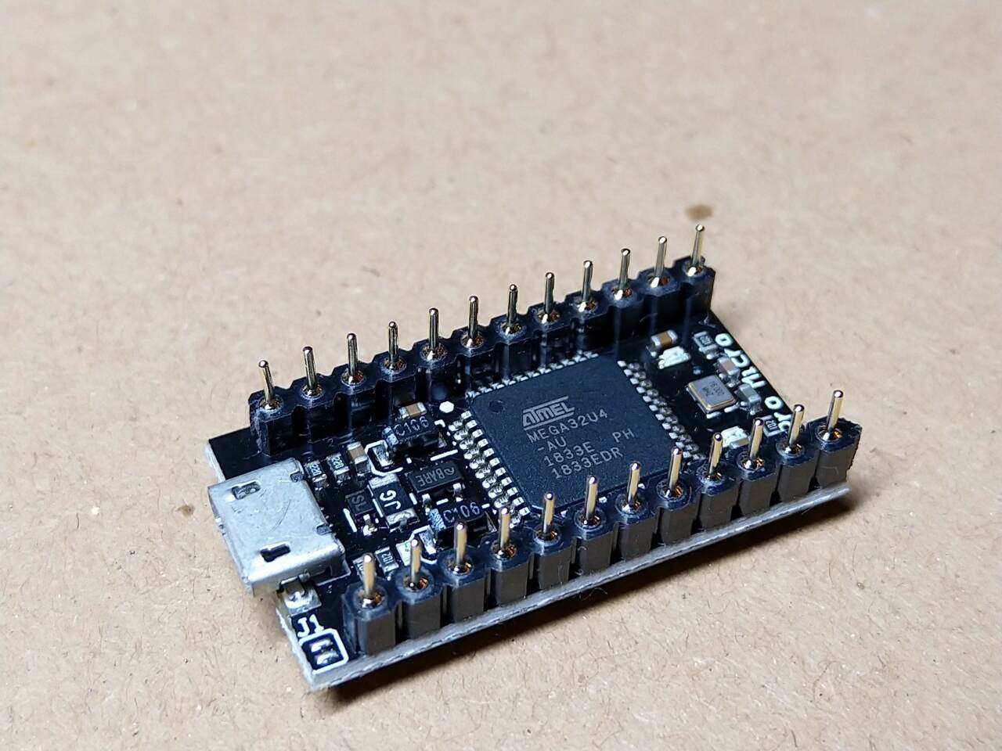
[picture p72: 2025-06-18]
docs/images/build_guide/IMG_20191106_205952.jpg

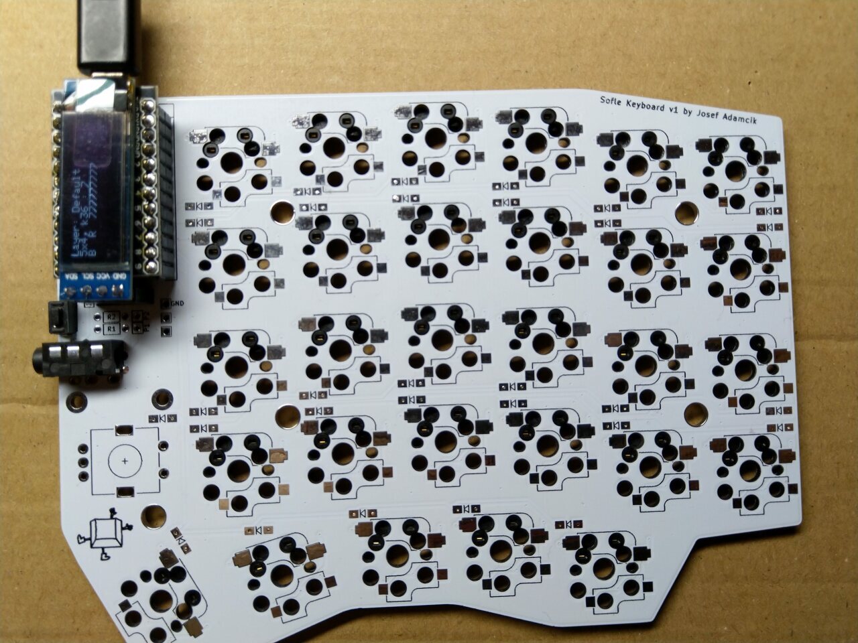
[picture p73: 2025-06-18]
docs/images/build_guide/IMG_20191106_212033.jpg

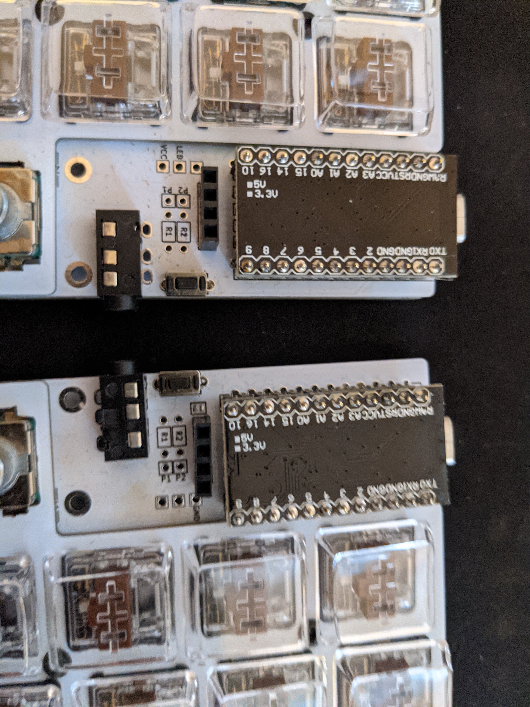
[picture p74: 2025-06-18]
docs/images/build_guide/micro_placement_v1.jpg

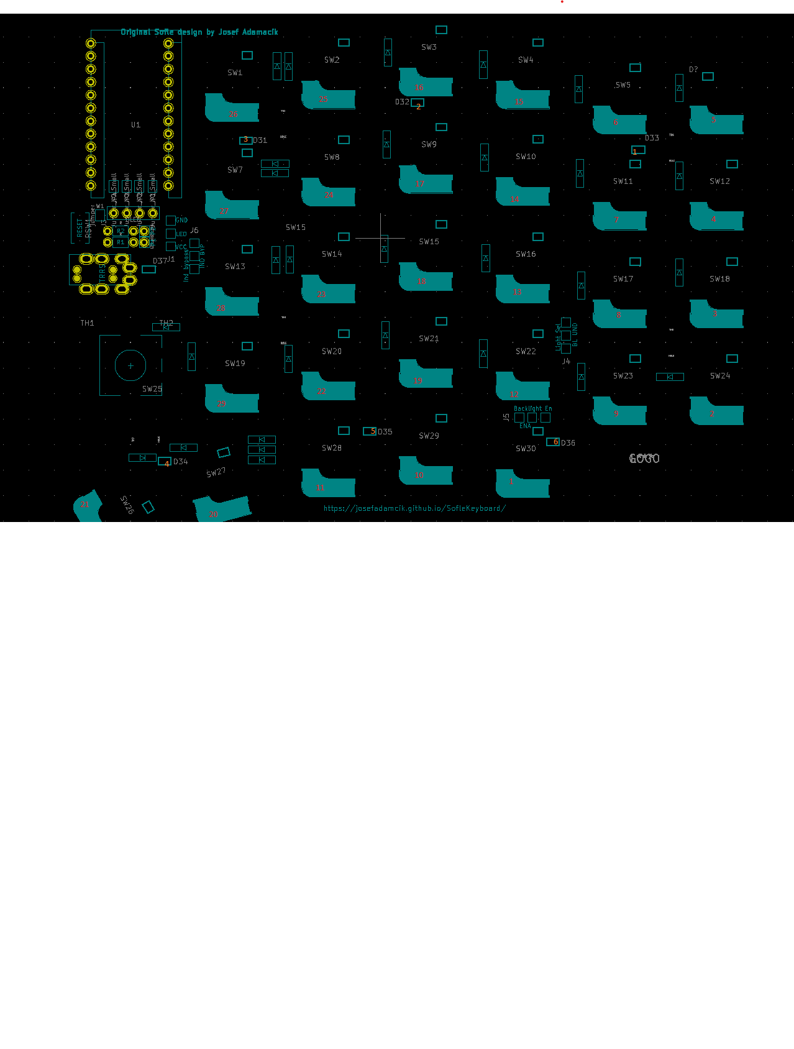
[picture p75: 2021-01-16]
docs/images/build_guide_rgb/perkey lighting.png

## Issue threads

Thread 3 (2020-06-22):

Inverted silkscreen?

AlexDaniel, 2020-06-22:
What about inverting the silkscreen on most of the PCBs? Like [here](http://ncmachineworks.ca/wp-content/uploads/2014/01/PC280491.jpg). It adds an extra layer and makes PCBs feel nicer. Also, with some fabs there is a cost for non-green PCBs, but the silkscreen fill esentially makes them white. I'm personally interested in black boards, but black soldermask from JLCPCB feels junky so I want to try my luck with white PCBs and inverted silkscreen (which should be black).

josefadamcik, 2020-06-22:
@AlexDaniel it might be interesting visually, but is there a way how to do it easily without loosing the ability to change the PCB design easily? Personally I have never tried to invert silkscreen so I don't know what are the options.

For me it sounds more like some kind of post-processing step: take exported Gerbers and run both silkscreen layers through some kind of inverting script.

AlexDaniel, 2020-06-22:
> easily

Well, maybe not as easy. But you can have text and other stuff on ECO layers, and then subtract it in gerbers. Maybe [this](https://forum.kicad.info/t/negative-silkscreen/11849/3) is a good start.

Another option is to have silkscreen artwork in SVG and then just import it into KiCad. It requires an extra step to bring in the updates but it's not too bad.

josefadamcik, 2020-06-22:
> > easily
>
> Well, maybe not as easy. But you can have text and other stuff on ECO layers, and then subtract it in gerbers. Maybe [this](https://forum.kicad.info/t/negative-silkscreen/11849/3) is a good start.

Thanks for the link, it's interesting. But sadly not really practical way. The text is not the only thing on silkscreen. There are also symbols which are part of the footprints and that would be the more difficult part I would say. And they even have to use external script: gerber_combine -> i think something like that is more what you need - have a way how to say negate my silkscreen (which is something like substract it from something which is completely filled in so it might be possible to abuse gerber_combine for that purpose).

>
> Another option is to have silkscreen artwork in SVG and then just import it into KiCad. It requires an extra step to bring in the updates but it's not too bad.

I would do that if there actually was some artwork I would care about. I have done some things  by combining SVG made in inkscape and KiCad (and importing/exporting things in both directions) ant it is indeed powerful approach. But it's also a lot of overhead. Doing it just to invert silk screen is too "expensive". I would prefer automated way that allows me to keep the project maintainable.

Also, I am quite sure it doesn't really make sense to have this as default - all my Sofle builds are made with white soldermask and black silkscreen and they look pretty good. I had Corne made with black-matte silkscreen from JLCPCB and it looked also very good (the only problem I had was that it was almost impossible to clean it nicely after soldering, at least I didn't find a reasonable way). Of course, this is highly subjective but there are plenty of people who might not like inverted silkscreen.

What I am trying to say here is: of course I am sure it's possible to do and of course I would be able to figure out why if I really wanted to. But for me this is something that you could do before you order PCBs yourself and doesn't have to be part of the repository. And if it was part of the repository it should a an optional post-processing step - e.g. a python script which would process the gerbers to make the change.

AlexDaniel, 2020-06-22:
> There are also symbols which are part of the footprints and that would be the more difficult part I would say

Any reason you can't move them to another layer? If it's just text, then right click on the text, Properties, Layer → Eco1.user. If it's part of the footprint, then Ctrl+E to edit it in the footprint editor.

However, I agree, it should be other way around. We should draw the silkscreen fill on the eco layer and then subtract the normal silkscreen from it.

> all my Sofle builds are made with white soldermask and black silkscreen and they look pretty good

That's alright aesthetically, but white color is perhaps the least functional for keyboards because of the grime and stuff.

Anyway I'll take a look on how to achieve it in the easiest way before making my order, and I'll submit a PR with instructions or scripts.

AlexDaniel, 2020-08-10:
If anybody is interested, I made an order for white boards with inverted silkscreen. I'll describe the process in a bit more detail later if the boards are fine.

joaommartins, 2020-08-24:
> If anybody is interested, I made an order for white boards with inverted black silkscreen. I'll describe the process in a bit more detail later if the boards are fine.

I'm interested since I intend to order from JLCPCB and it's my first time ordering pcbs at all.

AlexDaniel, 2020-08-24:
@joaommartins I hope you can wait a little bit. My boards were manufactured on 2020-08-16 but I chose the cheapest delivery option. The boards have various improvements to them, not just inverted silkscreen (something I intend to report as bugs soon). That said, I won't be sharing any files until I actually get the physical boards. I looked at the production files and JLCPCB did some undesired changes to the gerbers, especially the silkscreen. When I asked them not to do it they didn't really understand what I was trying to say… So I have to see how the boards turned out before I can recommend anything :)

joaommartins, 2020-08-24:
@AlexDaniel Not a problem at all, I'll be keeping an eye on this repo and learning about pcb manufacture meanwhile.

AlexDaniel, 2020-08-27:
They arrived! Looks pretty good to me, I'll explain the process in detail a bit later and also show some photos.

AlexDaniel, 2020-08-28:
OK, here are most of the details for making boards with inverted silkscreen.

Let's say you wanted to have a solid board (like the bottom plate) with silkscreen across the whole board, with no markings or logos (just solid silkscreen fill). Can you just cover the whole board with a polygon on the silkscreen layer? Like this:

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

The answer is yes, but with two caveats.

### 1. Pads
If you have any pads, most manufacturers will remove silkscreen from them. However, it is not guaranteed, as demonstrated by this famous case:
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
([source](https://www.eevblog.com/forum/projects/silk-screen-on-exposed-pcb-pads/))

KiCad allows to “exclude pads from silkscreen” when you generate the gerbers, and you probably want to make sure that the checkbox is checked:
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
There is also a “Subtract soldermask from silkscreen” option but I personally think it is too much. It will create holes for pads that are even bigger, but due to silkscreen misalignment it can expose some of soldermask too.

### 2. Edge cuts
If you make your silkscreen exactly the same size as your board, keep in mind that the silkscreen is the most imprecise part of your boards. Usually, the silkscreen layer will be misaligned at least a bit, if not a lot. This means that your silkscreen polygon will be shifted, revealing soldermask on the edges of your board. Here's an example:
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
(boards for [one of my older projects](https://progarm.org/))

On the image above you can see green soldermask being visible on the left side but not on the right side, that is because of the silkscreen misalignment. The solution to that is to make sure your silkscreen overlaps the board edge, this way the mill will go through your silkscreen when cutting the board edge leaving no visible soldermask. However, this didn't really work for my JLCPCB order, and this is what they did for the production files:
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
(This is the screenshot that I was using when I was trying to explain the issue to JLCPCB, they still didn't get it though. The image on the right is the original gerber file, the image on the left is their production files. The arrow shows what you should want your gerber files to be, but the sad reality is backwards :) )

Notice that not only did they cut the silkscreen layer based on the outline, but they also made sure that it is inset by a small amount. That is, when ordering from JLCPCB, *you will always have a soldermask outline near all of the board edges*. This is how it looks like:
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

Notice that there is a white outline near all of the board edges.

When I asked JLCPCB not to do that they didn't really understand my request. I think it's much easier to embrace this limitation – just add an intentional 1mm-1.5mm silkscreen outline for all of your edge cuts. It will add contrast, making the board look more stylish.

### How to invert the silkscreen

Now, the process for inverting the silkscreen can be different depending on what exactly you want to achieve. For the top and bottom plates it is sufficient to simply add a polygon on silkscreen layers that covers the whole board. This is what I did, because I didn't want to have any graphics there anyway. You may choose to do it differently.

For the main board, however, I still wanted to have normal silkscreen markings for the components. So here is the process:
1. Generate gerbers with your normal silkscreen. Rename your silkscreen gerber files so that you know that this is the original silkscreen.
2. Add a polygon to silkscreen layers that covers the whole board. Generate the gerbers again.
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
josefadamcik, 2020-09-06:
@AlexDaniel Thank you very much for taking the time to write this down and also to create issues for all the problems with the design you have noticed. I think I'll create a small section in the documentation (something like "Modifications") and link this issue & your comment from it so people can find it if they prefer inverted silk-screen.

To the bugs: I'll leave them (at least most of them) here among issues open, but I am most likely not going to fix them in the first version of the design. But it's great feedback and I'll make sure the next versions doesn't have the same problems (at least in the cases where I would be able to find the solution). Thanks again.

AlexDaniel, 2020-09-06:
@josefadamcik thank you for a great project! The documentation is very nice!

olDirdey, 2024-11-05:
@AlexDaniel can you explain what you have changed in the gerber combine scrypt? in my output the silkscreen looks exactly the same as before, nothing is deducted after the script has run

AlexDaniel, 2024-11-05:
@olDirdey if I remember right, there were some obvious python errors, probably because the script is rather old. The script is written in python2 which isn't even easy to install nowadays. But, if you're able to run it without errors, then you're good!

How are you running it? Are you providing two files? Are you using the `-s` flag?

olDirdey, 2024-11-05:
@AlexDaniel thanks for the feedback. unfortunately I have no knowledge of python to find an obvious error. I use the command "python gerber_combine.py full.gbr -s text.gbr -o final.gbr" full is my filled area and text.gbr is the text i want to subtract from it. but the output file is the same as the file with the full area

AlexDaniel, 2024-11-05:
Based on the command history, I see that I was using this command:
```
./gerber_combine.py -s silkscreen-magic/SofleKeyboard-B_SilkS_FULL.gbo silkscreen-magic/SofleKeyboard-B_SilkS.gbo
```
I don't know if the order of arguments is important, but that's something to try. If you don't see any errors, then I think the script is fine.

olDirdey, 2024-11-05:
thanks again. I will try a little bit

Closed 2020-12-21.

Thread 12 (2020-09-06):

Add a warning that sockets need to be in the right orientation

AlexDaniel, 2020-09-06:
The build guide stresses that diodes should be in the right orientation:

> Starting with the diodes. They belong to the backside of the PCB. Make sure you have orientation right - they are all oriented to the same side.

However, it does not say anything about the orientation of sockets:

> Sockets for switches belong again on the back side, the same side as diodes. Make sure they are flush with PCB.

Of course, the sockets are drawn on the silkscreen so it should be hard to get it wrong… That being said, because of how nicely they snap into the board, it is easy to think that there is no wrong way to insert the sockets. Also, because it is a repetitive operation, it is probably possible to get just a few wrong.

Don't ask me [how I know](https://user-images.githubusercontent.com/5507503/92330354-d7781600-f076-11ea-8774-2a2e91f1eac2.jpg)! :facepalm: Fixing it requires [a jig](https://user-images.githubusercontent.com/5507503/92330367-f8d90200-f076-11ea-91a3-e14af6b241b9.jpg) to put light pressure through one of the holes while applying heat to the pads. Go slow and switch between the pads often. It will take an [an hour or so](https://user-images.githubusercontent.com/5507503/92330370-fc6c8900-f076-11ea-9749-aa50db0f22e6.jpg) to fix the whole board. Both the PCB and sockets can then be reused.

josefadamcik, 2020-09-07:
@AlexDaniel ouch, painful mistake.

I'll update the guide and mention to pay attention to the orientation on silkscreen.

Closed 2020-12-21.

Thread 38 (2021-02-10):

Sofle RGB has an unconnected via for NET34. Underlight LED circuit.

jmo808, 2021-02-10:
I temporarily worked around the issue by scratching the soldermask off and globbing some solder. I will submit a PR in the next few days.

DaneEvans, 2021-02-11:
That's a weird one.

Thanks for the quick turnaround, hopefully doesn't catch anyone else out, I
know there are a few people looking at making one.

I'll check it out tomorrow probably, if you haven't submitted one by then.

On Thu, 11 Feb 2021, 10:25 am Jules Ouellette, <notifications@github.com>
wrote:

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

jmo808, 2021-02-11:
Here's some pics as an FYI.
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
Second pic has where the missing trace was circled in red. It's an easy fix in KiCad

jmo808, 2021-02-16:
I finished building both sides of the keyboard and have verified that this fix does indeed work. So I will submit the PR soon.

tiadobatima, 2021-02-26:
Howdy... I'm wondering if this PR has been merged? I gave a quick look and didn't see any merges related to that in the last few days, but I could have missed something. I'm gonna wait for it before ordering :)
And thanks for the fix! ❤️

josefadamcik, 2021-02-26:
> Howdy... I'm wondering if this PR has been merged? I gave a quick look and didn't see any merges related to that in the last few days, but I could have missed something. I'm gonna wait for it before ordering :)
> And thanks for the fix! ❤️

Hi @tiadobatima, there has been no PR opened yet.

jmo808, 2021-02-26:
Sorry for the delay, I have gotten busy with work and haven't had the chance to submit this PR. I still need to load the JLCPCB DRC rules into KiCad and export the gerber. I'm also working on another PR for a 3d printed high profile case.

tiadobatima, 2021-02-26:
I'm so sorry... I didn't mean to put any pressure. I know everyone is busy. I just wanted to make sure I didn't miss the boat :)
Thank you again for doing this!

DaneEvans, 2021-02-27:
I'm in the same boat, work has been absolutely hectic.

I'm hoping to get one out this weekend. And update the documentation to
mention the issue in the R1 boards.

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

DaneEvans, 2021-02-27:
I've submitted a merge request with a new version of the board, and updated the documentation.

@tiadobatima, wait a day or so for Josef to accept it, or you can pull it from my repo.

Thanks jmo for finding (and immediately solving) the issue - My apologies for the hassle, I never made the 2.0 boards, they just fixed a few issues I had in 1.0, and somehow I missed a missing net in the DRC.  How I have no idea, because I now I ran the checks, and it showed up as son as I ran them to start the fix.

Closed 2021-02-27.

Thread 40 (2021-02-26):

v2 Choc RGB variant

brianlow, 2021-02-26:
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

I am working on variant that supports Kailh choc switches, hotswap sockets and per-key RGB. Based on @DaneEvans's Sofle RGB (thanks).

Pull Request:
https://github.com/josefadamcik/SofleKeyboard/pull/104

Welcome feedback and/or collaboration with anyone interested.

#### TODO
- [x] Verify hardware
  - [x] switches
  - [x] OLED
  - [x] LEDs
  - [x] encoders
  - [x] split
- [x] Firmware
  - [x] basic setup
  - [x] split config
  - [x] keymap
  - [x] LED config
  - [x] LED physical positions
  - [x] cleanup
- [x] PCB v2.1
  - [x] fix traces too close to pads
  - [x] bump version to 2.1
  - [x] better led orientation marks
  - [x] change all markings to silkscreen
  - [x] vertically enlarge encoder cutout on top plate
  - [x] regenerate gerbers
- [x] build guide
  - [x] controller orientation
  - [x] LED orientation, order, soldering tips
  - [x] BOM - no spacers needed
  - [x] top plate is not compatible with original/rgb
  - [x] photos
  - [x] firmware
- [ ] publish
  - [x] PR to this repo
  - [ ] PR for qmk firmware

DaneEvans, 2021-04-07:
I'm happy to do reviews if you need before releasing gerbers

brianlow, 2021-06-11:
Update: one half is built and working. Everything is tested except for the encoder and TRRS connector. One trace is a bit too close to a pad and requires careful soldering but otherwise good

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

josefadamcik, 2021-06-19:
Well done, people keep asking about low profile Sofle V2 and this is even RGB. Once you have the final design, feel free to open a PR to this repository and we could talk about merging it. Of course only if you want. There is nothing wrong with having your own version / fork.

dattanchu, 2021-07-28:
@brianlow This is fantastic work. From the commit log, it looks like this support both mini-e and choc switch? Is the pcb files ready for physical production?

Can you elaborate on the hard-to-solder spot you mentioned please? My experience is limited to a non-led sofle RGB and would like to try my hands on a choc board for personal use.

brianlow, 2021-07-28:
> it looks like this support both mini-e and choc switch?

Yeah!

> Is the pcb files ready for physical production?

Short answer is not yet. Long answer: I am feeling pretty good about it. Most of the 2nd half is going. I've got a few keys/leds that probably need some soldering touch ups. I haven't tried connecting the halves. If you are adventurous I suspect it is ok to build. If you'd like I can make a few changes, like fix the hard to solder spot.

> My experience is limited to a non-led sofle RGB

You should have no trouble soldering this. I am a hobbist too. The SK6818 mini-e LEDs have been fairly easy. I've only over-heated or mis-soldered a couple leds.

brianlow, 2021-07-28:
Changes I was thinking
- [ ] inner thumb key, right side has a trace too close to the pad for the socket. I am surprised DRC didn't flag this. **Any suggested settings so this problem, and any others, are found automatically?**
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

- [ ] top plate: cutout for the encoder is just a 1-2mm too small vertically
- [ ] some of the text done with solder mask (?) isn't visible at least on white PCBs, change to silk screen

DaneEvans, 2021-07-28:
Did you run DRC?  For some reason kicad makes this easy to skip.

Check your rules too, but yeah, that should have been picked up I would
have thought.
Kicads DRC isn't the most intuitive, and a lot of things are turned off by
default.
Maybe increase the number too.

I'm a little surprised that the PCB house ran it.  Maybe it's not as bad as
it looks on the screen cap.

Text is usually either done in silk, copper, or mask over copper, mask
alone isn't common, bare FR4 isn't very attractive, and it only works with
coloured masks

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

brianlow, 2021-07-28:
@DaneEvans thanks!

I was just experimenting with Footprint Editor -> select pad -> Properties -> Pad Clearance = 0.30 (default was 0). With this, the DRC finds this problem and a few others.

> I'm a little surprised that the PCB house ran it.  Maybe it's not as bad as it looks on the screen cap.

Here is a screen cap with measurement:
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

I ordered from JPCB. Maybe this is normal clearance and I was just too sloppy / too hot with soldering and lifted the soldermask or something.

DaneEvans, 2021-07-28:
That still sounds like a trace clearance number is too low, a pad clearance of 0 can't be normal, it has to be added to a trace one that's .3 or similar I would think.

I do know I had similar issues where it allowed auto route to do things that seemed completely unreasonable. Thankfully I caught them.

That one also looks to be inside the solder mask cutout!
I think JLC charges more for them to check it, some of the others have a DRC tool on their upload site.

For a board like this, hand soldered by hobbyists, I aim for 2 layers,
1+mm clearance, and more around pads.
Good gaps between diodes etc
And fairly wide traces, at least one to 2 sizes up from the default.
Obviously that depends on density, but there is heaps of space on these

brianlow, 2021-07-28:
> a pad clearance of 0 can't be normal, it has to be added to a trace one that's .3 or similar I would think

Looks like 0 means it inherits "from the parent footprint" but I can't figure out from where. "Default Pad Properties..." seems to only affect newly drawn pads.

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

> For a board like this...

 That is great info, I'll try to incorporate

brianlow, 2021-07-31:
v2.0 hardware is working!

I think safe to say ok to build this version. Happy to help any builders with gotches mentioned earlier. Will work on v2.1 PCB but no timeline.

I've added a TODO list to the issue description. Will keep updated.

dattanchu, 2021-07-31:
Fantastic news. Given that I am working on my second sofle RGB board at the moment, I am gonna wait for the potential v2.1. For my shopping cart, I assume I can use the choc V2 switch as well?

brianlow, 2021-07-31:
[Kailh Choc v2 PG1350](https://www.aliexpress.com/item/32959996455.html) and will need matching [sockets](https://www.aliexpress.com/item/33023283633.html) (required)

josefadamcik, 2021-08-14:
Hi @brianlow, I am just putting together a yearly article "What's happened around Sofle in the last year" and I  am going to  mention  your modification. Can I use one of your photos from above in the article? And maybe later on the website (https://josefadamcik.github.io/SofleKeyboard/) as example of mods to the design? I'll credit you of course (and can link your website or something if you wish).

brianlow, 2021-08-14:
> Can I use one of your photos from above in the article?

Cool, yeah for sure. I am super close to opening a PR for this repo if still interested. Can probably open one this weekend.

blewisemt, 2021-11-08:
Super excited to have found this. Still trying to make heads or tails of the github and how to put one of these together, but this is precisely the keyboard I have been looking for.

lytedev, 2021-11-09:
@blewisemt I just finished my build. I have a number of extra PCBs if you want to avoid some of the process.

Download the gerber files and upload to JLCPCB (or wherever you want). https://github.com/brianlow/SofleKeyboard/tree/choc/Gerbers/Choc
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
blewisemt, 2021-11-09:
@lytedev if you happen to have some, that would definitely streamline the process. Having never attempted such a project before, how do I know what all I need?

brianlow, 2021-11-09:
@blewisemt

> how do I know what all I need?

Go to PR #104 -> Files tab -> scroll down to `docs/build_guide_choc.md` to see the build guide. All the linked images are also in the PR. To view the guide as a formatted web page you'll need node and jekyll to compile it if I remember correctly.

This is a pretty rough project. Only 2 keyboard have been built as far as I know. If you want something a little more mature, check out the Lily58 and Iris. Both support choc, have kits available and good docs.

blewisemt, 2021-11-10:
Thanks for the feedback. I've ordered all of the components, as well as the
PCBs. Assuming my skills are up to the task, there should be a third
floating around soon! Anything in particular I should be on the lookout
for? I'm still working my way through the contents of the PR, and the PCB
design in particular.

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

lytedev, 2021-11-10:
@brianlow The build went great! I had absolutely no issues with the PCBs or plates. I would love to get into PCB CAD and figure out how to customize these things to my needs or even learn to make parametric PCBs to people could swap different components easily somehow.

My build is fully wireless using Nice!_Nano MCUs and ZMK-based firmware. I added hard power switches for even better battery life and the board has been wonderful.

I see no reason this shouldn't be merged, but again, not a PCB expert. Also just realized you included a build guide! Fantastic!

@blewisemt I was able to build it without even the build guide, but this is not my first build, so I was pretty familiar with the basics and the process as a whole. If you follow the build guide and make sure no power is running through anything while you're working (no batteries or cables connected) you will do just fine. It sounds like you already ordered PCBs so you don't need any from me!

If you have any issues, feel free to reach out!

Here's a pic of mine:

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

brianlow, 2021-11-10:
@blewisemt that was fast! Great to hear. Hopefully the build guide has everything you need. Ask if not and I can improve the guide.

@lytedev great build, thanks for posting. Power switch on the pcb would be a great option

josefadamcik, 2021-11-14:
@lytedev Thanks a lot for building, testing and reporting back :)

blewisemt, 2021-11-20:
Hi all. Got my keyboard assembled. The build guide was extremely straightforward, and it functions *almost* perfectly. So where did I go wrong? I used the via setup, and all the keys work, but only the first vertical column on each half lights up. Thoughts?

brianlow, 2021-11-21:
@blewisemt

Some ideas
* try the non-via firmware
* replace the first broken LED and the one immediately before it

For reference the LED configuration in `keyboards/sofle/keymaps/choc-brian (or choc)/config.h`. E.g. here is the via version:

https://github.com/brianlow/qmk_firmware/blob/5264ae0ce57033322638b87ada26a377a4b25eab/keyboards/sofle/keymaps/choc-brian/config.h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

blewisemt, 2021-11-21:
So the first vertical column on each side works, and all of the LEDs test as functional. I wanted to run the non via firmware but I can’t seem to figure QMK out.

Sent from my iPhone

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

blewisemt, 2021-11-22:
This seemed to rectify my LED issues. However the OLEDs no longer display
anything and I cant seem to figure out how the layer up and layer down keys
work. Thanks for all the support thus far btw!

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

brianlow, 2021-11-22:
@blewisemt please submit a new issue on this repository (probably type Help Me) with details. This is a closed issue and posts here will notify everyone watching. What action fixed the leds? If you revert that action does the oled work again. What firmware are you running?

researcherx00, 2021-12-14:
@lytedev Still have any spare PCBs?
If so, can I get a set? 🤞 😄

brianlow, 2021-12-16:
@researcherx00 contact me at the email on my GitHub profile. Might be able to help

killua99, 2022-01-25:
@lytedev can I reach you out about ZMK firmware and dead OLED? thanks in advance and sorry for the mention

killua99, 2022-03-31:
@lytedev thanks, actually I got the OLED working, not the version RGB v2.1 is my next challenge, I still can not make LEDs to work. Using nice!nano v2 and ZMK firmware, since the Bluetooth support is the main feature I´m looking for.

If I made some advance on it perhaps I'll update this comment to don't cause more notification on old threats

brianlow, 2022-04-01:
@killua99 lets collect ZMK info in a dedicated issue since this one is closed: https://github.com/josefadamcik/SofleKeyboard/issues/142

Closed 2021-11-14.

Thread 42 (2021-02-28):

Question about LED soldering

armageddion, 2021-02-28:
This isn't an issue, so please close if inappropriate.

Any tips on SMD soldering of the LEDs? I managed to get a few working on my Sofle RGB build, but i feel that it was more luck than skill. I used plenty of flux and minimal soldering temp and time. Here are a few things that I tried:

Method 1: I tried to apply a small amount of solder to each pad, place LED and blast it with a heat gun. That got the LED attached (on all 4 pads it seems) but the LED wouldn't work.

Method 2: Apply solder only to 1 pad, attach LED to that pad. Then feed solder to remaining 3 pads.

Method 3: Apply solder on all 4 pads on the PCB, place LED on top. Apply low downward pressure on LED with tweezers. Melt solder on each pad until LED sitting comfortably in place.

I suspect that I might fry the LED in method 1, but 2&3 shouldnt suffer from that. I am scouring the net for helpful tips on this, so I thought i'd ask here as well since I suspect I'm not the only one having this challenge.

DaneEvans, 2021-03-01:
None of those sound like a good idea to me.

The ideal would be solder paste, and an oven or wave solder rig.

The best luck I've had has been to flux the PCB,
then put the led on in the right orientation,
Hold it in place, while you use an iron with a blob of solder on it to heat
the PCB pad. Once it flows, touch the iron to the led and the edge of the
LED pad a couple of times.

It's a much easier job than the per key ones.   Bridging the pads without
frying the LED is awful. Particularly if your LEDs have any contamination
on the pads.

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

armageddion, 2021-03-01:
Thanks for the prompt response.
Will try what you suggest.

Side note: this is one epic keyboard and a fun build.

DaneEvans, 2021-03-01:
Haha, I try to be quick so that the RGB stuff isn't too much of a hassle to
Josef, given that he sensibly avoided them. They are a lot of work.

Also, did you have a V1.0 board? Have you seen issue #38?

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

sdkrocks, 2021-04-06:
> I did see that issue, but I didn't get that far yet. I am still on the Indicator LEDs.
Did you get anywhere?

I am having a similar issue. Can't get the indicator lights to work, have resoldered them with new leds a bunch of times at this point. Shows no signs of life.

DaneEvans, 2021-04-06:
Which version of the board do you have SDK? I know 1.0 and 2.0 people
succeeded with, except for issue #38, if you have a 2.1 it's possible but
unlikely for there to be a hardware bug.

If you have an RGB strip you can check the routing quite easily and
eliminate issues other than the LED orientation and soldering.

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

DaneEvans, 2021-04-07:
Added to build guide a few commits ago

Closed 2021-04-07.

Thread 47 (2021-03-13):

JP9/10/11 are not mentioned in the build guide

baruch, 2021-03-13:
The V2 PCB has these jumpers but no mention of them in the build guide. It seems that one should choose if he wants serial or I2C over the TRS/TRRS cable and that defines which cables can be used and I'm left wondering what should be the criteria to make the choice besides the cable (I will have TRRS cable). Will there be a benefit for using I2C over serial in this case?

josefadamcik, 2021-03-13:
@baruch Short answer: there is no benefit and no reason to do any choice. Just go with the default.

Longer answer:

They are not  mentioned mainly because it's not necessary nor advised to do anything with them. It's only part of the design we are inheriting from older designs and they are not usually documented (e.g. corne, lilly, helix - afaik their documentation also didn't mention what to do with those jumpers and when).

My plan was to eventually experiment with i2c and determine which one to use on my own.

But  according to my research among QMK community members, the serial protocol is considered to be better than i2c for QMK split keyboard. There are several reason for this which are discussed over and over in the QMK discord and I bet I don't even remember all of them - just from the top of my head there were problems with reliability with longer cables (coiled etc.) and multiple problems with OLED displays connected at the same time on i2c bus.

If I ever get to version 3, I would probably remove i2c support completely and remove all the oddities around (TRRS cable and connector which is not needed).

baruch, 2021-03-13:
OK. But it looks like I need to close JP11 to get serial on V2.0.1, is that correct?

josefadamcik, 2021-03-13:
@baruch No, that is not correct. As I said above, there's no need to do anything with any of those jumpers. That is why they are not mentioned in the build guide.

If you open the pcb in KiCad, you can see that the jumper is already bridget. You would have to cut the trace between pads if you wanted to switch to i2c.

baruch, 2021-03-13:
OK. Thanks!

Closed 2021-03-13.

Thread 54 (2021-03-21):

Are capacitors missing on the SK6812MINI?

joecabezas, 2021-03-21:
I am reading the datasheet of the SK6812MINI, and in the `The typical application circuit` section it suggests to put a capacitor on each LED:
https://cdn-shop.adafruit.com/product-files/2686/SK6812MINI_REV.01-1-2.pdf

image:
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

it seems like is possible to avoid it, but others suggests is better to have one:
https://electronics.stackexchange.com/questions/392925/can-i-replace-these-many-capacitors-with-just-one

Is there any specific reason the RGB version does not include capacitors?

DaneEvans, 2021-03-21:
In short, probably laziness.

No other keyboard I've seen or built has them, most likely because the
pioneers didn't want to solder another 60ish passives.

It's probably a good idea, although a PC power supply probably has a lot of
capacitance itself.

  I don't know about one on every LED, but some bulk capacitance on board
would reduce microcontroller hangups when you plug the USB in. I've never
had the micro brownout when switching all the LEDs to White, or had them
fail to read the Din signal which are usually the symptoms that individual
caps are designed to correct.

It's a 'won't fix' at this point.  It's a proven design, and the same as a
lot of other keyboards. If I do a new spin of the board I may add
footprints for them, but it won't go into the recommended build

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

joecabezas, 2021-03-22:
thank you for the explanation <3

also, the capacitor is not intended to protect the the (pro)micro, but the controller inside the LED, which can cause on animations to flicker, still thanks for answering and confirming it is laziness, I wanted to also be lazy on my design, please have a good night, I am closing this

Closed 2021-03-22.

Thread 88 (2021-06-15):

Help: Can't get RGB working

lukeraphael, 2021-06-15:
**Kind of issue?**
Assembly

**Which Board?**
RGB

**Which Board Revision?**
2.1

**What is the issue?**
Unable to get the rgb working

I have checked my soldering and led orientation several times but am still unable to get the rgb working. May I know what I am doing wrong? Below are the photos of my board. Thank you so much.

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

These are the leds im using: https://www.aliexpress.com/item/32885017817.html?spm=a2g0s.9042311.0.0.1b434c4dUy0i5k

DaneEvans, 2021-06-16:
A) are any of them working
B) have you bridged the indicator bypass jumper (these are designed to be done with a little bare copper or a solder ball, rather than the large wires. It won't cause any issue, but it's a lot neater)

lukeraphael, 2021-06-16:
Thanks so much for the quick reply!

A) None of them are working

B) Yep, I agree it's a lot neater, but wanted to test out the leds before tidying up. I have actually bridged j6 with a solder bridge and the others with wires. I couldnt quite get the solder bridges on the other jumpers hence the wires. I'll clean them up once I manage to get some leds working.

DaneEvans, 2021-06-16:
Is the micro staying powered? Is it programmed? It it outputting to the
LEDs? (This is where a short strip into the LED header is useful)

Are they getting 5v?
Check on any LED footprint or the LED header.

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

lukeraphael, 2021-06-16:
The pro micro is powered and programmed with the rgb default in the repository.

1) Attaching a short LED strip did indeed work with no other changes to the board as shown below

2) I don't have a potential meter hence I can't test whether they are getting 5v. Is there any other way to check?

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

lukeraphael, 2021-06-20:
I have found out the issue - An LED is soldered to the indicator position on the underside which causes all the lights to fail. Thank you for all the help!

DaneEvans, 2021-06-20:
Unless it's the wrong orientation, it shouldn't matter which side of the
board it is on.

Glad you found it anyway

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

lukeraphael, 2021-06-21:
I actually replicated the issue several times as I had multiple boards soldered in the same way.

Maybe it's worth checking out. I'll try to replicate it again when I build another one.

Closed 2021-06-20.

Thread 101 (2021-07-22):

Help: what behaviour is expected when testing LEDs?

adzwoolly, 2021-07-22:
**Kind of issue?**
Assembly / HELP!

**Which Board?**
RGB

**Which Board Revision?**
RGB =  2.1

**What steps have you taken**
* [✓] I have searched the Issues page
* [✓] I have read the documentation
* [\~] For LED issues I have checked the following things
        - [\~] the pro micro is programmed [✓] (and currently telling the LEDs to do something [I'm not sure - I'm on base layer, I think it should be])
        - [✓] the pro micro is powered (and showing LEDs)
        - [✓] the LEDs are powered (check 5v across pins 1 and 3 of J1) - measures 4.72v
        - [x] are any of the LEDs showing

**What is the issue?**
I'm having issues getting any of the per-key LEDs to work (I've only done per-key ones for now).

My question: when testing the LEDs as you solder, what behaviour should they exhibit?

I've started from LED 8 and tested each one as I go using a bench power supply (set to 5v) across ground and VCC.  Each LED shines green when it is soldered.  In the chain, only the last LED lights up (green) and previous LEDs, when individually powered no longer light up.  Is this what is expected?

**What you expected:**

* [ ] Unknown

**Extra notes / questions**
I've made one side so far and wanted to test it on its own to see if I'd soldered everything correctly.  I'm not sure if this is possible by default (or at all), or if I'd need to modify the keymap to do so.

The OLED screen and the keys all work, just the LEDs I'm struggling with.

This question is my first step to making sure I'm doing this correctly.  Any other advice is also appreciated if applicable.  Thanks.

adzwoolly, 2021-07-25:
I decided to try and solder everything and replace LEDs that didn't light up individually (about 50% of them).   Unfortunately I've resoldered stuff so many times I've started to expose PCB copper.  I think I'm just going to use it as a non-RGB Sofle.  My keycaps aren't shinethrough anyway.

Closed 2021-07-25.

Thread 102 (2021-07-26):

4th row not working on right side

Spaubleit, 2021-07-26:
**Kind of issue?**
Assembly, HELP!

**Which Board?**
Original

**Which Board Revision?**
2.0

**What steps have you taken**
* [x] I have searched the Issues page
* [x] I have read the documentation

**What is the issue?**
English not my native language and this board was my first serious soldering experience. I'm sorry for silly mistakes.
When I assemble board I noticed that right display not working. This is not a problem for me. But after some test I found that 4th row on my right side not working either. I checked all лов display contacts and found short circuit between SCL and SDA contacts. After removing display the short circuit is preserved on the contact pads of the board. Could it be related to the broken key row? What tests need to be done to determine the problem? Thank you.

DaneEvans, 2021-07-26:
Most likely causes to take a whole row out are a bad row diode, or bad
soldering at the micro.

Check the schematics to figure out which ones to look at.

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

Spaubleit, 2021-07-27:
Hi. I checked all the diodes and they are fine. But there is no contact between row 4 on controller and switches. And there is issues with display contacts. Is my board broken?

DaneEvans, 2021-07-27:
I doubt it.

The display intentionally needs solder bridges, and there is nothing on the
board that even the cheapest manufacturer should screw up.

 Get the PCB layout and buzz it out if you're worried.  But it will either
be the row 4 diode, which could be either dead or badly soldered, or the
row 4 pin.

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

Spaubleit, 2021-07-28:
It's not the manufacturer. It's me who desolder broken sockets from the board using air gun. As I said it's my first soldering experience so I made many mistakes. Anyway it looks like I need to order new boards. Thank you for help and this beautiful keyboard. My left side looks fantastic.

DaneEvans, 2021-07-28:
What weight copper did you use?

These should be pretty tough, assuming 4-6 Oz copper.  For hand soldering,
especially with an entry level iron, you want at least that heavy

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

Spaubleit, 2021-07-29:
I don't really know. Because I ordered complete keyboard set from a store. I was just stupid. I used heat gun set on 250C. It melted my controller sockets and created bubbles under solder mask. Some tracks was ripped off. I was surprised that keyboard is still works. I save my board by the way. Now I have hand wired row :)

Closed 2021-07-28.

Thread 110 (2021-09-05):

Help: OLEDs not working with Elite-C v4

HybridFox, 2021-09-05:
**Kind of issue?**
Help

**Which Board?**
Original

**Which Board Revision?**
1.0

**What steps have you taken**
* [x] I have searched the Issues page
* [x] I have read the documentation
* [x] For LED issues I have checked the following things
        - the pro micro is programmed (and currently telling the LEDs to do something)
        - the pro micro is powered (and showing LEDs)
        - the LEDs are powered (check 5v across pins 1 and 3 of J1)
        - are any of the LEDs showing

**What is the issue?**
So this is my very first DIY split kb, i have gotten everything working except the OLED.
I'm using an Elite-C v4 with the SSD1306 OLED, I bridged the jumpers and _think_ i have soldered everything correctly, but i just can't get the OLEDs screen to show anything on neither of the keyboards. The only thing i can see after enabling logging is the following: `oled_init cmd set 1 failed`

I have tried to search for the error, to see if anyone else has encountered this, but to no avail i only find the source pages of QMK.

Any help pushing me in the right direction is greatly appreciated!
Thank you so much to anyone who can help me in advance!

**What you expected:**
OLED screens working

josefadamcik, 2021-09-06:
Hi HybridFox,

The fact you are using Elite-C shouldn't matter for Sofle. I haven't tested it but it's a drop in replacement and the only problems I have heard about is the halve detection problem in one of the older revisions and the fact that RAW pin is connected differently on Elite-C. But the RAW pin is dis-connected on Sofle so that couldn't cause any issues.

Pro tip: You can also google for problems for Lilly58, Corne and other keyboards split keyboards where the connection to OLED is almost identical so the debugging and solutions will be the same.

Basic Tips:

I would check with continuity meter / multi-meter if there's really a good connection between GND, VCC and the SDA/SCL i2c pins on the EliteC and and the OLED when everything in place (but not powered).

They are usually labeled on the OLED PCB, you'll have to look up the corresponding pins on micro-controllers in the schematic. I have attached pdf so you don't have to go to the KiCad. but you still have to check which pins are they actually on micro-controller.

[SofleKeyboard.pdf](https://github.com/josefadamcik/SofleKeyboard/files/7114338/SofleKeyboard.pdf)

Also make sure you you soldered other things correctly. E.g. one way how to break OLED is to modify the default setup for connection of the halves from serial to I2C. This is not even mentioned in the build guide (it's not recommended), so I assume you didn't try to do that for your first split build.

Make sure you have the official default firmware with the default keymap from QMK and not using VIA and similar tools. They usually don't support OLEDs and Encoders as far as I know.

There are also the basic things: make sure the OLEDs actually work, double check all the connections, try it only with one half plugged in.

HybridFox, 2021-09-06:
Hey Josef, thank you for giving me some tips to look for the issue!

I have checked the GND & VNC continuity and they seem fine. Same with the SDA/SCL & pins on the EliteC
Though it seems i also have continuity between GNC & VCC itself, not sure if that's supposed to be like that? I'm finding conflicting info about that online.

I have indeed always flashed the keyboard with the default keymap using `qmk fash`, so that should be.

Do you know a way how i can test if the OLED is actually working?

Thanks again!

DaneEvans, 2021-09-06:
Try measuring the other way between GND and VCC, or do so without the micro
attached.  There definitely shouldn't be a short, but you are probably
seeing a diode between them.

Alternatively power up the board and see if there is 5v between them.

The easiest way to stop the oleds from working would be to do the jumpers
on the wrong side, or do both sets.  Have you checked that?

If you have spare oleds you could try another one.
Make sure there are no address or enable jumpers on the OLED, they aren't
in the basic design, but that's not to say that some manufacturer hasn't
decided it's a good idea.

As to the error. An init failed suggests to me a NACK error, which points
to a connection bug.

If you post some pictures we can maybe see something

On Tue, 7 Sep 2021, 3:30 am Pieterjan Van Saet, ***@***.***>
wrote:

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

jeremiah-miller, 2023-01-26:
I'm having this problem as well, using serial for communication between the halves. I don't even get the oled_init warning. I have the v1.1 pcb, what do you mean by having the jumpers on the wrong side? are the pcbs not reversible? I connected them after soldering in the elite-c.

Also, what do you mean by "Make sure there are no address or enable jumpers on the OLED"?
![Uploading IMG_20230125_195526_154.jpg…]()

DaneEvans, 2023-01-26:
See, with an image we can help.

Read the build guide, and pay attention to which side of the board the OLED
jumpers are supposed to be on. And where the micro is meant to be.

I think you'll find that the designs are for the micro, and jumpers on the
top side of the board.

And your micro is on the top, but you soldered the jumpers on the bottom.
Hence the polarity and data lines are all reversed, and you probably fried
the OLED

On Thu, 26 Jan 2023, 1:56 pm Jeremiah Miller, ***@***.***>
wrote:

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

jeremiah-miller, 2023-01-26:
That's what i was worried about, i missed the part about soldering the jumpers until after the micro was soldered in.

Given that, if I got a new oled and desoldered/removed the old one, do you think it would work if i put the new one on spun 180 degrees? Or could i use wires to connect it in a way that the oled would work?

DaneEvans, 2023-01-28:
If you use the jumper pads to swap the order of them - ie 1>4, 2>3, 3>2,
4>1, or reverse the OLED, both should work.  The first would be cleaner.

On Fri, 27 Jan 2023, 2:56 am Jeremiah Miller, ***@***.***>
wrote:

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

jeremiah-miller, 2023-02-01:
I flipped them and the OLED still works! The pimoroni trackball I had connected works too, neither seem to have been fried! Thanks for the help!

Closed 2025-06-18.

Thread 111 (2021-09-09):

RGB color on LHS does not match RHS

petertriho, 2021-09-09:
**Kind of issue?**
Assembly

**Which Board?**
RGB

**Which Board Revision?**
RGB =   2.1

**What steps have you taken**
* [X] I have searched the Issues page
* [X] I have read the documentation
* [X] For LED issues I have checked the following things
        - the pro micro is programmed (and currently telling the LEDs to do something)
        - the pro micro is powered (and showing LEDs)
        - the LEDs are powered (check 5v across pins 1 and 3 of J1)
        - are any of the LEDs showing

**What is the issue?**
LEDs were working fine for a week now but suddenly the LHS LEDs have incorrect brightness and color compared to RHS

Video illustrating the issue with the LHS https://imgur.com/a/PPqbXLh

I have tried:
- flashing the original rgb default qmk firmware
- swapping out elite c for pro micro
- swapping out cables (tested different usc c, micro usb and trrs cables)
- swapping controllers on either side
- changing the master from left to right

All have the same rgb issues on the LHS

**What you expected:**

Color of RGBS should be the same on both sides

Thanks!

petertriho, 2021-09-09:
Nevermind, it's back to normal now after replugging the trrs cable

DaneEvans, 2021-09-09:
One of the early leds in the chain has a dry solder joint and is firing randomly. This is then passed through all of the others as a disco effect.

petertriho, 2021-09-09:
I tried looking at the solder joints, would that be the LED on the top right of this photo? https://imgur.com/a/GKuhi8T It seems to work but with a different color at different brightness levels

Closed 2021-09-09.

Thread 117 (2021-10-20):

Help: LEDs not working and Elite C status LED cuts out

bmosley, 2021-10-20:
**Kind of issue?**
_Assembly / HELP!_

**Which Board?**
_RGB_

**Which Board Revision?**
2.1

**What steps have you taken**
* [x] I have searched the Issues page
* [x] I have read the documentation
* [x] For LED issues I have checked the following things
        - the pro micro is programmed (and currently telling the LEDs to do something)
        - the pro micro is powered (and showing LEDs)
        - the LEDs are powered (check 5v across pins 1 and 3 of J1)
        - are any of the LEDs showing

**What is the issue?**
sofle_rev1_rgb_default from QMK's repo up to date and compiled okay.

I cant get any LEDs working at all (event the status indicator). I added sockets and have my elite C on right now but as soon as I plug in the USB the device is not showing up in either QMK after clicking reset on the pro or even status LED on the pro itself. This is the only build I havent gotten to work so puzzled as Ive tested the LEDs with a multimeter and get a solid output. No idea what to do next here. Any advice?

**What you expected:**

one of the images shows the Status LED on the back... ive removed that and put on the surface of the board instead. No difference.

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

bmosley, 2021-10-21:
strange the boxes show checked for me (thought I had to do it after the issue was create) sorry!

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

so yes, I think I was a bit unsure of the LED orientation from the docs. I assumed that the notch (DIN) for my LEDs was oriented in a way that it sits on the highlighted pad. I figured that maybe I had them reversed so flipped the indicator LED 180deg and removed the LED#2 entirely so there wouldn't be a short somewhere else down the line. the Elite C only shorts plugged in so something is clearly my fault there I just don't know where at this point

STotev, 2022-02-10:
A little late answer to this but on the last picture, the indicator has the wrong orientation. The small dot should point to the side of the silkscreen. You need to flip it.

Also, if you are only checking that they are properly grounded and have 5V, it won't help much. You must ensure that you have something on the Dout pin because this will break the chain depending on what you have enabled.

Closed 2024-03-12.

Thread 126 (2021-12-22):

Help: some random keys not working

antoineroux, 2021-12-22:
**Kind of issue?**
Assembly
**Which Board?**
Choc

**Which Board Revision?**
Choc = 2.1

**What steps have you taken**
* [X ] I have searched the Issues page
* [X ] I have read the documentation
* [N/A ] For LED issues I have checked the following things
        - the pro micro is programmed (and currently telling the LEDs to do something)
        - the pro micro is powered (and showing LEDs)
        - the LEDs are powered (check 5v across pins 1 and 3 of J1)
        - are any of the LEDs showing

**What is the issue?**
Hello,
First of all, thanks everyone contributing to the project, this is the first time I build a keyboard, and it is fun.

I am building a choc and did the first half. I soldered the diodes, the sockets and a few LEDs (not all of them yet, I wanted to test first). I tested all the keys and a few random ones are not working:
* Row 0: `1` - `2` - `3` - `5`.
* Row 1: `T`.
* Row 2: `Tab`.
* Row 3: `Alt`.

`3` and `5` and `T` seem to be caused by faulty diodes, because only one side of the diode works.

I focused on the `1` key on row 0 next. I suspect if I can fix this one, the solution might apply to other keys as well. But this is where I don't understand what is happening. I can reproduce the same issue on `2`

When I connect both sides of the sockets with a piece of wire for any working key, it outputs the corresponding letter/symbol, as expected. When I do the same on the `1` key, it does nothing.

When I connect the right side of the socket of the `1` key to the left side of any working socket on the same row (or any diode on a working socket), it outputs the 1 correctly. I can reproduce this test on both sides of the board. If I connect the right side to its own diode, it works fine as well.

I removed the socket, at some point I was wondering whether it could be damaged, but that changed nothing. I can output the character by connecting the right side of `1` socket to any working diode on the same row.

So to me it looks like the issue is on the PCB:
* When input to `1` is sent anywhere else, it works.
* When input to a working key is sent to `1` output, it doesn't work.
* When input to a working key is sent to `1` diode, it works fine.

So the input is there, the microcontroller is correctly connected, this diode is working and the output does not seem to get to the diode.

Am I correct? Is there anything else I should check? What do I do if it is the board that's damaged? Remove the components and start a new one?

For completeness, other issues I have on the board:
* I soldered 6 LEDs, one of them is not working. I don't worry about that for now, I just need to replace one or two of them.
* The OLED is not working. This could be my fault: at first I bridged the wrong side of the board. I wasn't sure what to do, so I removed the solder on that side and bridged the other side, except I had to do it under the microcontroller that was already soldered in, so I might have failed.

**What you expected:**

I guess I was expecting that to be my fault, with a faulty diode for instance.

Thanks in advance.

DaneEvans, 2021-12-22:
There are only 4 things in those switch circuits

Micro output (row I think, but check it)
Switch
Diode
Micro input(col?)

For a failure of a whole row or column, check the micro sockets.
There are also ways for the diodes to screw these up, but I'd need to look
at a schematic

For a failure of a single switch, then look to the switch (which you have)
or the diode.

First things first I'd check that all your diodes are around the right way
(hopefully on that board they are all the same orientation)

After that I'd check the schematics and see if a circuit row or column
contains most or all of those switches. The circuit may not reflect what
the key matrix looks like it should be.

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

antoineroux, 2021-12-22:
Thanks a lot for the answer.

So in my case, there isn't a full row or column that isn't working. I have two failing keys on the same row, but that's it (and the other two are caused by bad diodes). So I believe it rules out the micro-controller. Also, I can get it to output the non-working keys by connecting the input to any working output or directly to the diode. So I think it rules out the diode.

To clarify a bit, here are pictures of what doesn't work (in red) and what does work (in green). Imagine the lines being a piece of wire.

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

I used solder paste, I did my best to remove it when I desoldered. Coult it be it?

brianlow, 2021-12-22:
Some ideas...

> 3 and 5 and T seem to be caused by faulty diodes, because only one side of the diode works.

Replace the bad diodes first. I think it is good to solve the known problems even if not obvious how they may affect the other keys.

Double-check diode orientation on all keys

Test the diodes in-place if your multi-meter supports it. Should see 0.5V with red probe on the bottom diode lead and black probe on top lead. Then should see nothing (0L) when probes are reversed.

Check continuity for the lines below. For example, the red lines below indicate the right side of the switch sockets should be connected together.

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

antoineroux, 2022-01-07:
Thanks a lot, that really helped. I started by applying your first advice and replaced the diodes I knew weren't working. Then I realised while testing the diodes for the key `1` that's causing me trouble, I was touching the diode's leg: that proves that the diode is working, not that it is correctly soldered.

I replaced the diode and now it is working. I still have a few keys to fix, but I feel like I know enough to do the debugging. I will close this issue. I will open a new one if I find a new problem.

Thanks a lot for your help.

antoineroux, 2022-01-12:
Just a follow-up: I fully built one half, so I expect the second half won't be an issue.

brianlow, 2022-01-12:
Great to hear. Thank for the update. Let us know how the full build goes

antoineroux, 2022-01-24:
Here is the keyboard, completed.

It was the first time I was building my own keyboard, so I remained very close to the original design. Sourcing all the parts and soldering everything was already a lot of learning.

I am now tweaking the firmware.

Thanks again for publishing this keyboard and foe the help.

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

![Uploading t2{19a9a5c} (11da95a0-a7c0-404f-abfd-cce1b571abe9 id=0x7f0a039e tag=BaseCommentFragment) …]()

antoineroux, 2022-01-24:
The other pictures did not make it through. Here they are.

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

Closed 2022-01-07.

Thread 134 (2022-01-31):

Help: UART connection with Sofle Choc and KB2040

alecharp, 2022-01-31:
**Kind of issue?**
_Bug / Assembly / Software / HELP!_

It's kind of all 4..

**Which Board?**
_Choc_

Not ordered from keyhive, directly ordered the PCB at JLCPCB with the gerber files on the repository.

**Which Board Revision?**
Choc = 2.1

**What steps have you taken**
* [x] I have searched the Issues page
* [x] I have read the documentation
* [x] For LED issues I have checked the following things
        - the pro micro is programmed (and currently telling the LEDs to do something)
        - the pro micro is powered (and showing LEDs)
        - the LEDs are powered (check 5v across pins 1 and 3 of J1)
        - are any of the LEDs showing

_Not a led issue_

**What is the issue?**

I'm using two KB2040 from Adafruit and trying to have KMK (with circuitpython). I don't think this is related to the firmware but to the board.
The pins to to UART Rx cannot be used to do Tx (I'm a noob in electronics, sorry), or it seems from https://github.com/adafruit/circuitpython/issues/4502.

This would means that the fact the LED are connected to the Tx (D0) and the Data to the Rx (D1) is problematic. For the right half, the lines should / needs to be inverted. What do you think?

Also, the current pcb is made to work in one direction. Did I understood that correctly? Does this means that the two half cannot sync up? Meaning a layer toogle change on the left side couldn't trigger a layer change on the right?

If the LED line was connected to another pin, we could have Rx/Tx pins linked to the TRRS connector and have the firmware handle the Tx/Rx cross connection. Did I understand that correctly as well?

KB2040 pinout: https://cdn-learn.adafruit.com/assets/assets/000/106/984/original/adafruit_products_Adafruit_KB2040_Pinout.png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

**What you expected:**

Nothing really. I mostly have questions and would like to know if I can "fix" the PCB I have, or if I have to spend time on changing the PCB design and order new ones.

alecharp, 2022-01-31:
Side note, my point on the `Tx/Rx` is also based on https://github.com/KMKfw/kmk_firmware/issues/198#issue-872977177.

brianlow, 2022-01-31:
This is cool. I think the RP2040 might become a really popular keyboard controller. Some first thoughts:

> For the right half, the lines should / needs to be inverted

I don't think so if the controllers are installed in the holes with the outline around them. If so the controllers will be wired identically

brianlow, 2022-01-31:
> Also, the current pcb is made to work in one direction. Did I understood that correctly? Does this means that the two half cannot sync up?

With ProMicros the two halves work independently and then cooperate using the TRRS cable. So changing the layer with a keypress on the left will also change the layer on the right half

brianlow, 2022-01-31:
I've read the RP2040 has a feature called programmable I/O so I think most pins can be configured to control the LEDs

alecharp, 2022-01-31:
> I don't think so if the controllers are installed in the holes with the outline around them. If so the controllers will be wired identically

yes, the D1 is connected to the other half D1.
But in CircuitPython, I cannot create a UART connection with `busio.UART(tx=board.RX, rx=None)`. The code won't load.

In the end, it's probably a problem of CircuitPython and not Sofle design. I'll more testing.

alecharp, 2022-01-31:
Based on https://github.com/adafruit/circuitpython/issues/5953 response, we can close this.

Even if it would be best to have the Tx/Rx pins to cross, it possible to get around that. I _just_ need to work on KMK split module to use pio and not the board UART.

brianlow, 2022-01-31:
Good luck, let us know if you solve it!

alecharp, 2022-02-01:
as I'm not good in electronic, and I mostly code in Java, not Python even less CircuitPython, that will be a challenge.

netgmx, 2022-02-06:
I'm working on the redox keyboard drived by two pi pico, here is what I found:

- pico doesn't like switching rx and tx pins, I needed to cross wires between halves on uart0 (pins 0 and 1 ). There is not used flag uart_flip - maby this was it intention but not implemented?

- there is somewhere in libs bug (or in my code but it's minimal), killing script if there is two way communication between boards so i had to change split.py module between halves

left side (usb)
self._uart = busio.UART(rx=self.data_pin)

right side
self._uart = busio.UART(tx=self.data_pin2)

not nicest solution and now that I know what is going on I can design some logic around it, hope it helps someone

Tonasz, 2022-02-07:
I accidentally found this issue as it was linked to KMK repository. I got some news which could interest you @alecharp:
- The https://github.com/KMKfw/kmk_firmware/pull/301 PR was merged and fixed some issues with wire communication (for example it fixed `uart_flip` you @netgmx mentioned)
- I have similar issue as you (but on Kyria board, also one pin TRRS connection) and found similar tips about using PIO. I bashed together the examples from documentation and my board worked. Made PR for you to look at: https://github.com/KMKfw/kmk_firmware/pull/320 Please mind that this will be only one way communication on one wire
- "Also, the current pcb is made to work in one direction." - I don't know choc, but QMK has one-wire, custom bitbanging protocol implemented, so two-way communication works on one pin. KMK doesn't have it implemented yet (nor circuit python I guess).

Closed 2022-01-31.

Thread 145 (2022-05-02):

Help: Lost on RGB matrix layout coordinates

ryuugaplays, 2022-05-02:
**Kind of issue?**
 Software / HELP!_

**Which Board?**
RGB

**Which Board Revision?**
RGB =   2.1

**What steps have you taken**
* [ x ] I have searched the Issues page
* [ x ] I have read the documentation
* [ x ] For LED issues I have checked the following things
        - the pro micro is programmed (and currently telling the LEDs to do something)
        - the pro micro is powered (and showing LEDs)
        - the LEDs are powered (check 5v across pins 1 and 3 of J1)
        - are any of the LEDs showing

**What is the issue?**
 Hello, after few weeks of assembly and troubleshooting I have finally put together my very own sofle!!
currently trying to dig into the QMK code and edit stuff to my liking but have hit a wall trying to decipher the RGB matrix  coordinates. I have read through the docs and github but still feel lost.
I have only the underglow and perkey lights. indicator lights is disabled.

So firstly I understand that {1, 6, hsv} means from LED 1, lightup 6 LEDs. However, according to [this](https://imgur.com/RtbLSeO) diagram, underglow for LED1 is actually 02
and then there is 35+1 what does that mean?

on QMK docs it says you can define the layout which is what is happening here on the right #define layout(
can  i use this in the code so instead of {1, 6, hsv} I do {L01, 6, hsv} for example

I  guess the question here is, there are so many sets of numbers, What does the numbers in the code correspond to in terms of the physical location and how do I figure out which ones are the underglow and where does the perkey lights start and end?
 also btw is it normal that i have to flash both sides whenever I make changes to the RGBs? I tried flashing one side only but the other side remains unchanged

**What you expected:**
 LED1 is number 1

DaneEvans, 2022-05-02:
That depends.
What is your setup?

If you use the top indicator, then it is the first. If you bypass it, then
the first drop LED is the first.

The macros make it easier, but you can just count and do it manually

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

ryuugaplays, 2022-05-04:
So after some rigorous trial and error, flashing and reflashing, I had finally found the proper configuration for my LEDs.
The issue was two folds:

First, as mentioned above, I had disabled indicator lights leaving only perkey and underglow lights. As such, the numbers on the default code does not correlate to the actual light positions. Since indicator lights are bypassed in my case, light number 00 starts from the first underglow light.

Secondly, I wasn't sure how the numbers carried over to the right(slave side} 35+?

So after some testing, I figured out that it was following  the LED chain during the build process. So rewrote all the LED positions into this neat little chart:
`// 10 11 20 21 30 31       66 65 56 55 46 45
  //    00    01    02                 37    36    35
  // 09 12 19 22 29 32       67 64 57 54 47 44
  //        
  // 08 13 18 23 28 33       68 63 58 53 48 43
  //
  // 07 14 17 24 27 34       69 62 59 52 49 42
  //
  //     06 15 16 25 26          61 60 51 50 41
  //    05    04    03                 38    39    40`

These are the absolute positions of the LEDs (indicator disabled, only perkey and underglow enabled}. No guesswork, no math involved here. Just plug in the numbers and you're good to go. If you ONLY enabled perkey and bypassed the other lights, 06 on the chart above will be number 00 for you, and from there just rewrite the numbers, making sure you skip  the right side underglows.

 I tried plugging in the macros like so {L22, 6, hsv} but it wont compile so the above was the only way I could make it work. Perhaps there is an easier way to do this but this was already a handful for a beginner like me at this stage.

I hope this will help someone who might stumble upon this hurdle in the near future.

sanko, 2023-01-08:
Before I take a swing at it, did you ever get the matrix set up properly, @ryuugaplays? Having the underglow LEDs out of synch with the key LEDs during something like an RGB gradient is really bugging me.

ryuugaplays, 2023-01-09:
Not sure what you mean by "set up properly". As illustrated in my post above, the lights should be properly configured if you follow the diagram.

I did notice that in my testings, when using gradient or RGB wave lightings, the lights would flow from the opposite direction on the offhand (ie. RH-Left>Right  LH-Right>Left)
Which is not the desired outcome of RGB gradient, but I suspect that has nothing to do with this topic. This topic is about telling QMK the correct LED coordinates according to it's physical circuit. RGB circuit is serial hence we have to follow the numberings.

If you want to work on the gradient lighting, it's a separate topic than this one. One that has more to do about programming in QMK than circuitry. And no, I don't use gradients myself at the moment so I don't have that part of QMK set up. But I hope that helped.

Closed 2023-01-09.

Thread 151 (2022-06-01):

Gerber Version of Tenting Case for Sofle V2 and Sofle RGB

ghost, 2022-06-01:
Laser cutting is sometimes not easy to find. It is also generally very very expensive, at least in my area.

Could you create Gerber files for the top and bottom plates, so that we can print tenting case plates in FR-4 when ordering the PCB?

I wonder if 1.6mm tenting case plates would be too thin or not. I think it would be fine, especially as long as we put spacers between the two halves to fill the gap. It would be very convenient to be able to buy the tenting cases with the PCB.

From what I've read, I believe tenting is a very strong ergonomic addition to the keyboard. So much so, that I wouldn't buy a Sofle keyboard, or other ergonomic keyboard, without it. Making the tenting case more accessible by having Gerber files would be very important for me and probably others.

I want to build a Sofle but this is what is holding me back. I would really appreciate Gerber Tenting Case files, and then I would be able to build a Sofle. There is a dxf already. I believe it can be as simple as converting it in KiCad or AutoDesk.

josefadamcik, 2022-06-01:
Hi @Smitty-Werbenjagermenjensen , thanks for the suggestion!

There is one missing piece of information, you haven't mentioned which version of Sofle you are talking about. Is it for the RGB version?

From my side, I do not plan to do any adjustments to the tenting case and I would assume other maintainers might not be eager to do that as well. But contributions are always welcome!

The tenting case (if I remember correctly) was submitted by a community member. I believe they might have been selling the case in their shop (sadly I do not remember any links or anything). So maybe you could try to google around, check Reddit etc. it might be possible to buy it somewhere.

> I wonder if 1.6mm tenting case plates would be too thin or not. I think it would be fine, especially as long as we put spacers between the two halves to fill the gap. It would be very convenient to be able to buy the tenting cases with the PCB.

People have most likely done that, but I personally have no experience with tenting. Maybe the best shot would be to test it.

DaneEvans, 2024-03-12:
The RGB has it already, and has had since release

Closed 2024-03-12.

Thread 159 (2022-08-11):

Help: I only get key presses from the plugged in side of the keyboard

dayorbyte, 2022-08-11:
**Kind of issue?**
_HELP!_

**Which Board?**
_RGB_

**Which Board Revision?**
RGB = 2.1

**What steps have you taken**
* [X] I have searched the Issues page
* [X] I have read the documentation
* [X] I reset the eeprom
* [X] I installed the default firmware instead of my custom firmware
* [X] I googled a lot
* [X] I tried a different TRRS cable

**What is the issue?**

My keyboard was working perfectly for the last few months since I got it (purchased pre-soldered), but today I plugged it in and the keys on the plugged in side work but not the other side. If I swap the USB-C cable then just that side works. The RGBs are working on both sides, so power is flowing, but seemingly no data.

**What you expected:**

The side of the keyboard attached by the TRRS cable can transmit keys

dayorbyte, 2022-08-11:
The Etsy seller I got the keyboard from suggested it could be related to power draw, and when I turned down the brightness on each half and replugged it it worked. The default firmware didn't fix it since it also starts at full brightness. Interestingly, once the halves are working I can turn up the brightness and it keeps working.

It's easy enough to modify my firmware to work around this, but since it had worked for several months I was wondering if this is an issue that's come up with extended use before and if it might be something degrading over time.

DaneEvans, 2022-08-12:
More likely the USB port has more load, and supplied a lower voltage
today.

Or the USB cable has been damaged increasing the voltage drop to the
keyboard.

Or the TRRS cable has been damaged slightly, increasing the voltage drop
across it.

Degradation of the Arduino boards themselves is unlikely in room
temperature, and would be unlikely to be symmetrical.

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

dayorbyte, 2022-08-12:
That makes sense. I'm glad to hear that it's unlikely to be the keyboard hardware itself. Closing the bug since I don't think there's anything else to be done. Thanks again!

Closed 2022-08-12.

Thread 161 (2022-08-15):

Help: Are these contacts from the V1.1/2.1 equivalent to these contacts on the V2?

Moghul, 2022-08-15:
**Kind of issue?**
_HELP!_

**Which Board?**
Basic

**Which Board Revision?**
2.0

**What steps have you taken**
* [x] I have searched the Issues page
* [ ] I have read the documentation (I don't know how to read the pcbs and even if I found the exact information I'd check with you)

**What is the issue?**
I want to add a Pimoroni Trackball Breakout to my Sofle V2. I've found instructions for how to do it on a sofle 1.1 and 2.1 [here](https://github.com/foureight84/sofle-keyboard-pimoroni).

According to those docs, I need to solder the Pimoroni to these contacts:
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

However, on the Sofle V2 they've been moved. Are these contacts from the Sofle V2 the same thing? Can I solder the Pimoroni to these? Please excuse the scuffed screenshots, I ripped them out of a reddit post.
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

**What you expected:**
N/A, this is some custom stuff and the keyboard is awesome anyway

DaneEvans, 2022-08-15:
Yeah, those will work to get access to the I2C lines.

I'd go off the through holes where the Arduino mounts, you have less chance
of overheating the copper and having the pads peel up.

If you decide not to run the OLED, you could go off the 2.54 header there,
but you need to get it around the right way.
You could also do it and keep the OLED, but it may be more ugly

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

Moghul, 2022-08-16:
Thank you so much for the reply! I'll be taking your advice and soldering to the chip's pins directly.
I do want the OLED and I've already soldered it on, so I think I won't be messing with that.

etrnal70, 2023-04-23:
@Moghul hello, sorry for reviving this rather old issue. I'm also trying to add a pimoroni trackball to my v2 pcb. I want to ask which pin you use to get it working, the middle one or the side one ? A pics of your wiring would be greatly appreciated. Thanks ! 😄

Closed 2022-08-16.

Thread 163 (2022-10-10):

One column and one row suddenly not working

F1orian, 2022-10-10:
Ijust fineshed building the RGB Version and tested all keys successfully before soldering the LEDs. Now I've soldered all the LEDs and everything seemed to work, but upon testing all the keys again, I was greeted with one dead row and one dead column. LEDs all still work.

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

What could be the cause of this, and how do I troubleshoot this?
Thanks a lot in advance.

DaneEvans, 2022-10-11:
Check that the switches are all plugged in properly.

Then look at the switch and diodes around the common key for both rows.
It's probably a bad diode. I think a shorting diode presents that way, I'd
need to check the schematic to be sure.

If you have them spare, it's probably easier to just replace both of them.

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

F1orian, 2022-10-13:
Thanks for taking a look!

I've checked the schematic but I was unable to identify the diode(s) that I should replace. Also I'm a bit skeptical because they all worked before. Are they sensitive to heat, like the LEDs?

Looking at the schematic, I don't think there is a single diode that affects all switches of col2:
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

There are however a few diodes in row0:
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

Sadly I have no experience at all when it comes to reading schematics, so if you could take another look at this, before I start de-soldering and potentially breaking something for real, I would really appreciate that!

DaneEvans, 2022-10-13:
One other thing I'll note.  The highlighted row and column on your post are
adjacent pins at the micro end.  If you've been heavy handed with the
solder there could be a short there too.

If the columns get driven low when they aren't in use, then a simple short
between those, or of the common diode would probably cause all your
issues.  I can't recall if qmk does that, but I have a feeling it does.

Also looks like that screen shot is my board.  Why the hell did I length
match those traces?

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

F1orian, 2022-10-13:
Alright, thanks a lot for your help so far!
I'll get a multi-meter on the weekend and then I'll check the things you suggested.

I just did some cleaning-up on the pins at the micro on the PCB-side (quite sure there's nothing shorted on this side), and the pins for col2 and row0 on the micro itself. After that, col2 was working for around a minute, but weirdly it stopped working again. Row0 remained unchanged.

DaneEvans, 2022-10-13:
In that case I'd say 2 problems.
One is a loose pin or dry solder joint at the microcontroller on that
column.  It worked for a while after you made it connect as you poked at
it.

If you're using sockets, that leg may be too short.

But yeah, a metre is pretty much the minimum trouble shooting gear you
need.

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

F1orian, 2022-10-17:
So I got the metre and did some testing:

**Row0**
I have continuity to gnd on all switches (including row0) **except for col2**
Does that mean that row0 is just not connected to the micro correctly but everything else in the chain is soldered correctly and working?

**Col2**
I have continuity on col2 to the pin that connects to the micro for all switches of col2.

I am not quite sure how to proceed with these findings...

What options does that leave me with, also considering that col2 was briefly working for around a minute?

Closed 2024-03-12.

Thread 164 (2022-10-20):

Building my first Keybaord, everything seems to be working except backlight

tomdcpennington, 2022-10-20:
**Kind of issue?**
Both halves of the board, when connected together or not show oleds, indicators and drop lighting. But none of the per key leds light up.

**Which Board?**
The RGB not Keehive version. Running RGB_default keymap on both controllers

**Which Board Revision?**
RGB 2.1

**What steps have you taken**
* [Y] I have searched the Issues page
* [Y] I have read the documentation
* [Y] For LED issues I have checked the following things
        - the pro micro is programmed (and currently telling the LEDs to do something)
        - the pro micro is powered (and showing LEDs)
        - the LEDs are powered (check 5v across pins 1 and 3 of J1)
        - are any of the LEDs showing
* Check solder on first LED in the chain by the jumper. Both sides seem fine.

**What is the issue?**
Per key LEDs not lighting. Nothing else seems to be having an issue. I don't have switches in currently and I have bridged 'Backlight enable' on ENA on the back of both sides of the board.

**What you expected:**
Expect per leds to light up. I expected at least a few to light up before the chain was perhaps broken, but the fact that none light up on either side of the board makes me think its not down to soldering but something else.

DaneEvans, 2022-10-20:
Try the key command for RGB enable.
And brightness up.

Have you tried plugging the second half in directly? Any change?

If your enable bridge is setup properly, then it seems more likely to be
firmware and settings than soldering on the first LED of both boards.l at
the same time

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

Closed 2024-03-12.

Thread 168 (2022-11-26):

Help: short somewhere, need schematic to trace

rob31183, 2022-11-26:
HELP!_

RGB

RGB =  2.1

**What steps have you taken**
* [Yes ] I have searched the Issues page
* [Yes ] I have read the documentation
* [Yes ] For LED issues I have checked the following things
        - the pro micro is programmed (and currently telling the LEDs to do something)
        - the pro micro is powered (and showing LEDs)
        - the LEDs are powered (check 5v across pins 1 and 3 of J1)
        - are any of the LEDs showing

**What is the issue?**
Backlight led on right hand will not work (left works fine).  1st led works, but 2 of the 4 led contacts are grounded so I wasn't getting signal to led 2.  I assume I messed it up somewhere upstream.

I tried to install kicad to get the schematics so could try and trace the issue, but I can't get the .pro and .sch files to work.

**What you expected:**

Pdf of the schematic uploaded to the git would be nice
Any advice on how I could have grounded one of the data pads

DaneEvans, 2022-11-28:
What do you mean you can't get them to work? Are the symbols not appearing?
Do you need to link the Library that is in the repo?

It's kicad, the thing is awful. You'd think that linking would be in the
project, but apparently not.

A pdf would definitely be useful, I'm surprised that there isn't one in
there.  Or in the documentation section.   I don't currently have an
environment, so I can't make one at the moment.

The most likely would be at the last LED to work, or the next one.  Sounds
like you've grounded the data trace.  Or possibly cooked an LED.

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

rob31183, 2022-12-04:
I was able to resolve the grounding issue, and the board no longer shorts
out.  It was some sort of issue with the jumpers.  However, the per key
LEDs still won't turn on.

I replaced the last led on the underglow Incase it wasn't sending data, and
the first (only) led on the per key, and it still won't turn on.

I also managed to rip up one of the traces, so I had to jump + from another
led to that one.

I can see I have 4.42 volts going across the led.  I traced data out of the
last underglow led to data in of the first per key led, and I can trace
data out to the second per key of the led.

I even swapped my pro micros between sides, and it did not resolve the
issue.

I don't know where to go from here.  What else could it be that the first
per key led won't turn on, but only on the right side?

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

DaneEvans, 2022-12-04:
Are you sure that the firmware is set to drive enough LEDs? Are you sure
that it's asking for the latter ones to be turned on.

If it's not power, then it's data, or the LED itself.
Measure data at the back of the LED if you can, try jumping off that to a
strip if you have one.

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

rob31183, 2022-12-05:
I tried to improvise a strip, and it might not have worked.  I got a tiny
green light when nothing was tied into din.  When I touched din to
anything, the light turned out.

If I put a multi on ground, and any other din or dout i get .05mv.  When I
touch it to the dout of the last underflow led i get .05mv.  when I touch
it to din for the first per key led, I get .01mv.  it sounds like a wire
issue between the LEDs, but I already tried jumping it out.  Could it be a
jumper (j4/5/6) issue?  I'll redo them again I guess....

I pulled the firmware from this site, since that is where I bought the kit
from.  I haven't tried compiling a fresh .hex from the git hub site, I'm
not really sure how to do that yet.  I'll try that tomorrow.

https://docs.beekeeb.com/build-guide/sofle-rgb-v2.1-soflekeyboard-build-log-guide-with-photos

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

rob31183, 2023-01-20:
Hi.  I just realized that I never responded to this.

I got it all working, I have no clue how.

Thank you very much for your help, I've attached a pretty picture.

I still need to figure out programing to make those screens useful.

After using it for a while, I love it.  My only request for a future
version would be another column on the outside of each half for a few more
keys.

On Sun, Dec 4, 2022, 7:28 PM Robert D'Attile ***@***.***>
wrote:

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

Closed 2024-03-12.

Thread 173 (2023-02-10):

LED 36 doesn't light up when using `rgb_default` keymap on either side

benjamin051000, 2023-02-10:
**Kind of issue?**
Software/HELP!

**Which Board?**
RGB

**Which Board Revision?**
RGB 2.1

**What steps have you taken**
* [x] I have searched the Issues page
* [x] I have read the documentation
* [x] For LED issues I have checked the following things
        - the pro micro is programmed (and currently telling the LEDs to do something) Yes, via `qmk flash --keyboard sofle/rev1 --keymap rgb_default  --bootloader dfu`
        - the pro micro is powered (and showing LEDs) Yup
        - the LEDs are powered (check 5v across pins 1 and 3 of J1) Just checked. Yes
        - are any of the LEDs showing? All but 36

**What is the issue?**
_Please also include what other components you are having issues with - is the software QMK or the configurator, include pictures of your LEDs or soldering issues etc._

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
You can see that LED 36 is not illuminated (observe lack of reflection through the LED hole).

**What you expected:**

* [ ] LED 36 should light up just like the others

At first I thought I just botched the left half's LED 36... Every single LED works reliably except 36. I replaced 36 several times and considered replacing 35 (perhaps 35 dout was broken). But I just finished the right half, and the exact same issue arose. I'm wondering if this could potentially be a firmware bug since it's unlikely that I made _identical_ mistakes twice in a row, especially considering the chance that it would have happened on any other LED.

DaneEvans, 2023-02-10:
Have a search for closed LED bugs here.  I think it's a known issue.

I think the default is without the top facing indicator. I thought someone
had fixed it in qmk, but the recent reshuffle may have seen it reappear, or
it may never have been fixed there.

On Fri, 10 Feb 2023, 2:06 pm Benjamin Wheeler, ***@***.***>
wrote:

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

qjao, 2024-01-05:
[This page ](https://docs.beekeeb.com/build-guide/sofle-rgb-v2.1-soflekeyboard-build-log-guide-with-photos) has a firmware with it working.

7oo1er, 2024-02-24:
Hello.

I use indicator LED too and changed in config.h where it appears 35 to 36:

```
#define RGBLED_NUM 36
#define RGBLED_SPLIT { 36, 36 }
```

Closed 2024-03-12.

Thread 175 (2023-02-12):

I can't seem to get the Serial communication between the two halves working

jm355, 2023-02-12:
**Kind of issue?**
Assembly

**Which Board?**
Original

**Which Board Revision?**
1.1

**What steps have you taken**
* [x] I have searched the Issues page
* [x] I have read the documentation
* [x] For LED issues I have checked the following things
        - the pro micro is programmed (and currently telling the LEDs to do something)
        - the pro micro is powered (and showing LEDs)
        - the LEDs are powered (check 5v across pins 1 and 3 of J1)
        - are any of the LEDs showing

**What is the issue?**
_Please also include what other components you are having issues with - is the software QMK or the configurator, include pictures of your LEDs or soldering issues etc._
I have my keyboard all soldered and everything, however I'm having issues getting the two halves to communicate. Here are the relevant things in the config.h files:

```
#define USE_SERIAL
#define EE_HANDS
#define FORCED_SYNC_THROTTLE_MS 100
#define SPLIT_CONNECTION_CHECK_TIMEOUT 500
#define SPLIT_TRANSPORT_MIRROR
#define SPLIT_MODS_ENABLE
#define SERIAL_DEBUG
#define SELECT_SOFT_SERIAL_SPEED 1
#define SOFT_SERIAL_PIN D2
```

I flash with `qmk flash -kb sofle/rev1 -km foureight84 -bl dfu-split-right` for the right side and `qmk flash -kb sofle/rev1 -km foureight84 -bl dfu-split-left` for the left, and whichever side is connected to the computer works as expected.

I've also tried wiring vcc->vcc, gnd->gnd, and D2->D2 directly, instead of using the trrs cable, but not even that worked. The other half gets power, which I know since all the leds turn on, but keys on the secondary half don't work

**What you expected:**
* [ ] keys on both halve of the keyboard to work when using a trrs cable or wiring the necessary serial pins directly

DaneEvans, 2023-02-13:
Check your connectivity all the way through, micro to micro.

But that sounds like a firmware issue. Take it to the qmk GitHub.

On Sun, 12 Feb 2023, 3:09 pm Jeremiah Miller, ***@***.***>
wrote:

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

jeremiah-miller, 2023-02-13:
I did wire the two halves directly together to not really on the trrs, but sounds good, i'll ask there

DaneEvans, 2023-02-13:
That's still missing the link between the Arduino and the Sofle board.

On Tue, 14 Feb 2023, 8:41 am Jeremiah Miller, ***@***.***>
wrote:

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

jeremiah-miller, 2023-02-13:
What do you mean? Both halves work as expected independently, it's only when connecting them that the slave side doesn't work. It still gets power since the leds turn on, just no data is transferred

DaneEvans, 2023-02-13:
If that serial line is broken at any point, you'll get those symptoms.
That includes:
- micro to Arduino board
- Arduino to pins
- pins to sockets
- sockets to Sofle
- Sofle to trrs connectors
- trrs connector to cable
- trrs cable.

You've eliminated the last 3 by direct wiring.  The first is very unlikely,
but I'd throw a new Arduino on in both combinations and see if that fixes
it.

If you measure from the Arduino to Arduino on that data line then you can
eliminate the rest. Which will just leave FW

On Tue, 14 Feb 2023, 9:30 am Jeremiah Miller, ***@***.***>
wrote:

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

DaneEvans, 2024-03-12:
Closing as linked QMK issue is closed

Closed 2024-03-12.

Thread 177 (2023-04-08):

Help: Sofle RGB v3 Basic Questions - led and micro positioning

DimitarStaykov, 2023-04-08:
**Kind of issue?**
Assembly

**Which Board?**
 RGB

**Which Board Revision?**
RGB = v3

**What steps have you taken**
* [x ] I have searched the Issues page
* [x ] I have read the documentation

**What is the issue?**
Should be some pretty basic questions.

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

1. Most guides mention a triangle that shows which pad is ground for the led. On the v3 board there are no triangles, but 1 of 4 pads is surrounded by a white line. Is that the designated ground? The ones kind of surrounded by red on the picture.
2. In green - There are two sets of slots for the pro micro. The guide says for v1(both controller's chips are facing the board) use the sockets marked by the rectangle. And I am not 100% sure so I need to ask. For v1 do we use the sockets that are inside a rectangle or the ones that are on one of his sides.

Thanks.

DaneEvans, 2023-04-09:
Read the documentation

On Sun, 9 Apr 2023, 6:37 am DimitarStaykov, ***@***.***>
wrote:

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

MohamadSaada, 2023-12-13:
Yes I have to agree that V3 led positioning support is non existing, there is no documentation that discuss the white rectangles. I followed the one on Keebs as it's the one that with most resemblance to the V3 board and that didn't work. So I am stuck with a Sofle that doesn't light up which seems the norm amongst many Sofle users, as most get frustrated at this point and then give up on the rgb lighting which is a shame.

DaneEvans, 2023-12-13:
Really not sure how to make it any clearer that you need to read the documentation.
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
https://josefadamcik.github.io/SofleKeyboard/build_guide_rgb.html

MohamadSaada, 2023-12-13:
This guide doesn't indicate that the white rectangles around one of the pads on v3 is the same as the white dot in this guide. I've followed the guide but it still didn't work. I am using KB2040 and maybe that's the problem. Thank you for the quick reply and help. Sorry to bother.

DaneEvans, 2023-12-13:
The white marking is always on pin 1. And a cursory glance at the PCB files
or schematic will confirm that.

The problem is that there are at least two varieties of LED, with different
pin 1 markings.  Making any form of distinction kind of pointless. All the
info is in the guide, this is a hobbyist board, several years since any of
the maintainers last made one

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

Closed 2023-12-13.

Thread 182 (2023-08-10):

Encoders don't fit through top plate

coolavery, 2023-08-10:
**Kind of issue?**
Assembly

**Which Board?**
Original

**Which Board Revision?**
Original = 2.0

**What steps have you taken**
* [x] I have searched the Issues page
* [x] I have read the documentation

**What is the issue?**

Hi, I ran into an issue with the v2 board. Seems to be the same as #118 - the encoders don't fit through the top plate.

The reason I'm opening an issue here is that I bought the encoders from [the AliExpress listing](https://www.aliexpress.com/item/4000891003225.html) linked [on the sourcing parts page](https://josefadamcik.github.io/SofleKeyboard/sourcing_parts.html).

I'm not sure if that's intended for a different board variant, or maybe the listing has been updated to a different part since then, but the widest part of the encoder I got is about 13.7 mm wide. The cutout is about 12.6 mm wide, which seems to match the Gerber files, so I don't think it's a manufacturing issue.

Some careful filing of the PCB should fix it (as mentioned in #118), but it would be great to get some clarification on if there's an exact part that fits better for future builds.

Thanks for creating this project, it's been a super smooth build otherwise! :heart:

DaneEvans, 2024-03-12:
Ali components are not exact. That listing doesn't even include the base dimensions at the moment - only the length.

Short of only specifying reputable vendors (and getting complaints about the cost), all you can do is order a couple of different lots from different ali vendors and hope for the best.

Closing a duplicate of #118

Closed 2024-03-12.

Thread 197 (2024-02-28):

Ruined multiple PCBs & micro controllers, need help

PyHatTech, 2024-02-28:
**Kind of issue?**
_Bug / Assembly / Software / HELP!_

Sofle RGB V2.1 Dane Evans

Have previously soldered a couple of corne keyboards and outside of leds, they are working.

Have been struggling building a Sofle RGB.  Following the guide which says:

**Pro Micro and displays

**The pro micro must be installed with the components facing the pcb, and the plain back side facing out. Theoretically I think these could be installed on the under side for a lower profile.**

**Make sure that you use the outlined headers from whichever side of the board that you mount the micro on.****

Have a working right half, but when I put a working controller on the left half (soldered or not soldered), it gets hot and doesn't work. Have now basically ruined 3 left halves that won't work. Researched this github and found:

_Pro micro don't work when is connected to the PCB #83_

That issue is closed, but I'm facing the same issue. One of the comments says:

**If you want both micros in the same orientation, then you need one to be in the outboard set, and the other in the inboard.**

I'm not sure what this means. Don't see this being mentioned in the guide. The controller components are all facing the pcb, the plain back side is facing out. The outlined headers on the top of the pcb's are used for both controllers.

Can someone please explain how to position both controllers? I can share a picture, but it's the same as the picture DLopezGo90 posted where it says "right half working, left half not working". DanielToro, Liilnopitynope seem to also be dealing with the same issue. Don't know if they solved it, but I don't see the answer in the closed thread.

PyHatTech, 2024-03-01:
Have been looking at pictures of the same keyboard to determine how the controllers should be positioned and all of them have the components of the controllers facing down and the pins are in the outlined headers.

Adding two pictures of the same PCB (left/right).

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

Two pictures of one I apparently messed up.

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

As you can see, I was trying to fix this one and melted the plastic around the pins. Controller was working fine until I soldered it on the board. Then I figured that maybe I need to also add the diodes to make it work, but that didn't help. The right half I have that works doesn't have RGB, so I'm assuming that you don't need to add the leds for the keyboard to work. Then after this one, I decided to take it slow and test the pins I was soldering of the controller one at a time with a multi-meter. There is a short on two pins on the right, but I believe that is deliberate as it's ground (same location for the right half keyboard controller). Again, controller stopped working. Next one I decided not to solder at all. As soon as I put the controller on the pins, it doesn't turn on. When I remove it, it works...  Considering the fact that multiple people in the linked post experienced the same issue (also the left keyboard) and someone was able to fix it by bridging something, my guess is that it has to be something else.

PyHatTech, 2024-03-01:
Decided to use a rework station to remove the controller. The controller worked after it was removed, but there were sparks around the USB-C port connector. Now I'm leaning towards flux causing the issue. Have used flux on the controllers when soldering them and it goes to the bottom and covers the components/connector. Have cleaned the boards with iso, but obviously I can't reach the component side of the controller. Cleaned the removed controller and the sparks are gone. Looks like I just got lucky with the right half that works. Wouldn't be surprised if this is what happened to others. Will attempt to make one again and report back. Do think that it might be better to have the components face upwards. That would allow me to see the sparks, maybe attempt a repair of one a broken component etc. There is an optional display and the components look kind of cool.

PyHatTech, 2024-03-03:
Update 3: Fixed! Dropped it in an ultrasonic cleaner, then rinsed with ISO. It was flux. I need to use a different type of flux or simply use the cleaner right after soldering. Hopefully this post will help other people. When you're using flux to solder the controller, you can't see/clean the flux on the bottom as it's facing the PCB. Either use a different type of flux that doesn't really require cleaning or don't use flux..

Closed 2024-03-03.

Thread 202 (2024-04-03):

OLEDs not bridged Help: summarise your issue here.

gibranlp, 2024-04-03:
**Kind of issue?**
Assembly

**Which Board?**
Original

**Which Board Revision?**
V2.0

**What steps have you taken**
* [x] I have searched the Issues page
* [x] I have read the documentation
* [x] For LED issues I have checked the following things
        - the pro micro is programmed (and currently telling the LEDs to do something)
        - the pro micro is powered (and showing LEDs)
        - the LEDs are powered (check 5v across pins 1 and 3 of J1)
        - are any of the LEDs showing

**What is the issue?**
Basically i soldered everything except for the bridges of the OLEDs, i was wondering if i can solder the bridges on the bottom side of the PCBs or i need to remove the pro micro to solder them on the top side.

thanks a lot

DaneEvans, 2024-04-04:
You could, but not straight across.

Assuming everything is set out as it should be, then you'll need to bridge
them over with wires, reversing the order.
  If it was just the OLED to remove, I'd say do that, but if I put them
under the micro, then definitely bridge on the other side using wires.
Those micros are a pain to remove

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

gibranlp, 2024-04-08:
Had to remove the Pro micros in the end, its all good now.

Thanks a lot.
Cheers.

Closed 2024-04-08.

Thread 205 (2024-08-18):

Help:  Onboard battery soldering location?

MarcPaquette, 2024-08-18:
**Kind of issue?**
_Assembly_

**Which Board?**
_RGB_

**Which Board Revision?**
RGB =  2.1

**What steps have you taken**
* [x] I have searched the Issues page
* [x] I have read the documentation
* [x] For LED issues I have checked the following things
        - the pro micro is programmed (and currently telling the LEDs to do something)
        - the pro micro is powered (and showing LEDs)
        - the LEDs are powered (check 5v across pins 1 and 3 of J1)
        - are any of the LEDs showing

**What is the issue?**
I'm running a Nice!Nano V2 using ZMK firmware.  I'm using this as a Bluetooth keyboard with wireless connectivity between the two halves successfully for about 2 years now.

**My question is this:** Is there a place on the PCB where I can solder battery connections or must it be done on the Nice!Nano only?

My apologies if this is a silly question, my knowledge of PCB's & Schematics is limited

MarcPaquette, 2024-08-18:
Build here: https://x.com/paquem/status/1477730721791942659

Closed 2025-06-18.

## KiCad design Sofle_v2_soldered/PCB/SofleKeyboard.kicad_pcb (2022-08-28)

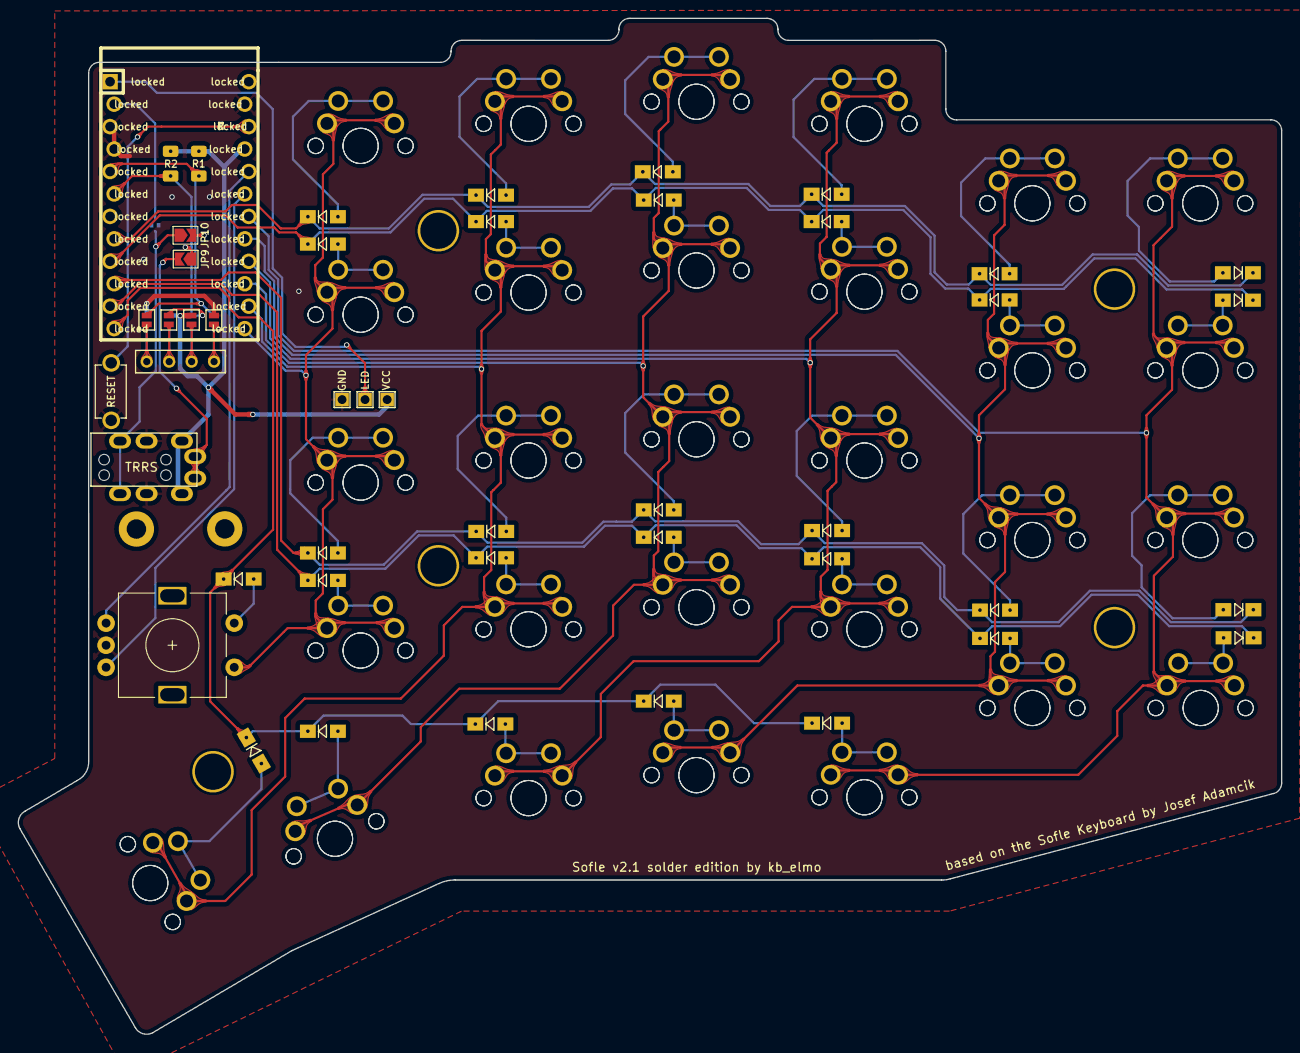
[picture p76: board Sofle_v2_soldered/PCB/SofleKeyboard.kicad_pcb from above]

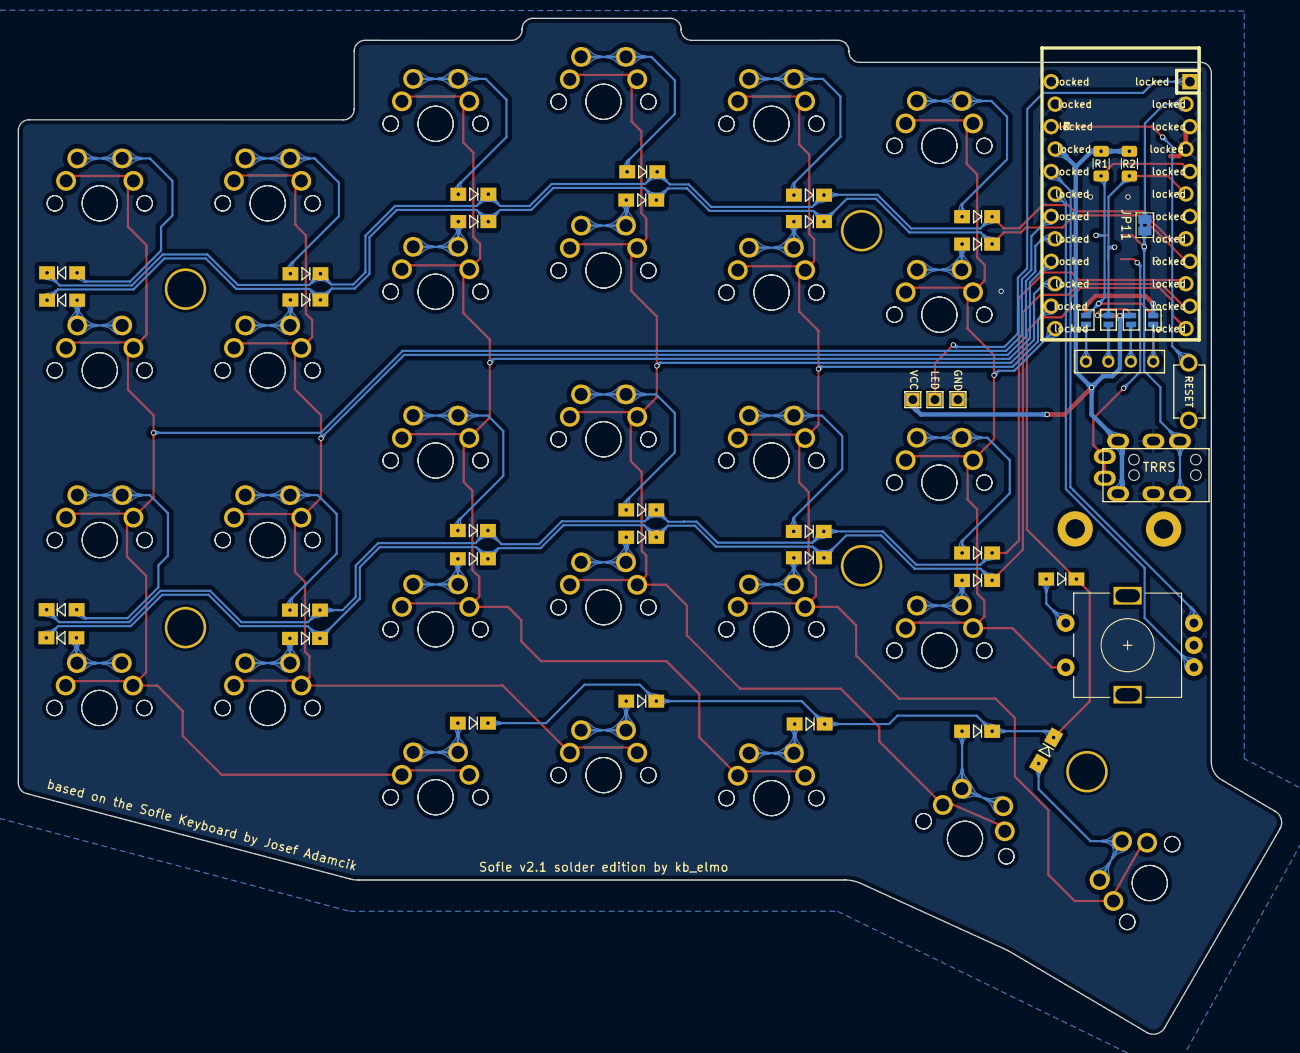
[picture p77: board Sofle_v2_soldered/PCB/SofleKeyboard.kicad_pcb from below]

Board: 2 copper layers, 142.9 x 114.9 mm, 114 parts (36 on the bottom side), 56 nets.

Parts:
D1, D2, D3, D4, D5, D6, D7, D8, D9, D10, D11, D12, D13, D14, D15, D16, D17, D18, D19, D20, D21, D22, D23, D24, D25, D26, D27, D28, D29, D30: D; Diode_SOD123
J1: LED
J2: 4PIN; MJ-4PP-9
J3: OLED; OLED_4Pin
JP1, JP2, JP3, JP4, JP5, JP6, JP7, JP8: Jumper_NO_Small; Jumper
JP9: I2CSCL; SolderJumper-2_P1.3mm_Open_TrianglePad1.0x1.5mm
JP10: IC2SDA; SolderJumper-2_P1.3mm_Open_TrianglePad1.0x1.5mm
JP11: Serial; SolderJumper-2_P1.3mm_Bridged2Bar_Pad1.0x1.5mm
R1, R2: R; R_1206_DoubleSided
RSW1: SW_RST; TACT_SWITCH_TVBP06
SW1, SW1#2, SW2, SW2#2, SW3, SW3#2, SW4, SW4#2, SW5, SW5#2, SW6, SW6#2, SW7, SW7#2, SW8, SW8#2, SW9, SW9#2, SW10, SW10#2, SW11, SW11#2, SW12, SW12#2, SW13, SW13#2, SW14, SW14#2, SW15, SW15#2, SW16, SW16#2, SW17, SW17#2, SW18, SW18#2, SW19, SW19#2, SW20, SW20#2, SW21, SW21#2, SW22, SW22#2, SW23, SW23#2, SW24, SW24#2, SW27, SW27#2, SW28, SW28#2, SW29, SW29#2, SW30, SW30#2: SW_PUSH; MXOnly-1U-NoLED
SW25: Rotary_Encoder_Switch; RotaryEncoder_Alps_EC11E-Switch_Vertical_H20mm-keebio_modif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
SW26, SW26#2: SW_PUSH; MXOnly-1.5U-NoLED
TH1, TH2: HOLE; M2_HOLE_PCB
TH3, TH4, TH5, TH6, TH7: HOLE; HOLE_M2_TH
locked: locked; ArduinoProMicro-ZigZag-DoubleSided

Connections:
/i2c_c: J2.4, JP9.2
/i2c_d: J2.3, JP10.1, JP11.2
DATA: JP11.1, locked.2 (RX(PD2))
ENCA: SW25.A, locked.20 (A3(PF4))
ENCB: SW25.B, locked.19 (A2(PF5))
GND: J1.3, J2.2, JP1.2, JP8.2, RSW1.1, SW25.C, locked.3 (GND), locked.4 (GND), locked.23 (GND)
LED: J1.2, locked.1 (TX(PD3))
unnamed: D1.2 (A), SW1.2, SW1#2.2
unnamed: D2.2 (A), SW2.2, SW2#2.2
unnamed: D3.2 (A), SW3.2, SW3#2.2
unnamed: D4.2 (A), SW4.2, SW4#2.2
unnamed: D5.2 (A), SW5.2, SW5#2.2
unnamed: D6.2 (A), SW6.2, SW6#2.2
unnamed: D7.2 (A), SW7.2, SW7#2.2
unnamed: D8.2 (A), SW8.2, SW8#2.2
unnamed: D9.2 (A), SW9.2, SW9#2.2
unnamed: D10.2 (A), SW10.2, SW10#2.2
unnamed: D11.2 (A), SW11.2, SW11#2.2
unnamed: D12.2 (A), SW12.2, SW12#2.2
unnamed: D13.2 (A), SW13.2, SW13#2.2
unnamed: D14.2 (A), SW14.2, SW14#2.2
unnamed: D15.2 (A), SW15.2, SW15#2.2
unnamed: D16.2 (A), SW16.2, SW16#2.2
unnamed: D17.2 (A), SW17.2, SW17#2.2
unnamed: D18.2 (A), SW18.2, SW18#2.2
unnamed: D19.2 (A), SW19.2, SW19#2.2
unnamed: D20.2 (A), SW20.2, SW20#2.2
unnamed: D21.2 (A), SW21.2, SW21#2.2
unnamed: D22.2 (A), SW22.2, SW22#2.2
unnamed: D23.2 (A), SW23.2, SW23#2.2
unnamed: D24.2 (A), SW24.2, SW24#2.2
unnamed: D26.2 (A), SW26.2, SW26#2.2
unnamed: D27.2 (A), SW27.2, SW27#2.2
unnamed: D28.2 (A), SW28.2, SW28#2.2
unnamed: D29.2 (A), SW29.2, SW29#2.2
unnamed: D30.2 (A), SW30.2, SW30#2.2
unnamed: J3.1, JP4.1, JP8.1
unnamed: J3.2, JP3.1, JP7.1
unnamed: J3.3, JP2.1, JP6.1
unnamed: J3.4, JP1.1, JP5.1
RESET: RSW1.2, locked.22 (RST)
SCL: JP3.2, JP6.2, JP9.1, R2.2, locked.6 (SCL(PD0))
SDA: JP4.2, JP5.2, JP10.2, R1.2, locked.5 (SDA(PD1))
SW25A: SW1.1, SW1#2.1, SW7.1, SW7#2.1, SW13.1, SW13#2.1, SW19.1, SW19#2.1, SW25.S1, locked.13 (D10(PB6))
SW25B: D25.2 (A), SW25.S2
VCC: J1.1, J2.1, JP2.2, JP7.2, R1.1, R2.1, locked.21 (VCC)
col0: SW6.1, SW6#2.1, SW12.1, SW12#2.1, SW18.1, SW18#2.1, SW24.1, SW24#2.1, SW30.1, SW30#2.1, locked.18 (A1(PF6))
col1: SW5.1, SW5#2.1, SW11.1, SW11#2.1, SW17.1, SW17#2.1, SW23.1, SW23#2.1, SW29.1, SW29#2.1, locked.17 (A0(PF7))
col2: SW4.1, SW4#2.1, SW10.1, SW10#2.1, SW16.1, SW16#2.1, SW22.1, SW22#2.1, SW28.1, SW28#2.1, locked.16 (D15(PB1))
col3: SW3.1, SW3#2.1, SW9.1, SW9#2.1, SW15.1, SW15#2.1, SW21.1, SW21#2.1, SW27.1, SW27#2.1, locked.15 (D14(PB3))
col4: SW2.1, SW2#2.1, SW8.1, SW8#2.1, SW14.1, SW14#2.1, SW20.1, SW20#2.1, SW26.1, SW26#2.1, locked.14 (D16(PB2))
row0: D1.1 (K), D2.1 (K), D3.1 (K), D4.1 (K), D5.1 (K), D6.1 (K), locked.8 (D5(PC6))
row1: D7.1 (K), D8.1 (K), D9.1 (K), D10.1 (K), D11.1 (K), D12.1 (K), locked.9 (D6(PD7))
row2: D13.1 (K), D14.1 (K), D15.1 (K), D16.1 (K), D17.1 (K), D18.1 (K), locked.10 (D7(PE6))
row3: D19.1 (K), D20.1 (K), D21.1 (K), D22.1 (K), D23.1 (K), D24.1 (K), locked.11 (D8(PB4))
row4: D25.1 (K), D26.1 (K), D27.1 (K), D28.1 (K), D29.1 (K), D30.1 (K), locked.12 (D9(PB5))

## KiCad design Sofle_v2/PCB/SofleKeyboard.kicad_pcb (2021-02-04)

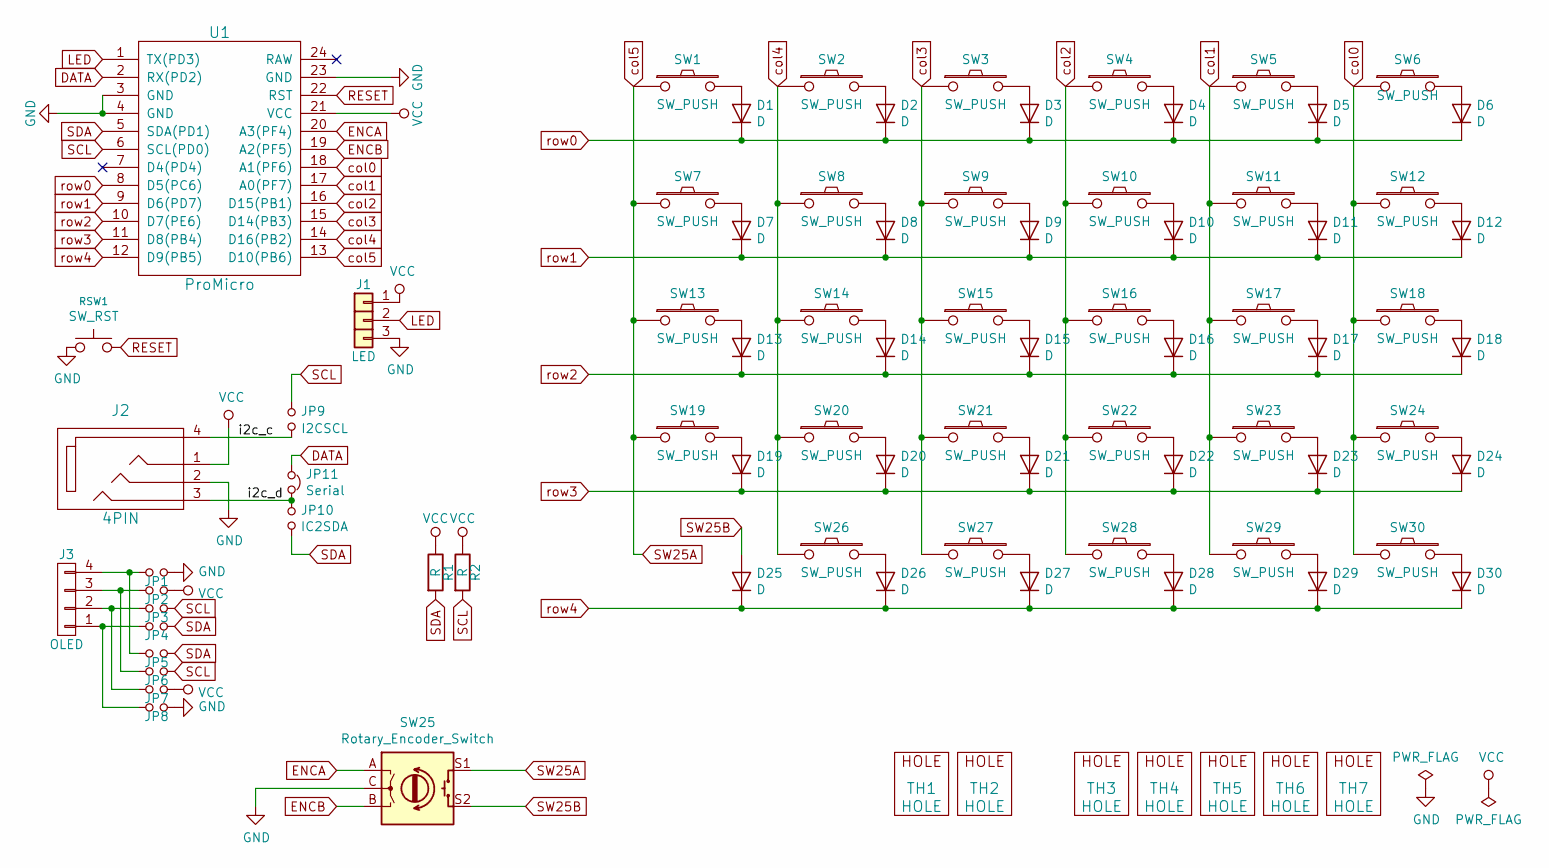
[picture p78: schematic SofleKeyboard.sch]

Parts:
D1, D2, D3, D4, D5, D6, D7, D8, D9, D10, D11, D12, D13, D14, D15, D16, D17, D18, D19, D20, D21, D22, D23, D24, D25, D26, D27, D28, D29, D30: D; Diode_SOD123
J1: LED
J2: 4PIN; MJ-4PP-9
J3: OLED; OLED_4Pin
JP1, JP2, JP3, JP4, JP5, JP6, JP7, JP8: Jumper_NO_Small; Jumper
JP9: I2CSCL; SolderJumper-2_P1.3mm_Open_TrianglePad1.0x1.5mm
JP10: IC2SDA; SolderJumper-2_P1.3mm_Open_TrianglePad1.0x1.5mm
JP11: Serial; SolderJumper-2_P1.3mm_Bridged2Bar_Pad1.0x1.5mm
R1, R2: R; R_1206_DoubleSided
RSW1: SW_RST; TACT_SWITCH_TVBP06
SW1, SW2, SW3, SW4, SW5, SW6, SW7, SW8, SW9, SW10, SW11, SW12, SW13, SW14, SW15, SW16, SW17, SW18, SW19, SW20, SW21, SW22, SW23, SW24, SW27, SW28, SW29, SW30: SW_PUSH; CherryMX_Hotswap
SW25: Rotary_Encoder_Switch; RotaryEncoder_Alps_EC11E-Switch_Vertical_H20mm-keebio_modif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
SW26: SW_PUSH; CherryMX_Hotswap_1.5
TH1, TH2: HOLE; M2_HOLE_PCB
TH3, TH4, TH5, TH6, TH7: HOLE; HOLE_M2_TH
U1: ProMicro; ArduinoProMicro-ZigZag-DoubleSided

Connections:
/i2c_c: J2.4, JP9.2
/i2c_d: J2.3, JP10.1, JP11.2
DATA: JP11.1, U1.2 (RX(PD2))
ENCA: SW25.A, U1.20 (A3(PF4))
ENCB: SW25.B, U1.19 (A2(PF5))
GND: J1.3, J2.2, JP1.2, JP8.2, RSW1.1, SW25.C, U1.3 (GND), U1.4 (GND), U1.23 (GND)
LED: J1.2, U1.1 (TX(PD3))
unnamed: D1.2 (A), SW1.2
unnamed: D2.2 (A), SW2.2
unnamed: D3.2 (A), SW3.2
unnamed: D4.2 (A), SW4.2
unnamed: D5.2 (A), SW5.2
unnamed: D6.2 (A), SW6.2
unnamed: D7.2 (A), SW7.2
unnamed: D8.2 (A), SW8.2
unnamed: D9.2 (A), SW9.2
unnamed: D10.2 (A), SW10.2
unnamed: D11.2 (A), SW11.2
unnamed: D12.2 (A), SW12.2
unnamed: D13.2 (A), SW13.2
unnamed: D14.2 (A), SW14.2
unnamed: D15.2 (A), SW15.2
unnamed: D16.2 (A), SW16.2
unnamed: D17.2 (A), SW17.2
unnamed: D18.2 (A), SW18.2
unnamed: D19.2 (A), SW19.2
unnamed: D20.2 (A), SW20.2
unnamed: D21.2 (A), SW21.2
unnamed: D22.2 (A), SW22.2
unnamed: D23.2 (A), SW23.2
unnamed: D24.2 (A), SW24.2
unnamed: D26.2 (A), SW26.2
unnamed: D27.2 (A), SW27.2
unnamed: D28.2 (A), SW28.2
unnamed: D29.2 (A), SW29.2
unnamed: D30.2 (A), SW30.2
unnamed: J3.1, JP4.1, JP8.1
unnamed: J3.2, JP3.1, JP7.1
unnamed: J3.3, JP2.1, JP6.1
unnamed: J3.4, JP1.1, JP5.1
RESET: RSW1.2, U1.22 (RST)
SCL: JP3.2, JP6.2, JP9.1, R2.2, U1.6 (SCL(PD0))
SDA: JP4.2, JP5.2, JP10.2, R1.2, U1.5 (SDA(PD1))
SW25A: SW1.1, SW7.1, SW13.1, SW19.1, SW25.S1, U1.13 (D10(PB6))
SW25B: D25.2 (A), SW25.S2
VCC: J1.1, J2.1, JP2.2, JP7.2, R1.1, R2.1, U1.21 (VCC)
col0: SW6.1, SW12.1, SW18.1, SW24.1, SW30.1, U1.18 (A1(PF6))
col1: SW5.1, SW11.1, SW17.1, SW23.1, SW29.1, U1.17 (A0(PF7))
col2: SW4.1, SW10.1, SW16.1, SW22.1, SW28.1, U1.16 (D15(PB1))
col3: SW3.1, SW9.1, SW15.1, SW21.1, SW27.1, U1.15 (D14(PB3))
col4: SW2.1, SW8.1, SW14.1, SW20.1, SW26.1, U1.14 (D16(PB2))
row0: D1.1 (K), D2.1 (K), D3.1 (K), D4.1 (K), D5.1 (K), D6.1 (K), U1.8 (D5(PC6))
row1: D7.1 (K), D8.1 (K), D9.1 (K), D10.1 (K), D11.1 (K), D12.1 (K), U1.9 (D6(PD7))
row2: D13.1 (K), D14.1 (K), D15.1 (K), D16.1 (K), D17.1 (K), D18.1 (K), U1.10 (D7(PE6))
row3: D19.1 (K), D20.1 (K), D21.1 (K), D22.1 (K), D23.1 (K), D24.1 (K), U1.11 (D8(PB4))
row4: D25.1 (K), D26.1 (K), D27.1 (K), D28.1 (K), D29.1 (K), D30.1 (K), U1.12 (D9(PB5))

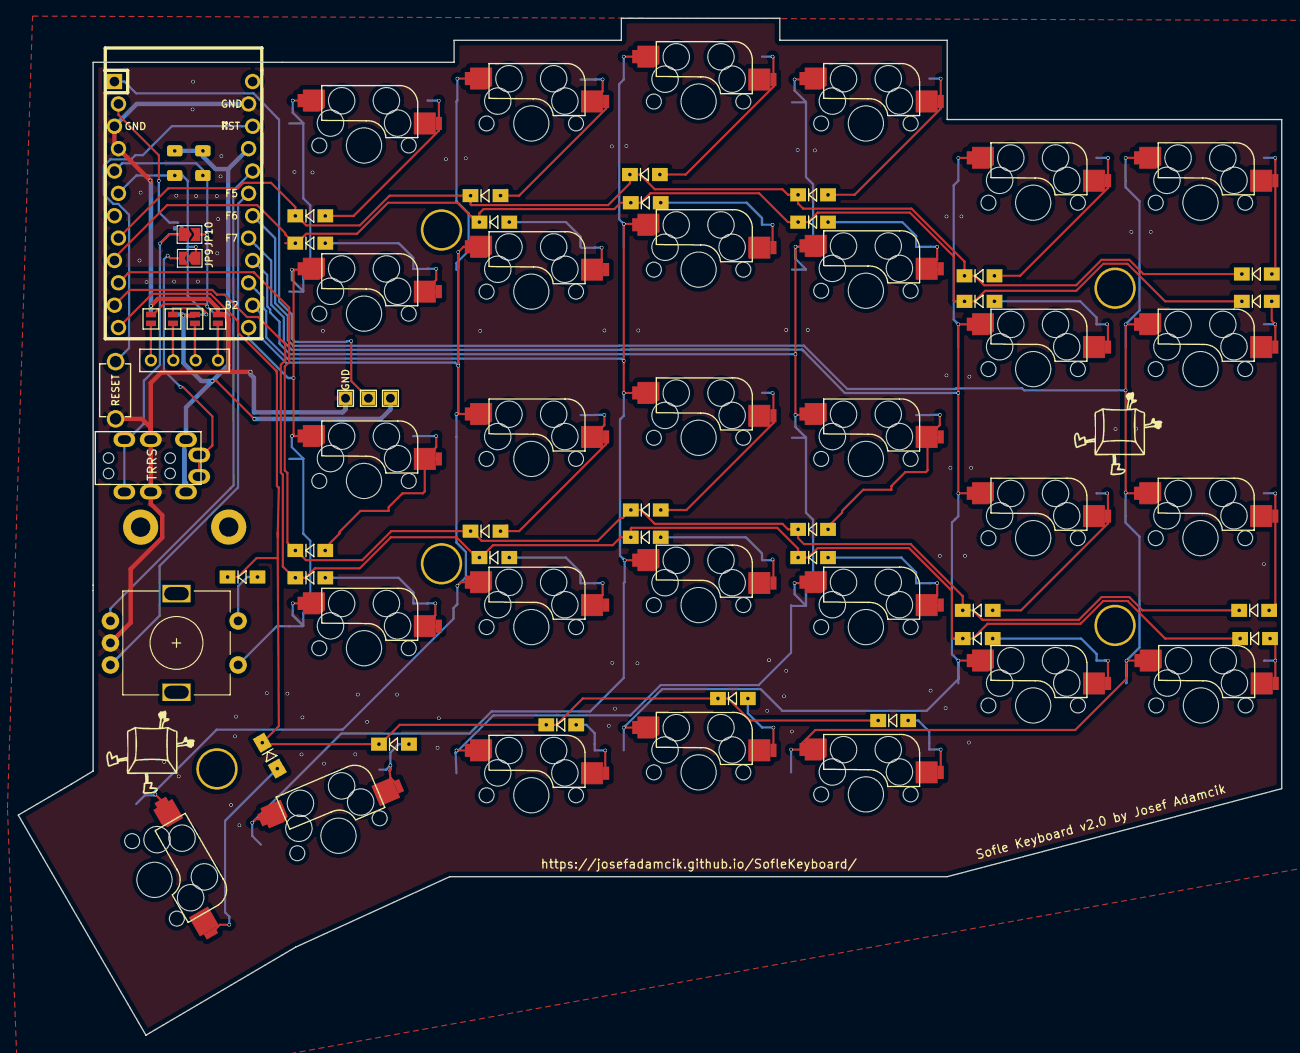
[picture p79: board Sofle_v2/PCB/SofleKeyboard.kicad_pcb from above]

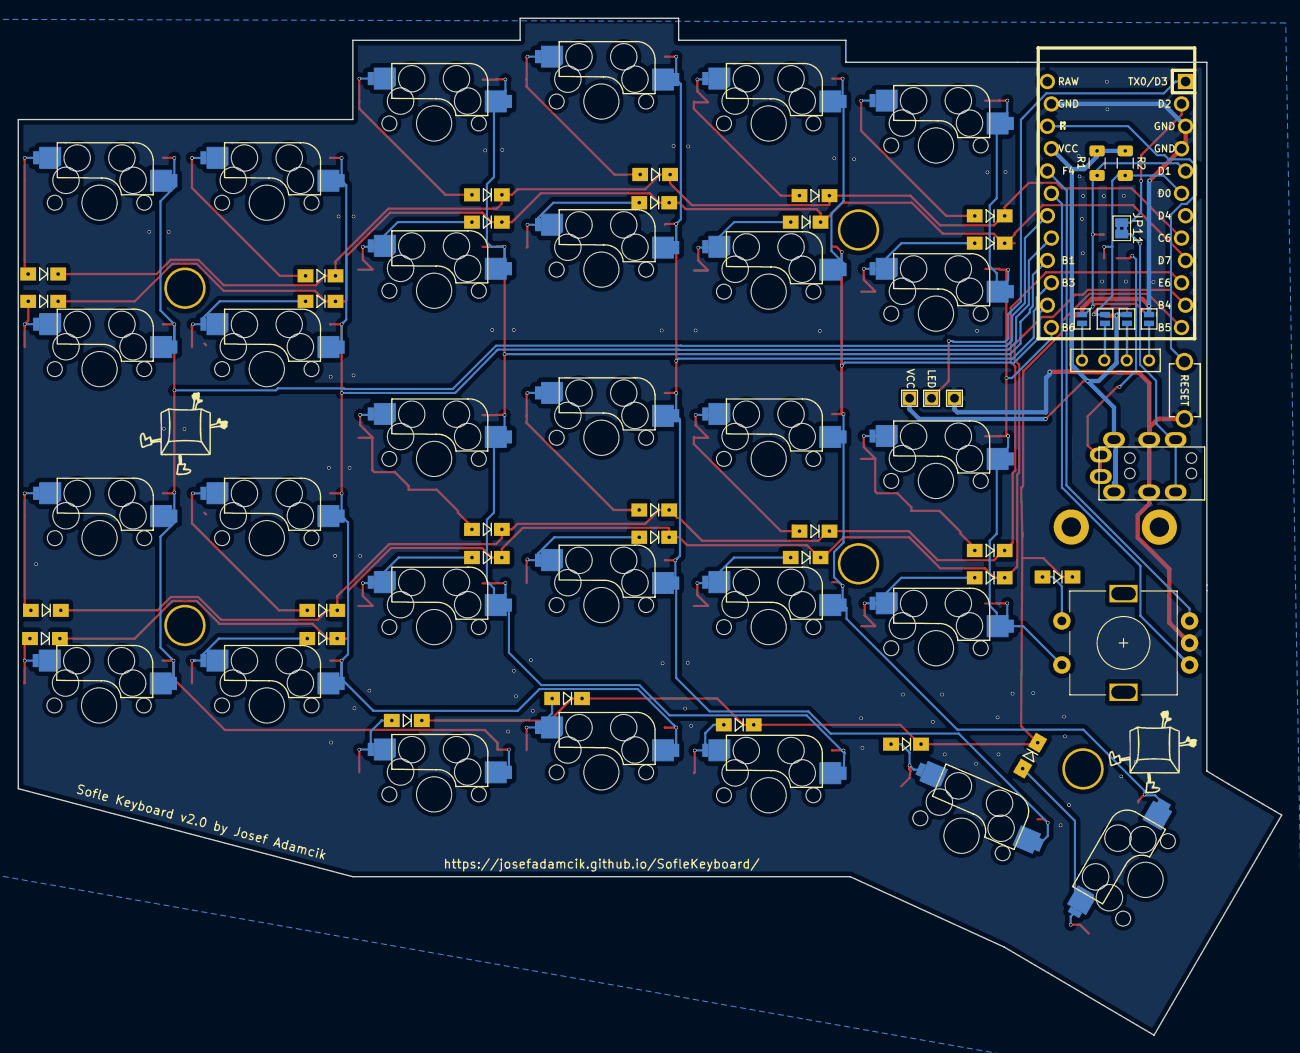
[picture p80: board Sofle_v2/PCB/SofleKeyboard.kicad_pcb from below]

Board: 2 copper layers, 143.5 x 115.5 mm, 89 parts (9 on the bottom side), 56 nets.

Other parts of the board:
Ref**: Val**; SofleLogoSmall
Ref**#2, Ref**#3, Ref**#4: Val**; SofleLogoSmall

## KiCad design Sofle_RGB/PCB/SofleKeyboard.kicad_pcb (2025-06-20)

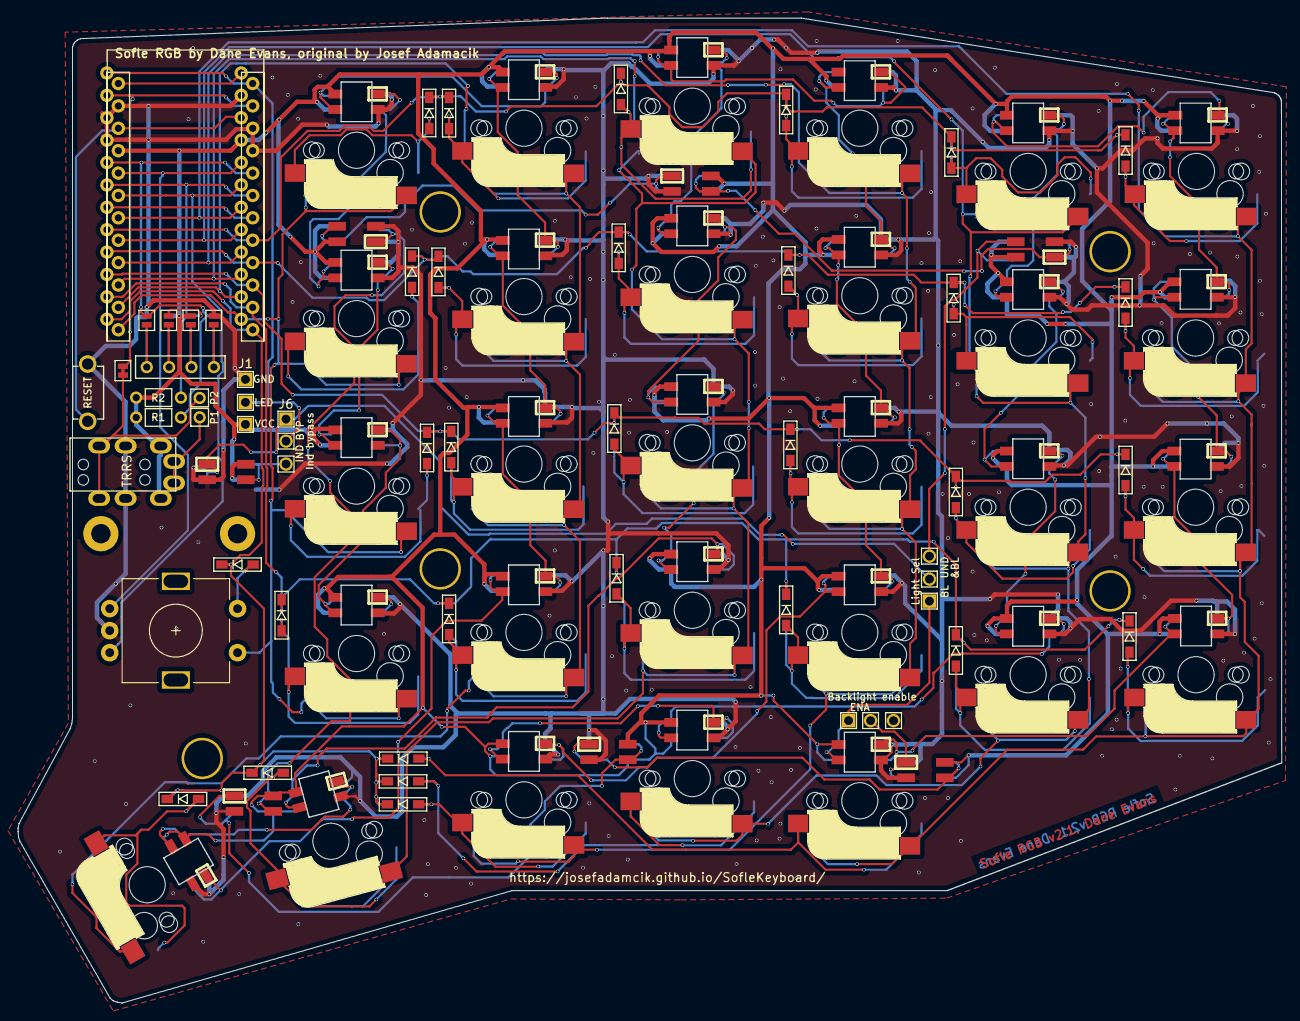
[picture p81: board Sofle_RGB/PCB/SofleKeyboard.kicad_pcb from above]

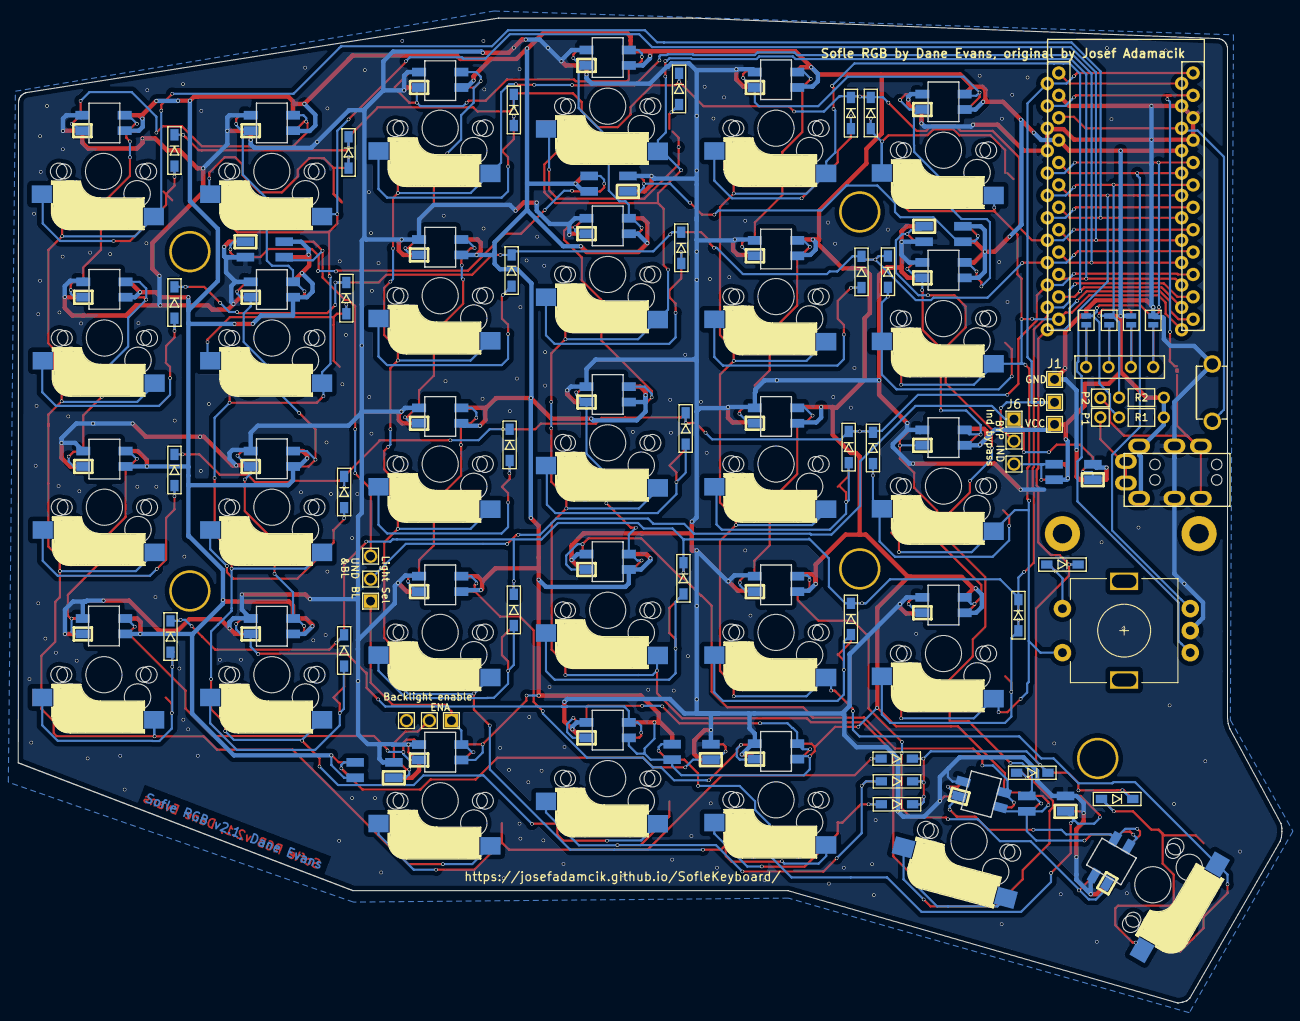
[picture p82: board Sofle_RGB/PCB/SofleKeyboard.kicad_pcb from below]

Board: 2 copper layers, 143.4 x 111.8 mm, 95 parts (4 on the bottom side), 94 nets.

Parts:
D1, D2, D3, D4, D5, D6, D7, D8, D9, D10, D11, D12, D13, D14, D15, D16, D17, D18, D19, D20, D21, D22, D23, D24, D25, D26, D27, D28, D29, D30: D; crkbd-diode
D31, D32, D33, D34, D35, D36, D37: LED_sk2812_SM; SK6812MINI_underglow_dev
J1: LED
J2: 4PIN; MJ-4PP-9
J3: OLED; OLED_4Pin
J4: key leds; 3x1header
J5: backlight sel; 3x1header
J6: indicator bypass; 3x1header
JP1, JP2, JP3, JP4, JP5, JP6, JP7, JP8: Jumper_NO_Small; Jumper
P1, P2: i2c_pin; 1pin_conn
R1, R2: R; RESISTOR_mini
RSW1: SW_RST; TACT_SWITCH_TVBP06
SW1, SW2, SW3, SW4, SW5, SW6, SW7, SW8, SW9, SW10, SW11, SW12, SW13, SW14, SW15, SW16, SW17, SW18, SW19, SW20, SW21, SW22, SW23, SW24, SW26, SW27, SW28, SW29, SW30: SW_PUSH-MX_W_LED; SK6812MINI_and_cherry
SW25: Rotary_Encoder_Switch; RotaryEncoder_Alps_EC11E-Switch_Vertical_H20mm-keebio_modif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
TH1, TH2: HOLE; M2_HOLE_PCB
TH3, TH4, TH5, TH6, TH7: HOLE; HOLE_M2_TH
U1: ProMicro
W1: jumper; jumper_data

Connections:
/backlight: J4.1, J5.1, SW30.3
/i2c_c: J2.4, P1.1
/i2c_d: J2.3, P2.1, W1.2
/underglow: D33.3, J4.3
DATA: U1.2, W1.1
ENCA: SW25.A, U1.20
ENCB: SW25.B, U1.19
GND: D31.2, D32.2, D33.2, D34.2, D35.2, D36.2, D37.2, J1.3, J2.2, JP1.2, JP8.2, RSW1.1, SW1.2, SW2.2, SW3.2, SW4.2, SW5.2, SW6.2, SW7.2, SW8.2, SW9.2, SW10.2, SW11.2, SW12.2, SW13.2, SW14.2, SW15.2, SW16.2, SW17.2, SW18.2, SW19.2, SW20.2, SW21.2, SW22.2, SW23.2, SW24.2, SW25.C, SW26.2, SW27.2, SW28.2, SW29.2, SW30.2, U1.3, U1.4, U1.23
LED: J1.2, J6.2, U1.1
unnamed: D1.2, SW1.5
unnamed: D2.2, SW2.5
unnamed: D3.2, SW3.5
unnamed: D4.2, SW4.5
unnamed: D5.2, SW5.5
unnamed: D6.2, SW6.5
unnamed: D7.2, SW7.5
unnamed: D8.2, SW8.5
unnamed: D9.2, SW9.5
unnamed: D10.2, SW10.5
unnamed: D11.2, SW11.5
unnamed: D12.2, SW12.5
unnamed: D13.2, SW13.5
unnamed: D14.2, SW14.5
unnamed: D15.2, SW15.5
unnamed: D16.2, SW16.5
unnamed: D17.2, SW17.5
unnamed: D18.2, SW18.5
unnamed: D19.2, SW19.5
unnamed: D20.2, SW20.5
unnamed: D21.2, SW21.5
unnamed: D22.2, SW22.5
unnamed: D23.2, SW23.5
unnamed: D24.2, SW24.5
unnamed: D26.2, SW26.5
unnamed: D27.2, SW27.5
unnamed: D28.2, SW28.5
unnamed: D29.2, SW29.5
unnamed: D30.2, SW30.5
unnamed: D31.1, D34.3
unnamed: D31.3, D32.1
unnamed: D32.3, D33.1
unnamed: D34.1, D35.3
unnamed: D35.1, D36.3
unnamed: D36.1, J5.2
unnamed: D37.3, J6.3
unnamed: J3.1, JP4.1, JP8.1
unnamed: J3.2, JP3.1, JP7.1
unnamed: J3.3, JP2.1, JP6.1
unnamed: J3.4, JP1.1, JP5.1
unnamed: SW1.1, SW7.3
unnamed: SW1.3, SW2.1
unnamed: SW2.3, SW8.1
unnamed: SW3.1, SW9.3
unnamed: SW3.3, SW4.1
unnamed: SW5.3, SW6.1
unnamed: SW4.3, SW10.1
unnamed: SW10.3, SW16.1
unnamed: SW11.1, SW17.3
unnamed: SW5.1, SW11.3
unnamed: SW6.3, SW12.1
unnamed: SW12.3, SW18.1
unnamed: SW13.1, SW19.3
unnamed: SW7.1, SW13.3
unnamed: SW8.3, SW14.1
unnamed: SW14.3, SW20.1
unnamed: SW15.1, SW21.3
unnamed: SW9.1, SW15.3
unnamed: SW16.3, SW22.1
unnamed: SW17.1, SW23.3
unnamed: SW18.3, SW24.1
unnamed: SW20.3, SW26.1
unnamed: SW21.1, SW27.3
unnamed: SW22.3, SW28.1
unnamed: SW23.1, SW29.3
unnamed: SW24.3, SW30.1
unnamed: SW26.3, SW27.1
unnamed: SW28.3, SW29.1
RESET: RSW1.2, U1.22
SCL: JP3.2, JP6.2, R2.2, U1.6
SDA: JP4.2, JP5.2, R1.2, U1.5
SW25A: SW1.6, SW7.6, SW13.6, SW19.6, SW25.S1, U1.13
SW25B: D25.2, SW25.S2
VCC: D31.4, D32.4, D33.4, D34.4, D35.4, D36.4, D37.4, J1.1, J2.1, JP2.2, JP7.2, R1.1, R2.1, SW1.4, SW2.4, SW3.4, SW4.4, SW5.4, SW6.4, SW7.4, SW8.4, SW9.4, SW10.4, SW11.4, SW12.4, SW13.4, SW14.4, SW15.4, SW16.4, SW17.4, SW18.4, SW19.4, SW20.4, SW21.4, SW22.4, SW23.4, SW24.4, SW26.4, SW27.4, SW28.4, SW29.4, SW30.4, U1.21
col0: SW6.6, SW12.6, SW18.6, SW24.6, SW30.6, U1.18
col1: SW5.6, SW11.6, SW17.6, SW23.6, SW29.6, U1.17
col2: SW4.6, SW10.6, SW16.6, SW22.6, SW28.6, U1.16
col3: SW3.6, SW9.6, SW15.6, SW21.6, SW27.6, U1.15
col4: SW2.6, SW8.6, SW14.6, SW20.6, SW26.6, U1.14
lights: D37.1, J4.2, J6.1
row0: D1.1, D2.1, D3.1, D4.1, D5.1, D6.1, U1.8
row1: D7.1, D8.1, D9.1, D10.1, D11.1, D12.1, U1.9
row2: D13.1, D14.1, D15.1, D16.1, D17.1, D18.1, U1.10
row3: D19.1, D20.1, D21.1, D22.1, D23.1, D24.1, U1.11
row4: D25.1, D26.1, D27.1, D28.1, D29.1, D30.1, U1.12

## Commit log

2019-09-28 Add PCB files
    [SofleKeyboard.kicad_pcb, SofleKeyboard.sch]
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2019-09-28 Add design files (SVG)
    [shape.dxf]
2019-09-28 Add name to the PCB
    [SofleKeyboard.kicad_pcb, SofleKeyboard.sch]
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2019-09-29 First top case version in kicad
    [SofleKeyboardTopPlate.kicad_pcb]
2019-09-29 Bottom case in kicad
    [SofleKeyboardBottomPlate.kicad_pcb, SofleKeyboardTopPlate.kicad_pcb]
2019-09-29 Small changes to the bottom and top plates
    [SofleKeyboardBottomPlate.kicad_pcb, SofleKeyboardTopPlate.kicad_pcb, shape.dxf]
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2019-09-29 Update the edge.cuts layer of the main pcb with current shape.
    [SofleKeyboard.kicad_pcb, shape.dxf]
2019-09-30 Add first version of logo
    [SofleKeyboardBottomPlate.kicad_pcb]
2019-10-14 Finish logo, add the logo and credits on the bottom plate
    [SofleKeyboardBottomPlate.kicad_pcb]
2019-10-14 Finish top case
    [SofleKeyboardBottomPlate.kicad_pcb, SofleKeyboardTopPlate.kicad_pcb]
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2019-10-14 Add a small logo to main pcb
    [SofleKeyboard.kicad_pcb]
2019-10-14 Small details.
    [SofleKeyboard.kicad_pcb]
2019-10-14 Add renders of PCB
    [SofleKeyboard.kicad_pcb]
2019-10-16 Finishing touches before ordering
    [SofleKeyboard.kicad_pcb, SofleKeyboardBottomPlate.kicad_pcb, SofleKeyboardTopPlate.kicad_pcb]
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2020-03-14 Fix cutout for encoder (too small for build with choc switches).
    [SofleKeyboardTopPlate.kicad_pcb]
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2020-03-16 Moving bottom row
    [SofleKeyboard.kicad_pcb]
2020-04-10 WIP changing the stagger
    [SofleKeyboard.kicad_pcb]
2020-04-10 Stagger changed, cleaning and fixing routing for keys
    [SofleKeyboard.kicad_pcb]
2020-04-10 Add footprints for MX only socketed switches. Use those switches on the board
    [SofleKeyboard.kicad_pcb, SofleKeyboard.sch]
2020-04-10 WIP routing micro
    [SofleKeyboard.kicad_pcb, SofleKeyboard.sch]
2020-04-11 WIP routing matrix
    [SofleKeyboard.kicad_pcb]
2020-04-11 Routing done, zones added.
    [SofleKeyboard.kicad_pcb]
2020-04-14 Add very rough Edge
    [SofleKeyboard.kicad_pcb]
2020-04-14 Add some 3d models to footprints
    [SofleKeyboard.kicad_pcb]
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2020-04-30 WIP - moving things more around
    [SofleKeyboard.kicad_pcb, SofleKeyboard.sch]
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2020-05-01 New shapes for top and bottom plates
    [SofleKeyboard-Eco2_User.dxf, SofleKeyboardBottomPlate.kicad_pcb, SofleKeyboardTopPlate.kicad_pcb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]
2020-05-04 Add logos and credits on all boards
    [SofleKeyboard.kicad_pcb, bottom_plate.kicad_pcb, top_plate.kicad_pcb]
2020-05-04 Small improvements to plates
    [SofleKeyboard.kicad_pcb, bottom_plate.kicad_pcb]
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2020-05-11 Fix missing soldermask on pcb
    [SofleKeyboard.kicad_pcb]
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2020-12-24 v2 sofle rgb v1 was tested with a few bugs, v2 ready for release but untested oled cover added for sofle / sofle rgb plates added for rgb, should be cross compatible, with tenting options pcb takes f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
    [SofleKeyboard.kicad_pcb, SofleKeyboard.sch, SofleKeyboardBottomPlate.kicad_pcb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]
2020-12-24 added Sofle RGB to upstream v2 including gerber release pcb files based on sofle v2 with up to 36 leds added plates for rgb version with tenting using m3/m4 bolts and thumb screws oled cover plate - 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
    [SofleKeyboard.kicad_pcb, SofleKeyboard.sch, SofleKeyboardTopPlate.kicad_pcb]
2021-01-16 Start changing the structure. Most of the files are only copied around Inso Sofle_v1 subdirectory. The structure update is going to be finished once this is merged with the develop branch
    [SofleKeyboard-B_Cu.gbl, SofleKeyboard-B_Mask.gbs, SofleKeyboard-B_SilkS.gbo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]
2021-01-16 Finish moving things around (each version has it's directory for pcb/case and design/gerbers)
    [SofleKeyboard-Eco2_User.dxf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]
2021-01-16 Add OLED cover for version 1
    [OLED_Cover.dxf]
2021-01-16 Enlarge cutout for encoder in the top plate for versin 2
    [top_plate.kicad_pcb]
2021-01-16 Generate gerber files for v2, remove raw gerbers from repository
    [SofleKeyboard-B_Cu.gbl, SofleKeyboard-B_Mask.gbs, SofleKeyboard-B_SilkS.gbo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]
2021-02-03 corrected LED part no. in the RGB build guide, now sk6812-mini
2021-02-04 Fix #34 - a mistake in the edge-cut layer of version 2, gerbers updated too
    [SofleKeyboard.kicad_pcb]
2021-02-27 fixed bug in v2.0, upversioned
    [SofleKeyboard.kicad_pcb]
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2021-04-07 Update build_guide_rgb.md
    Fix LED table issues, a few changes to layout, spelling mistakes and formatting while I was in here anyway
2021-04-08 Correct pin shorting table & add Clarification
2021-04-08 Fix diagram for LEDs
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2021-08-14 Fix traces too close to pads
    [SofleKeyboard.kicad_pcb]
2021-08-14 Bump to version 2.1
    [SofleKeyboard.kicad_pcb, SofleKeyboardTopPlate.kicad_pcb]
2021-08-14 Enlarge encoder cutout by 1mm
    [SofleKeyboardTopPlate.kicad_pcb]
2021-08-14 Better LED orientation marks
    [SofleKeyboard.kicad_pcb]
2021-08-14 Change PCB text to silkscreen for visibility
    [SofleKeyboard.kicad_pcb]
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2021-10-10 Remove version number from source files (use git instead)
    [SofleKeyboard.dsn, SofleKeyboard.kicad_pcb, SofleKeyboard.sch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]
2021-10-15 add 3D printable case
    [soflekeybaord-palm-L.stl, soflekeybaord-palm-r.stl]
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2021-10-16 replace brim with skirt from 3d print object palm_R.gcode
2021-11-14 add missing 3D case .stl files
    [soflekeyboard-case-L.stl, soflekeyboard-case-R.stl]
2021-11-14 adding lower plate files back in. I have no idea where or how they dissappeared
    [SofleKeyboardBottomPlate.kicad_pcb]
2021-11-19 adjust case for original sofle pcb
    [soflekeyboard-case-L.stl, soflekeyboard-case-R.stl]
2021-11-19 fix filename
    [soflekeyboard-palm-L.stl, soflekeyboard-palm-r.stl]
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2021-12-23 Move top plate version number to less visible location
    [SofleKeyboardTopPlate.kicad_pcb]
2021-12-23 Thicken top plate above encoder
    [SofleKeyboardTopPlate.kicad_pcb]
2021-12-23 Fix labels for the RGB connector.
    [SofleKeyboard.kicad_pcb]
2021-12-23 Cleaned and retraced some GND tracks.
    [SofleKeyboard.kicad_pcb]
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2022-04-20 Oled covers for Sofle V2
    [sofle_v2_oled_cover_0.1.dxf, sofle_v2_oled_cover_0.1.f3d, sofle_v2_oled_cover_0.1.step]
2022-07-28 add soldered PCB version
    [SofleKeyboard-B_Cu.gbl, SofleKeyboard-B_Mask.gbs, SofleKeyboard-B_Silkscreen.gbo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]
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2022-08-18 rename folders for layout indication
    [SofleKeyboard-B_Cu.gbl, SofleKeyboard-B_Mask.gbs, SofleKeyboard-B_Silkscreen.gbo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]
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2024-02-21 Added sofle pico core files Added sofle pico to jekyll navigation template
    [Sofle_Pico.dsn, Sofle_Pico.kicad_sch, Sofle_Pico.sch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]
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2025-06-20 Fix PCB file regression to v1. Gerbers were corret at v1.1
    [SofleKeyboardBottomPlate.kicad_pcb]
2025-06-20 fix gerber naming
